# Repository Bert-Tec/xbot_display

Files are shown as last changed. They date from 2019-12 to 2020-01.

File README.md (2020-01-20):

# xbot_display
This repository is about a additional OLED Display for electric scooters using xbot components like ESA 5000 1919 1950 ....

You can use an Arduino Uno for testing. For productive you should use someting smaller like an Arduino pro-mini or ESP-01(s).

For use of ESP-01 please enable it in the xbot_display.ino file, because of custom I2C pins.

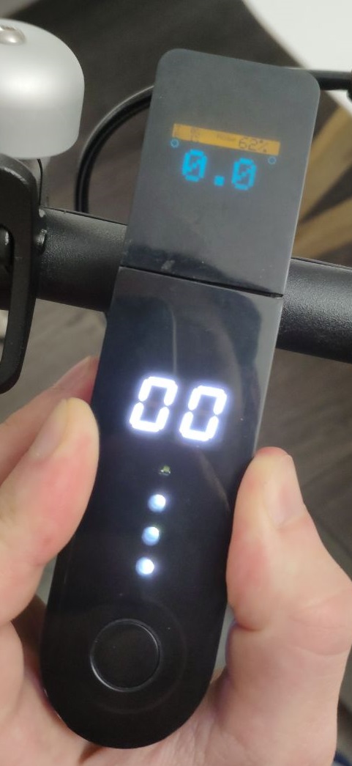
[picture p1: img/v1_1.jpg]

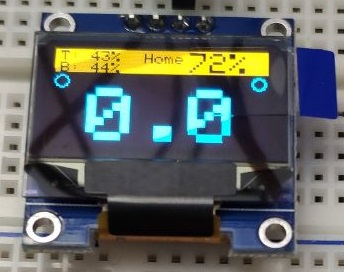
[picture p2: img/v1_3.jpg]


3D printed spacer which also puts the dashboard up, so that it looks good. And so you can secure the spacer with the screws of the dashboard(you'll need new M2x12 screws!):
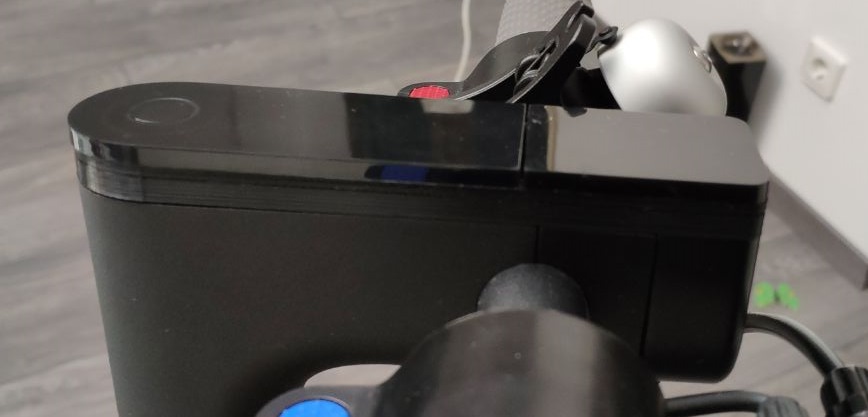
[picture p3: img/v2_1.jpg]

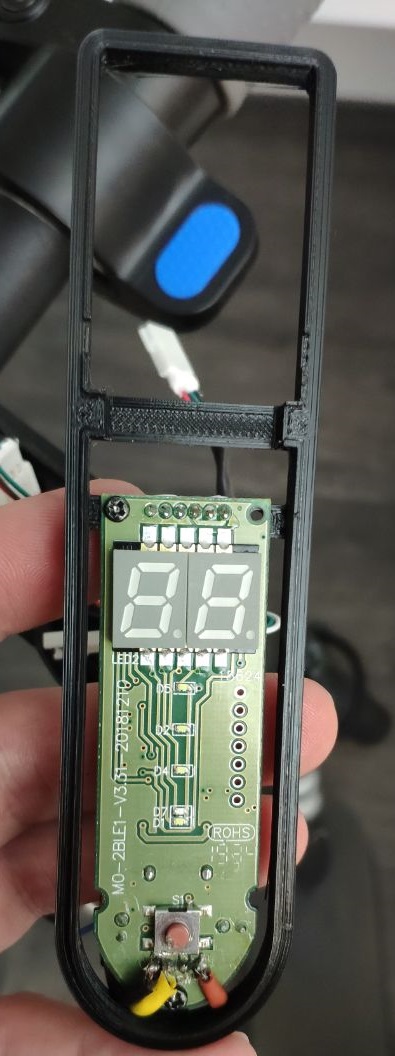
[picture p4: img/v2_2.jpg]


<h3>Dependencies (Arduino libraries):</h3>
<ul>
<li>Adafruit_GFX</li>
<li>Adafruit_SSD1306</li>
<li>Wire</li>
</ul>

<h3>Hardware needed:</h3>
<ul>
<li>1.3"(0.96"works also) OLED display (Yellow/Blue or White)</li>
<li>Arduino pro mini 5V OR ESP-01(s) AND 5V to 3.3V converter</li>
<li>Cables, isolation tape and a small resistor (like 220R)</li>
<li>3D printed spacer(see 3D folder, you'll need 3 new M2x12 screws to secure it well) or mod a housing on your own</li>
<li>optional some hot glue to hold stuff in place</li>
</ul>

<h3>How to connect:</h3>

You need to solder three wires to the dashboards lower pins. Power(5V) to the + pin, Ground to the - pin and the serial line to the tr pin. 
<br>
Then connect Arduino/ESP(you need a power converter from 5V to 3.3V for ESP) and Display to power and ground. 
<br>
Then connect serial line to RX pin of Arduino/ESP and using a resistor (for best work a diode) to TX.
<br>
Then connect I2C cables to OLED and I2C pins(SDA,SCL) of Arduino or to pin 0 and 2 of ESP.
<br>
Now turn on and test it.

<h3>How to Use:</h3>
The display and Arduino/ESP only gets power when the scooter is turned on.
<br>
You can switch to max. speed of 30 kmh by holding break and throttle for 7 seconds and at speed of 0. For reset hold break and throttle for 2 seconds and at speed of 0.
There are three different display mods at the moment. You can switch between them by pressing full throttle for 0.75 second at speed of 0:

<ul>
<li>Home (Displays throttle and break values in % on top left, Battery % in top right, speed in km/h in the center, left point is eco mode on/off right point is light on/off and the middle is 30km/h mode on/off)</li>
<li>Throttle overview (Here you can test and visualize throttle and break)</li>
<li>OFF (Displays blank screen)</li>
</ul>

<h3>Future Features:</h3>
<ul>
<li>Trip meter</li>
<li>unlock speed - done</li>
<li>view aditional informations</li>
</ul>

<h1>Disclaimer</h1>
Use on your own risk.
Not street legal in Germany!!!

<h3>Protocol informations:</h3>

Serial

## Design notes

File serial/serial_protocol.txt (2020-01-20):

General:
55 AA (Start of message) xx (length) xx (type) xx (command) xxxxxx xx (checksum2)  xx (checksum1)  
Length = command to end (without checksum)
xx = unknown
--------------------------------------------------------------------------------
Known stuff:

55 AA 07 25 60 xx xx throttle break xx xx ck2 ck1

55 AA 09 27 63 xx xx throttle break xx xx xx xx ck2 ck1

55 AA 0b 28 6d xx ECO batteryPoints light xx speed2 speed1 xx(?beep request) xx Battery% ck2 ck1

55 AA 04 22 01 xx maxWeehlspeed2 maxWeehlspeed1 ck2 ck1
55 AA 04 22 01 F2 F3 02 F1 FD --> 755 rpm = 30.60 kmh 
55 aa 04 22 01 F2 F8 01 ED FD --> 504 rpm = 20.43 kmh 

set eco mode on/off
                  01 = 0n 
55 AA 04 22 01 7C 01 00 5B FF
                  00 = 0ff 
55 AA 04 22 01 7C 00 00 5C FF

set lock mode on/off
                  01 = 0n 
55 AA 04 22 01 7D 01 00 5A FF
                  00 = 0ff 
55 AA 04 22 01 7D 00 00 5B FF

set light on/off
                  01 = 0n 
55 AA 04 22 01 F0 01 00 E7 FE
                  00 = 0ff 
55 AA 04 22 01 F0 00 00 E8 FE

two different messages, beginns with 55 AA 34 11 33 or 55 AA 34 11 33 28!!!
55 AA 34 11 33 00 93 6B 00 00 00 00 00 00 00 00 00 00 00 00 00 00 11 00 00 00 00 00 00 00 00 00 00 00 00 00 00 00 00 00 00 00 00 00 00 00 00 00 93 0E 18 00 00 00 00 00 BF FD
55 AA 34 11 33 t3 t2 t1 xx xx xx xx xx xx xx xx xx xx xx xx tx ty tz xx xx xx xx xx xx xx xx xx xx xx xx xx xx xx xx xx xx xx xx xx xx xx xx xx v2 v1 c2 c1 xx xx xx xx ck2 ck1
t1-3 = total time in s
tx-tz = actual time in s
v1-2 = /100 = voltage in V
c1-2 = /100 = current in A

55 AA 34 11 33 28 78 80 00 00 00 00 7D 02 03 00 00 00 00 00 00 00 3B 00 00 00 00 00 00 00 00 00 00 00 00 00 6F 41 00 00 00 00 00 00 00 00 00 00 00 00 00 00 00 00 D4 52 D4 FB 
55 AA 34 11 33 xx xx xx xx xx xx m4 m3 m2 m1 xx xx xx xx xx xx xx BB xx xx xx xx xx xx xx xx xx xx xx o4 o3 o2 o1 xx xx xx xx xx xx xx xx xx xx xx xx xx xx xx t3 t2 t1 ck2 ck1
m1-m4 = mainboard version
o1-o4 = odometer in meter
t1-3 = total time in s
BB = battery in %

-----------------------
Unknown stuf:

55 aa 07 25 64 1f 1c 03 28 28 00 e1 fe

55 aa 07 25 64 1f 1c 03 throttle break 00 e1 fe

55 AA 07 25 64 E9 10 03 28 28 00 23 FE 
55 AA 07 25 64 7E 12 03 28 28 00 8C FE 
55 AA 07 25 64 1F 1C 03 28 28 00 E1 FE 
55 AA 07 25 64 EA 0A 03 28 28 00 28 FE 

??? request 55 AA 34 11 33 messages
55 aa 03 23 00 31 18 90 ff
55 AA 03 23 00 31 18 90 FF

22 - set settings? 

set max rpm speed
55 AA 04 22 01 F2 DA 02 0A FE

eco mode on/off
                  01 = 0n 
55 AA 04 22 01 7C 01 00 5B FF
                  00 = 0ff 
55 AA 04 22 01 7C 00 00 5C FF

lock mode on/off
                  01 = 0n 
55 AA 04 22 01 7D 01 00 5A FF
                  00 = 0ff 
55 AA 04 22 01 7D 00 00 5B FF

light on/off
                  01 = 0n 
55 AA 04 22 01 F0 01 00 E7 FE
                  00 = 0ff 
55 AA 04 22 01 F0 00 00 E8 FE

-------------------------------------

21 - ?request data for info pages
55 AA 04 21 03 6A 80 04 E9 FE 
55 AA 04 21 03 EF 00 00 E8 FE --> allways 3x times with short distance

-------------------------------------

mostly at Start, maybe bluetooth connected/connect?
55 AA 06 F4 06 30 1C 81 18 B5 65 FD

-------------------------------------
mostly while check data in app 
55 AA 08 25 07 BD 6F 00 00 00 00 00 9F FE
55AA082507BD4D0000000000C1FE
55AA082507BD4E0000000000C0FE
55AA082507BD4F0000000000BFFE
55AA082507BD500000000000BEFE
55AA082507BD460000000000C8FE

-------------------------------------

55 AA 0A 2B 09 F8 F8 01 7A 01 00 00 20 4E E7 FC 
55 AA 0A 2B 09 F8 F3 02 7A 01 00 00 20 4E EB FC 

55 AA 0A 2B 09 F8 DA 02 7A 01 00 00 20 4E 04 FD 
55 AA 0A 2B 09 F8 F3 02 7A 01 00 00 20 4E EB FC 
55 AA 0A 2B 09 F8 FB 00 7A 01 00 00 20 4E E5 FC 
55 AA 0A 2B 09 F8 79 01 7A 01 00 00 20 4E 66 FD 
55 AA 0A 2B 09 F8 79 01 7A 01 00 00 20 4E 66 FD 
55 AA 0A 2B 09 F8 75 02 7A 01 00 00 20 4E 69 FD

-------------------------------------

55 AA 0C 29 0B 71 00 00 01 00 00 00 00 00 00 00 4D FF 
55 AA 0C 29 0B E5 00 00 F8 01 7A 01 00 00 20 4E F8 FC 
55 AA 0C 29 0B 71 00 00 01 00 00 00 00 00 00 00 4D FF 
55 AA 0C 29 0B E5 00 00 F8 01 7A 01 00 00 20 4E F8 FC 
55 AA 0C 29 0B E5 00 00 F8 01 7A 01 00 00 20 4E F8 FC 
55 AA 0C 29 0B 71 00 00 01 00 00 00 00 00 00 00 4D FF 
55 AA 0C 29 0B 71 00 00 01 00 00 00 01 00 00 00 4C FF 
55 AA 0C 29 0B 71 00 00 01 00 00 00 00 00 00 00 4D FF 
55 AA 0C 29 0B 71 00 00 01 00 00 00 00 00 00 00 4D FF 

-------------------------------------

                                          ????             20.000
55 AA 12 33 11 FC 00 00 00 00 E6 00 00 00 F8 01 7A 01 00 00 20 4E E5 FB 
55 AA 12 33 11 FC 00 00 00 00 E6 00 00 00 F8 01 7A 01 00 00 20 4E E5 FB 
55 AA 12 33 11 FC 00 00 00 00 E6 00 00 00 F8 01 7A 01 00 00 20 4E E5 FB 
55 AA 12 33 11 FC 00 00 00 00 E6 00 00 00 F8 01 7A 01 00 00 20 4E E5 FB 
55 AA 12 33 11 FC 00 00 00 00 E6 00 00 00 F8 01 7A 01 00 00 20 4E E5 FB 
55 AA 12 33 11 FC 00 00 00 00 E6 00 00 00 F3 02 7A 01 00 00 20 4E E9 FB 
55 AA 12 33 11 FC 00 00 00 00 E6 00 00 00 F3 02 7A 01 00 00 20 4E E9 FB 
55 AA 12 33 11 FC 00 00 00 00 E6 00 00 00 F8 01 7A 01 00 00 20 4E E5 FB 
55 AA 12 33 11 FC 00 00 00 00 E6 00 00 00 F3 02 7A 01 00 00 20 4E E9 FB 
55 AA 12 33 11 FC 00 00 00 00 E6 00 00 00 FB 00 7A 01 01 00 20 4E E2 FB
55 AA 12 33 11 FC 00 00 00 00 E6 00 00 00 FB 00 7A 01 00 00 20 4E E3 FB
55 AA 12 33 11 FC 00 00 00 00 E6 00 00 00 F3 02 7A 01 00 00 20 4E E9 FB

55 AA 12 33 11 FC 00 00 00 00 E6 00 00 00 F8 01 7A 01 00 00 20 4E E5 FB
55 AA 12 33 11 FC 00 00 00 00 E6 00 00 00 F3 02 7A 01 00 00 20 4E E9 FB 
55 AA 12 33 11 FC 00 00 00 00 E6 00 00 00 79 01 7A 01 00 00 20 4E 64 FC 
55 AA 12 33 11 FC 00 00 00 00 E6 00 00 00 75 02 7A 01 00 00 20 4E 67 FC
55 AA 12 33 11 FC 00 00 00 00 E6 00 00 00 F8 01 7A 01 00 00 68 42 A9 FB
55 AA 12 33 11 FC 00 00 00 00 E6 00 00 00 F8 01 7A 01 00 00 20 4E E5 FB

-------------------------------------

55 AA 14 31 13 69 00 00 01 00 00 00 00 00 00 00 00 00 78 80 00 00 00 00 45 FE 
55 AA 14 31 13 69 00 00 01 00 00 00 00 00 00 00 00 00 78 80 00 00 00 00 45 FE 
55 AA 14 31 13 69 00 00 01 00 00 00 00 00 00 00 00 00 78 80 00 00 00 00 45 FE 
55 AA 14 31 13 69 00 00 01 00 00 00 00 00 00 00 00 00 78 80 00 00 00 00 45 FE 
55 AA 14 31 13 69 00 00 01 00 00 00 00 00 00 00 00 00 78 80 00 00 00 00 45 FE 
55 AA 14 31 13 69 00 00 01 00 00 00 01 00 00 00 00 00 78 80 00 00 00 00 44 FE 

-------------------------------------
                                                                  akku?
55 AA 1E 3F 1D 06 78 80 00 00 00 00 7D 02 03 00 00 00 00 00 00 00 3B 00 00 00 00 00 00 00 00 00 00 00 CA FD 
55 AA 1E 3F 1D 06 78 80 00 00 00 00 7D 02 03 00 00 00 00 00 00 00 3B 00 00 00 00 00 00 00 00 00 00 00 CA FD 
55 AA 1E 3F 1D 06 78 80 00 00 00 00 7D 02 03 00 00 00 00 00 00 00 3C 00 00 00 00 00 00 00 00 00 00 00 C9 FD 

-------------------------------------

two different messages!!!

55 AA 34 11 33 t3 t2 t1 xx xx xx xx xx xx xx xx xx xx xx xx tx ty tz xx xx xx xx xx xx xx xx xx xx xx xx xx xx xx xx xx xx xx xx xx xx xx xx xx v2 v1 c2 c1 xx xx xx xx ck2 ck1
t1-3 = total time in s
tx-tz = actual time in s
v1-2 = /100 = voltage in V
c1-2 = /100 = current in A

55 AA 34 11 33 00 93 6B 00 00 00 00 00 00 00 00 00 00 00 00 00 00 11 00 00 00 00 00 00 00 00 00 00 00 00 00 00 00 00 00 00 00 00 00 00 00 00 00 93 0E 18 00 00 00 00 00 BF FD
55 AA 34 11 33 00 D3 52 00 00 00 00 00 00 00 00 00 00 00 00 00 00 1A 00 00 00 00 00 00 00 00 00 00 00 00 00 00 00 00 00 00 00 00 00 00 00 00 00 BA 0E 00 00 00 00 00 00 80 FD 
55 AA 34 11 33 00 D5 52 00 00 00 00 00 00 00 00 00 00 00 00 00 00 1C 00 00 00 00 00 00 00 00 00 00 00 00 00 00 00 00 00 00 00 00 00 00 00 00 00 BA 0E 01 00 00 00 00 00 7B FD 
55 AA 34 11 33 00 D4 52 00 00 00 00 00 00 00 00 00 00 00 00 00 00 1B 00 00 00 00 00 00 00 00 00 00 00 00 00 00 00 00 00 00 00 00 00 00 00 00 00 BA 0E 01 00 00 00 00 00 7D FD
55 AA 34 11 33 00 4F 6B 00 00 00 00 00 00 00 00 00 00 00 00 00 00 1B 00 00 00 00 00 00 00 00 00 00 00 00 00 00 00 00 00 00 00 00 00 00 00 00 00 93 0E 00 00 00 00 00 00 11 FE

55 AA 34 11 33 xx xx xx xx xx xx m4 m3 m2 m1 xx xx xx xx xx xx xx BB xx xx xx xx xx xx xx xx xx xx xx o4 o3 o2 o1 xx xx xx xx xx xx xx xx xx xx xx xx xx xx xx t3 t2 t1 ck2 ck1
m1-m4 = mainboard version
o1-o4 = odometer in meter
t1-3 = total time in s
BB = battery in %
                                    Mainboard                     akku                                    odometer
55 AA 34 11 33 28 78 80 00 00 00 00 7D 02 03 00 00 00 00 00 00 00 3B 00 00 00 00 00 00 00 00 00 00 00 00 00 6F 41 00 00 00 00 00 00 00 00 00 00 00 00 00 00 00 00 D4 52 D4 FB 
55 AA 34 11 33 28 78 80 00 00 00 00 7D 02 03 00 00 00 00 00 00 00 3B 00 00 00 00 00 00 00 00 00 00 00 00 00 6F 41 00 00 00 00 00 00 00 00 00 00 00 00 00 00 00 00 D3 52 D5 FB 
55 AA 34 11 33 28 78 80 00 00 00 00 7D 02 03 00 00 00 00 00 00 00 3B 00 00 00 00 00 00 00 00 00 00 00 00 00 6F 41 00 00 00 00 00 00 00 00 00 00 00 00 00 00 00 00 D5 52 D3 FB

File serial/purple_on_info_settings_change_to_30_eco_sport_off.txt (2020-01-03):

00003016	2020-01-03 18:38:55,7530478	+5,5502462	IRP_MJ_READ	UP	0x00000102	00 00 00 	...
00003018	2020-01-03 18:38:56,6466055	+0,8934269	IRP_MJ_READ	UP	0x00000102	ff 	.
00003020	2020-01-03 18:38:56,6666242	+0,0198825	IRP_MJ_READ	UP	0x00000102	55 aa 07 25 60 05 04 28 28 00 00 1a ff 	U..%`..((....
00003022	2020-01-03 18:38:56,6889862	+0,0222351	IRP_MJ_READ	UP	0x00000102	55 aa 07 25 60 05 04 28 f8 	U..%`..(.
00003024	2020-01-03 18:38:57,6042677	+0,9151669	IRP_MJ_READ	UP	0x00000102	55 aa 09 27 63 07 06 28 28 00 00 80 04 8b fe 	U..'c..((......
00003026	2020-01-03 18:38:57,6355090	+0,0311219	IRP_MJ_READ	UP	0x00000102	55 aa 07 25 60 05 04 28 28 00 00 1a ff 	U..%`..((....
00003028	2020-01-03 18:38:57,9248639	+0,2892538	IRP_MJ_READ	UP	0x00000102	94 09 00 1a ff 	.....
00003030	2020-01-03 18:38:57,9871611	+0,0621513	IRP_MJ_READ	UP	0x00000102	55 aa 09 27 63 07 06 28 28 00 00 80 04 8b fe 55 aa 07 25 60 …	U..'c..((......U..%`…
00003032	2020-01-03 18:38:58,0184054	+0,0311249	IRP_MJ_READ	UP	0x00000102	55 aa 07 25 60 05 04 28 28 00 00 1a ff 	U..%`..((....
00003034	2020-01-03 18:38:58,7481416	+0,7296258	IRP_MJ_READ	UP	0x00000102	f5 0b 28 6d 09 00 03 00 00 00 00 00 00 3b 18 ff 55 aa 07 25 …	..(m.........;..U..%…
00003036	2020-01-03 18:38:58,7734854	+0,0252202	IRP_MJ_READ	UP	0x00000102	55 aa 07 25 60 05 04 28 28 00 00 1a ff 	U..%`..((....
00003038	2020-01-03 18:38:58,7974907	+0,0239105	IRP_MJ_READ	UP	0x00000102	55 aa 07 25 60 05 04 28 28 00 00 1a ff 	U..%`..((....
00003040	2020-01-03 18:38:58,8421766	+0,0445723	IRP_MJ_READ	UP	0x00000102	55 aa 09 27 63 07 06 28 28 00 00 80 04 8b fe 55 aa 0b 28 6d …	U..'c..((......U..(m…
00003042	2020-01-03 18:38:58,8661759	+0,0239009	IRP_MJ_READ	UP	0x00000102	55 aa 07 25 60 05 04 28 28 00 00 1a ff 	U..%`..((....
00003044	2020-01-03 18:38:58,8901762	+0,0238960	IRP_MJ_READ	UP	0x00000102	55 aa 07 25 60 05 04 28 28 00 00 1a ff 	U..%`..((....
00003046	2020-01-03 18:38:59,8844301	+0,9941418	IRP_MJ_READ	UP	0x00000102	55 aa 07 25 60 ff 	U..%`.
00003048	2020-01-03 18:38:59,9758012	+0,0912508	IRP_MJ_READ	UP	0x00000102	94 09 00 1a ff 55 aa 0b 28 6d 09 00 03 00 00 00 00 00 00 3b …	.....U..(m.........;…
00003050	2020-01-03 18:39:00,0420099	+0,0660759	IRP_MJ_READ	UP	0x00000102	55 aa 07 25 60 05 04 28 28 00 00 1a ff 55 aa 09 27 63 07 06 …	U..%`..((....U..'c..…
00003052	2020-01-03 18:39:00,0751958	+0,0330779	IRP_MJ_READ	UP	0x00000102	55 aa 07 25 60 05 04 28 28 00 00 1a ff 	U..%`..((....
00003054	2020-01-03 18:39:01,2675521	+1,1922731	IRP_MJ_READ	UP	0x00000102	55 aa 0b 28 6d 09 00 03 00 00 00 00 00 00 3b 18 ff 55 aa 07 …	U..(m.........;..U..…
00003056	2020-01-03 18:39:01,4568222	+0,1891754	IRP_MJ_READ	UP	0x00000102	55 aa 07 25 60 05 04 28 28 00 00 1a ff 55 aa 07 25 60 05 04 …	U..%`..((....U..%`..…
00003058	2020-01-03 18:39:01,5718833	+0,1149814	IRP_MJ_READ	UP	0x00000102	55 aa 07 25 60 05 04 28 28 00 00 1a ff 55 aa 07 25 60 05 04 …	U..%`..((....U..%`..…
00003060	2020-01-03 18:39:01,6567012	+0,0847076	IRP_MJ_READ	UP	0x00000102	55 aa 07 25 60 05 04 28 28 00 00 1a ff 55 aa 07 25 60 05 04 …	U..%`..((....U..%`..…
00003062	2020-01-03 18:39:02,3616581	+0,7048353	IRP_MJ_READ	UP	0x00000102	55 aa 07 25 60 05 04 28 28 00 00 1a ff 55 aa 0b 28 6d 09 00 …	U..%`..((....U..(m..…
00003064	2020-01-03 18:39:02,4084642	+0,0466933	IRP_MJ_READ	UP	0x00000102	55 aa 07 25 60 05 04 28 28 00 00 1a ff 55 aa 09 27 63 07 06 …	U..%`..((....U..'c..…
00003066	2020-01-03 18:39:03,2716396	+0,8631149	IRP_MJ_READ	UP	0x00000102	55 aa 07 25 60 05 04 28 28 00 00 1a ff 	U..%`..((....
00003068	2020-01-03 18:39:03,3704131	+0,0986633	IRP_MJ_READ	UP	0x00000102	55 aa 07 25 60 05 04 28 28 00 00 1a ff 55 aa 0b 28 6d 09 00 …	U..%`..((....U..(m..…
00003070	2020-01-03 18:39:03,7474326	+0,3769105	IRP_MJ_READ	UP	0x00000102	55 aa 07 25 60 05 04 28 28 00 00 1a ff 	U..%`..((....
00003072	2020-01-03 18:39:03,8418210	+0,0942863	IRP_MJ_READ	UP	0x00000102	42 d2 1d 06 28 28 00 00 80 04 8b fe 	B...((......
00003074	2020-01-03 18:39:03,8658208	+0,0238807	IRP_MJ_READ	UP	0x00000102	55 fa 95 60 05 04 28 28 00 00 1a ff 	U..`..((....
00003076	2020-01-03 18:39:05,2085827	+1,3426681	IRP_MJ_READ	UP	0x00000102	55 aa 0b 28 6d 09 00 03 00 00 00 00 00 00 3b 18 ff 55 aa 07 …	U..(m.........;..U..…
00003078	2020-01-03 18:39:05,2610539	+0,0523561	IRP_MJ_READ	UP	0x00000102	55 aa 07 25 60 05 04 28 28 00 00 1a ff 55 b5 50 12 15 04 28 …	U..%`..((....U.P...(…
00003080	2020-01-03 18:39:05,2960023	+0,0347389	IRP_MJ_READ	UP	0x00000102	55 aa 09 27 63 07 06 28 28 00 00 80 04 8b fe 	U..'c..((......
00003082	2020-01-03 18:39:05,5417760	+0,2456743	IRP_MJ_READ	UP	0x00000102	11 28 28 00 00 1a ff 	.((....
00003084	2020-01-03 18:39:05,5684034	+0,0265095	IRP_MJ_READ	UP	0x00000102	55 aa 07 25 60 05 04 28 28 00 00 1a ff 	U..%`..((....
00003086	2020-01-03 18:39:05,6004034	+0,0319116	IRP_MJ_READ	UP	0x00000102	55 aa 07 25 60 05 04 28 28 00 00 1a ff 55 aa 0b 28 6d 09 00 …	U..%`..((....U..(m..…
00003088	2020-01-03 18:39:05,6217296	+0,0212152	IRP_MJ_READ	UP	0x00000102	55 aa 07 25 60 05 04 28 28 00 00 1a ff 	U..%`..((....
00003090	2020-01-03 18:39:05,7097330	+0,0879145	IRP_MJ_READ	UP	0x00000102	55 aa 07 25 60 05 04 28 28 00 00 1a ff 55 aa 0b 28 6d 09 00 …	U..%`..((....U..(m..…
00003092	2020-01-03 18:39:05,7337301	+0,0238884	IRP_MJ_READ	UP	0x00000102	55 aa 07 25 60 05 04 28 28 00 00 1a ff 	U..%`..((....
00003094	2020-01-03 18:39:05,7990815	+0,0652364	IRP_MJ_READ	UP	0x00000102	55 aa 07 25 60 05 04 28 28 00 00 1a ff 55 aa 0b 28 6d 09 00 …	U..%`..((....U..(m..…
00003096	2020-01-03 18:39:05,8310837	+0,0318768	IRP_MJ_READ	UP	0x00000102	55 aa 07 25 60 05 04 28 28 00 00 1a ff 	U..%`..((....
00003098	2020-01-03 18:39:05,8564621	+0,0252556	IRP_MJ_READ	UP	0x00000102	55 aa 07 25 60 fd 	U..%`.
00003100	2020-01-03 18:39:05,9044740	+0,0478971	IRP_MJ_READ	UP	0x00000102	55 aa 09 27 63 07 06 28 28 00 00 80 04 8b fe 55 aa 0b 28 6d …	U..'c..((......U..(m…
00003102	2020-01-03 18:39:05,9241376	+0,0195553	IRP_MJ_READ	UP	0x00000102	55 aa 07 25 60 05 04 28 28 00 00 1a ff 	U..%`..((....
00003104	2020-01-03 18:39:05,9494252	+0,0251825	IRP_MJ_READ	UP	0x00000102	55 aa 07 25 60 05 04 28 28 00 00 1a ff 	U..%`..((....
00003106	2020-01-03 18:39:05,9734376	+0,0238985	IRP_MJ_READ	UP	0x00000102	55 aa 07 25 60 05 04 28 28 00 00 1a ff 	U..%`..((....
00003108	2020-01-03 18:39:05,9974257	+0,0238807	IRP_MJ_READ	UP	0x00000102	55 aa 09 27 e3 	U..'.
00003110	2020-01-03 18:39:06,1661404	+0,1686121	IRP_MJ_READ	UP	0x00000102	55 aa 07 25 60 05 04 28 28 00 00 1a ff 	U..%`..((....
00003112	2020-01-03 18:39:06,1861357	+0,0198945	IRP_MJ_READ	UP	0x00000102	fd 	.
00003114	2020-01-03 18:39:06,2846020	+0,0983755	IRP_MJ_READ	UP	0x00000102	55 aa 07 25 60 05 04 28 28 00 00 1a ff 	U..%`..((....
00003116	2020-01-03 18:39:06,3086011	+0,0238742	IRP_MJ_READ	UP	0x00000102	55 aa 07 25 60 05 04 28 28 00 00 1a ff 	U..%`..((....
00003118	2020-01-03 18:39:06,3326012	+0,0238956	IRP_MJ_READ	UP	0x00000102	55 aa 07 25 60 05 04 28 28 00 00 1a ff 	U..%`..((....
00003120	2020-01-03 18:39:06,3566008	+0,0238997	IRP_MJ_READ	UP	0x00000102	55 aa 09 27 63 07 06 28 28 00 00 80 04 8b fe 	U..'c..((......
00003122	2020-01-03 18:39:06,7922088	+0,4355051	IRP_MJ_READ	UP	0x00000102	55 aa 07 25 60 05 04 28 28 00 00 1a ff 55 aa 0b 28 6d 09 00 …	U..%`..((....U..(m..…
00003124	2020-01-03 18:39:06,8122083	+0,0198766	IRP_MJ_READ	UP	0x00000102	55 aa 07 25 60 05 04 28 28 00 00 1a ff 	U..%`..((....
00003126	2020-01-03 18:39:06,9581673	+0,1458533	IRP_MJ_READ	UP	0x00000102	55 aa 09 27 63 07 06 28 28 00 00 80 04 8b fe 	U..'c..((......
00003128	2020-01-03 18:39:06,9999493	+0,0416488	IRP_MJ_READ	UP	0x00000102	55 ba 07 25 60 05 04 28 28 00 00 1a ff 00 03 00 00 00 00 00 …	U..%`..((...........…
00003130	2020-01-03 18:39:07,0239440	+0,0238848	IRP_MJ_READ	UP	0x00000102	55 aa 07 25 60 05 04 28 28 00 00 1a ff 	U..%`..((....
00003132	2020-01-03 18:39:07,0519083	+0,0278732	IRP_MJ_READ	UP	0x00000102	55 aa 07 25 60 05 04 28 28 00 00 1a ff 	U..%`..((....
00003134	2020-01-03 18:39:07,1460535	+0,0940569	IRP_MJ_READ	UP	0x00000102	55 aa 09 27 63 07 06 28 28 00 00 80 04 8b fe 55 aa 0b 28 6d …	U..'c..((......U..(m…
00003136	2020-01-03 18:39:07,1795096	+0,0333511	IRP_MJ_READ	UP	0x00000102	55 aa 07 25 60 05 04 28 28 00 00 1a ff 	U..%`..((....
00003138	2020-01-03 18:39:07,2656815	+0,0860802	IRP_MJ_READ	UP	0x00000102	55 aa 09 27 63 07 06 28 28 00 00 80 04 8b fe 55 aa 0b 28 6d …	U..'c..((......U..(m…
00003140	2020-01-03 18:39:07,3451350	+0,0793501	IRP_MJ_READ	UP	0x00000102	55 aa 07 25 60 05 04 28 28 00 00 1a ff 55 aa 0b 28 6d 09 00 …	U..%`..((....U..(m..…
00003142	2020-01-03 18:39:07,3763816	+0,0311152	IRP_MJ_READ	UP	0x00000102	55 aa 07 25 60 05 04 28 28 00 00 1a ff 	U..%`..((....
00003144	2020-01-03 18:39:07,4319363	+0,0554601	IRP_MJ_READ	UP	0x00000102	f5 	.
00003146	2020-01-03 18:39:07,4559314	+0,0238875	IRP_MJ_READ	UP	0x00000102	55 aa ff 	U..
00003148	2020-01-03 18:39:07,4800252	+0,0240060	IRP_MJ_READ	UP	0x00000102	60 05 04 28 28 00 00 1a ff 	`..((....
00003150	2020-01-03 18:39:07,5292428	+0,0491493	IRP_MJ_READ	UP	0x00000102	f5 07 25 60 05 04 28 28 00 00 1a ff 	..%`..((....
00003152	2020-01-03 18:39:07,5547197	+0,0253659	IRP_MJ_READ	UP	0x00000102	55 aa 09 27 63 07 06 28 28 00 00 80 04 8b fe 	U..'c..((......
00003154	2020-01-03 18:39:07,5737388	+0,0189219	IRP_MJ_READ	UP	0x00000102	55 aa 07 25 60 05 04 28 28 00 00 1a ff 	U..%`..((....
00003156	2020-01-03 18:39:07,6004782	+0,0266519	IRP_MJ_READ	UP	0x00000102	28 28 00 00 1a ff 	((....
00003158	2020-01-03 18:39:07,6257812	+0,0252180	IRP_MJ_READ	UP	0x00000102	55 aa 07 25 60 05 04 28 28 00 00 1a ff 	U..%`..((....
00003160	2020-01-03 18:39:07,6497807	+0,0238953	IRP_MJ_READ	UP	0x00000102	55 aa 07 25 60 05 04 28 28 00 00 1a ff 	U..%`..((....
00003162	2020-01-03 18:39:07,6977849	+0,0479048	IRP_MJ_READ	UP	0x00000102	55 aa 09 27 63 07 06 28 28 00 00 80 04 8b fe 55 aa 0b 28 6d …	U..'c..((......U..(m…
00003164	2020-01-03 18:39:07,7189718	+0,0210763	IRP_MJ_READ	UP	0x00000102	55 aa 07 25 60 05 04 28 28 00 00 1a ff 	U..%`..((....
00003166	2020-01-03 18:39:07,7429689	+0,0238918	IRP_MJ_READ	UP	0x00000102	55 aa 07 25 60 05 04 28 28 00 00 1a ff 	U..%`..((....
00003168	2020-01-03 18:39:07,7669684	+0,0238978	IRP_MJ_READ	UP	0x00000102	55 aa 07 25 60 05 04 28 28 00 00 1a ff 	U..%`..((....
00003170	2020-01-03 18:39:07,8163099	+0,0492481	IRP_MJ_READ	UP	0x00000102	55 aa 09 27 63 07 06 28 28 00 00 80 04 8b fe 55 aa 0b 28 6d …	U..'c..((......U..(m…
00003172	2020-01-03 18:39:07,8403095	+0,0238890	IRP_MJ_READ	UP	0x00000102	55 aa 07 25 60 05 04 28 28 00 00 1a ff 	U..%`..((....
00003174	2020-01-03 18:39:07,8603099	+0,0198974	IRP_MJ_READ	UP	0x00000102	22 28 28 00 00 1a ff 	"((....
00003176	2020-01-03 18:39:07,8963111	+0,0359042	IRP_MJ_READ	UP	0x00000102	55 aa 07 25 60 05 04 28 28 00 00 1a ff 55 aa 0b 28 6d 09 00 …	U..%`..((....U..(m..…
00003178	2020-01-03 18:39:07,9123100	+0,0158915	IRP_MJ_READ	UP	0x00000102	55 aa 09 27 63 07 06 28 28 00 00 80 04 8b fe 	U..'c..((......
00003180	2020-01-03 18:39:07,9363140	+0,0239031	IRP_MJ_READ	UP	0x00000102	55 aa 07 25 60 05 04 28 28 00 00 1a ff 	U..%`..((....
00003182	2020-01-03 18:39:07,9923107	+0,0559047	IRP_MJ_READ	UP	0x00000102	09 00 03 00 00 00 00 00 00 3b 18 ff 	.........;..
00003184	2020-01-03 18:39:08,0083007	+0,0158960	IRP_MJ_READ	UP	0x00000102	55 aa 07 25 60 05 04 28 28 00 00 1a ff 	U..%`..((....
00003186	2020-01-03 18:39:08,0305351	+0,0221663	IRP_MJ_READ	UP	0x00000102	55 aa 09 27 63 07 06 28 28 00 00 80 04 8b fe 	U..'c..((......
00003188	2020-01-03 18:39:08,0518322	+0,0211412	IRP_MJ_READ	UP	0x00000102	55 aa 07 25 60 05 04 28 28 00 00 1a ff 	U..%`..((....
00003190	2020-01-03 18:39:08,1041353	+0,0522055	IRP_MJ_READ	UP	0x00000102	55 aa 07 25 60 05 04 28 28 00 00 1a ff 55 aa 0b 28 6d 09 00 …	U..%`..((....U..(m..…
00003192	2020-01-03 18:39:08,1281412	+0,0239020	IRP_MJ_READ	UP	0x00000102	f5 50 12 15 04 28 28 00 00 1a ff 	.P...((....
00003194	2020-01-03 18:39:08,1467192	+0,0184898	IRP_MJ_READ	UP	0x00000102	55 aa 09 27 63 07 06 28 28 00 00 80 04 8b fe 	U..'c..((......
00003196	2020-01-03 18:39:08,1970160	+0,0501960	IRP_MJ_READ	UP	0x00000102	55 aa 07 25 60 05 04 28 28 00 00 1a ff fd ff 0b 28 6d 09 00 …	U..%`..((.......(m..…
00003198	2020-01-03 18:39:08,2210172	+0,0239056	IRP_MJ_READ	UP	0x00000102	55 aa 07 25 60 05 04 28 28 00 00 1a ff 	U..%`..((....
00003200	2020-01-03 18:39:08,2474148	+0,0263078	IRP_MJ_READ	UP	0x00000102	55 aa 07 25 60 05 04 28 28 00 00 1a ff 	U..%`..((....
00003202	2020-01-03 18:39:08,2727729	+0,0252514	IRP_MJ_READ	UP	0x00000102	55 aa 09 27 63 07 06 28 28 00 00 80 04 8b fe 	U..'c..((......
00003204	2020-01-03 18:39:08,3179761	+0,0451028	IRP_MJ_READ	UP	0x00000102	55 aa 07 25 60 05 04 28 28 00 00 1a ff 	U..%`..((....
00003206	2020-01-03 18:39:08,3419574	+0,0238783	IRP_MJ_READ	UP	0x00000102	55 aa 07 25 60 05 04 28 28 00 00 1a ff 	U..%`..((....
00003208	2020-01-03 18:39:08,3659595	+0,0239055	IRP_MJ_READ	UP	0x00000102	55 aa 07 25 60 05 04 28 28 00 00 1a ff 	U..%`..((....
00003210	2020-01-03 18:39:08,4163022	+0,0502428	IRP_MJ_READ	UP	0x00000102	55 aa 09 27 63 07 06 28 28 00 00 80 04 8b fe 55 aa 0b 28 6d …	U..'c..((......U..(m…
00003212	2020-01-03 18:39:08,7952695	+0,3788618	IRP_MJ_READ	UP	0x00000102	55 aa 07 25 60 05 04 28 28 00 00 1a ff 	U..%`..((....
00003214	2020-01-03 18:39:08,8192732	+0,0238914	IRP_MJ_READ	UP	0x00000102	55 aa 07 25 60 05 04 28 28 00 00 1a ff 	U..%`..((....
00003216	2020-01-03 18:39:08,8430030	+0,0236309	IRP_MJ_READ	UP	0x00000102	55 aa 07 25 e0 05 04 28 28 00 00 1a ff 	U..%...((....
00003218	2020-01-03 18:39:08,8671536	+0,0240717	IRP_MJ_READ	UP	0x00000102	55 aa 09 27 63 07 06 28 28 00 00 80 	U..'c..((...
00003220	2020-01-03 18:39:08,8894693	+0,0222062	IRP_MJ_READ	UP	0x00000102	10 09 09 00 1a ff 	......
00003222	2020-01-03 18:39:08,9134673	+0,0239003	IRP_MJ_READ	UP	0x00000102	55 aa 07 25 60 05 04 28 28 00 00 1a ff 	U..%`..((....
00003224	2020-01-03 18:39:08,9374676	+0,0239022	IRP_MJ_READ	UP	0x00000102	55 aa 07 25 60 05 04 28 28 00 00 1a ff 	U..%`..((....
00003226	2020-01-03 18:39:08,9647137	+0,0271540	IRP_MJ_READ	UP	0x00000102	55 aa 07 25 60 05 04 28 28 00 00 1a ff 	U..%`..((....
00003228	2020-01-03 18:39:09,0106131	+0,0458249	IRP_MJ_READ	UP	0x00000102	55 aa 09 27 63 07 06 28 28 00 00 80 04 8b fe 55 aa 0b 28 6d …	U..'c..((......U..(m…
00003230	2020-01-03 18:39:09,0321296	+0,0214135	IRP_MJ_READ	UP	0x00000102	b0 41 10 09 09 00 1a ff 	.A......
00003232	2020-01-03 18:39:09,0568022	+0,0245763	IRP_MJ_READ	UP	0x00000102	55 aa 07 25 60 05 04 28 28 00 00 1a ff 	U..%`..((....
00003234	2020-01-03 18:39:09,1163887	+0,0594780	IRP_MJ_READ	UP	0x00000102	55 aa 07 25 60 05 04 28 28 00 00 1a ff 55 aa 0b 28 6d 09 00 …	U..%`..((....U..(m..…
00003236	2020-01-03 18:39:09,1822177	+0,0657242	IRP_MJ_READ	UP	0x00000102	55 ea 60 05 04 28 28 00 00 1a ff 	U.`..((....
00003238	2020-01-03 18:39:09,2529186	+0,0705922	IRP_MJ_READ	UP	0x00000102	fd 55 aa 07 25 60 05 04 28 28 00 00 1a ff 	.U..%`..((....
00003240	2020-01-03 18:39:09,2858038	+0,0327810	IRP_MJ_READ	UP	0x00000102	55 aa 07 25 60 05 04 28 28 00 00 1a ff 	U..%`..((....
00003242	2020-01-03 18:39:09,3870897	+0,1011946	IRP_MJ_READ	UP	0x00000102	f0 00 00 00 00 00 00 3b 18 ff 	.......;..
00003244	2020-01-03 18:39:10,3075433	+0,9203648	IRP_MJ_READ	UP	0x00000102	55 aa 07 25 60 05 04 28 28 00 00 1a ff 55 aa 0b 28 6d 09 00 …	U..%`..((....U..(m..…
00003246	2020-01-03 18:39:10,4689253	+0,1612749	IRP_MJ_READ	UP	0x00000102	55 aa 07 25 60 05 04 28 28 00 00 1a ff 	U..%`..((....
00003248	2020-01-03 18:39:10,6158187	+0,1468215	IRP_MJ_READ	UP	0x00000102	55 aa 07 25 60 05 04 28 28 00 00 1a ff 	U..%`..((....
00003250	2020-01-03 18:39:10,6386940	+0,0227857	IRP_MJ_READ	UP	0x00000102	55 aa 07 25 60 05 04 28 28 00 00 1a ff 	U..%`..((....
00003252	2020-01-03 18:39:10,6844969	+0,0457367	IRP_MJ_READ	UP	0x00000102	55 aa 09 27 63 07 06 28 28 00 00 80 04 8b fe 55 aa 0b 28 6d …	U..'c..((......U..(m…
00003254	2020-01-03 18:39:10,8252825	+0,1406805	IRP_MJ_READ	UP	0x00000102	55 aa 07 25 60 05 04 28 28 00 00 1a ff 	U..%`..((....
00003256	2020-01-03 18:39:10,8506218	+0,0252239	IRP_MJ_READ	UP	0x00000102	55 aa 07 25 60 05 04 28 28 00 00 1a ff 	U..%`..((....
00003258	2020-01-03 18:39:10,8826129	+0,0318834	IRP_MJ_READ	UP	0x00000102	55 aa 07 25 60 05 04 28 28 00 00 1a ff 55 aa 0b 28 6d 09 00 …	U..%`..((....U..(m..…
00003260	2020-01-03 18:39:10,8999104	+0,0171961	IRP_MJ_READ	UP	0x00000102	55 aa 09 27 63 07 06 28 28 00 00 80 04 8b fe 	U..'c..((......
00003262	2020-01-03 18:39:10,9239111	+0,0239376	IRP_MJ_READ	UP	0x00000102	55 aa 07 25 60 05 04 28 28 00 00 1a ff 	U..%`..((....
00003264	2020-01-03 18:39:10,9479059	+0,0239085	IRP_MJ_READ	UP	0x00000102	55 aa 07 25 60 05 04 28 28 00 00 1a ff 	U..%`..((....
00003266	2020-01-03 18:39:10,9816897	+0,0336817	IRP_MJ_READ	UP	0x00000102	55 aa 07 25 60 05 04 28 28 00 00 1a ff 55 aa 0b 28 6d 09 00 …	U..%`..((....U..(m..…
00003268	2020-01-03 18:39:11,5968527	+0,6150718	IRP_MJ_READ	UP	0x00000102	55 aa 07 25 60 05 04 28 28 00 00 1a ff 	U..%`..((....
00003270	2020-01-03 18:39:11,6181428	+0,0211878	IRP_MJ_READ	UP	0x00000102	55 aa 09 27 63 07 06 28 28 00 00 80 04 8b fe 	U..'c..((......
00003272	2020-01-03 18:39:11,6421394	+0,0239087	IRP_MJ_READ	UP	0x00000102	55 aa 07 25 60 05 04 28 28 00 00 1a ff 	U..%`..((....
00003274	2020-01-03 18:39:11,6678748	+0,0256323	IRP_MJ_READ	UP	0x00000102	55 aa 07 25 60 05 04 28 28 00 00 1a ff 	U..%`..((....
00003276	2020-01-03 18:39:12,1960067	+0,5280175	IRP_MJ_READ	UP	0x00000102	55 aa 07 25 60 05 04 28 28 00 00 1a ff 	U..%`..((....
00003278	2020-01-03 18:39:12,2160088	+0,0198654	IRP_MJ_READ	UP	0x00000102	55 aa 09 27 63 07 06 28 28 00 00 80 04 8b fe 	U..'c..((......
00003280	2020-01-03 18:39:12,2383538	+0,0222495	IRP_MJ_READ	UP	0x00000102	55 aa 07 25 60 05 04 28 28 00 00 1a ff 	U..%`..((....
00003282	2020-01-03 18:39:12,2902759	+0,0518333	IRP_MJ_READ	UP	0x00000102	55 aa 07 25 60 05 04 28 28 00 00 1a ff 55 aa 0b 28 6d 09 00 …	U..%`..((....U..(m..…
00003284	2020-01-03 18:39:12,3142801	+0,0239054	IRP_MJ_READ	UP	0x00000102	55 aa 07 25 60 05 04 28 28 00 00 1a ff 	U..%`..((....
00003286	2020-01-03 18:39:12,3342775	+0,0199000	IRP_MJ_READ	UP	0x00000102	55 aa 09 27 63 07 06 28 28 00 00 80 04 	U..'c..((....
00003288	2020-01-03 18:39:12,8366601	+0,5022931	IRP_MJ_READ	UP	0x00000102	55 aa 07 25 60 05 04 28 28 00 00 1a ff 	U..%`..((....
00003290	2020-01-03 18:39:12,8862058	+0,0494313	IRP_MJ_READ	UP	0x00000102	55 aa 07 25 60 05 04 28 28 00 00 1a ff 55 aa 0b 28 6d 09 00 …	U..%`..((....U..(m..…
00003292	2020-01-03 18:39:12,9061699	+0,0197039	IRP_MJ_READ	UP	0x00000102	55 aa 07 25 60 05 04 28 28 00 00 1a ff 	U..%`..((....
00003294	2020-01-03 18:39:13,3165033	+0,4102365	IRP_MJ_READ	UP	0x00000102	55 aa 07 25 60 05 04 28 28 00 00 1a ff 	U..%`..((....
00003296	2020-01-03 18:39:13,3405026	+0,0238831	IRP_MJ_READ	UP	0x00000102	55 aa 07 25 60 05 04 28 28 00 00 1a ff 	U..%`..((....
00003298	2020-01-03 18:39:13,3765129	+0,0359141	IRP_MJ_READ	UP	0x00000102	55 aa 07 25 60 05 04 28 28 00 00 1a ff 55 aa 0b 28 6d 09 00 …	U..%`..((....U..(m..…
00003300	2020-01-03 18:39:13,3925984	+0,0159748	IRP_MJ_READ	UP	0x00000102	55 aa 07 25 60 05 04 28 28 00 00 1a ff 	U..%`..((....
00003302	2020-01-03 18:39:13,4128453	+0,0201494	IRP_MJ_READ	UP	0x00000102	55 aa 09 27 63 07 06 28 28 00 00 80 04 8b fe 	U..'c..((......
00003304	2020-01-03 18:39:13,4365021	+0,0235552	IRP_MJ_READ	UP	0x00000102	55 aa 07 25 60 05 04 28 28 00 00 1a ff 	U..%`..((....
00003306	2020-01-03 18:39:13,4865247	+0,0499192	IRP_MJ_READ	UP	0x00000102	55 aa 07 25 60 05 04 28 28 00 00 1a ff 55 aa 0b 28 6d 09 00 …	U..%`..((....U..(m..…
00003308	2020-01-03 18:39:13,5046862	+0,0180549	IRP_MJ_READ	UP	0x00000102	55 aa 07 25 60 05 04 28 28 00 00 1a ff 	U..%`..((....
00003310	2020-01-03 18:39:13,5286776	+0,0238862	IRP_MJ_READ	UP	0x00000102	55 aa 09 27 63 07 06 28 28 00 00 80 04 8b fe 	U..'c..((......
00003312	2020-01-03 18:39:13,7251873	+0,1964122	IRP_MJ_READ	UP	0x00000102	55 aa 07 25 60 05 04 28 28 00 00 1a ff 	U..%`..((....
00003314	2020-01-03 18:39:13,7730382	+0,0477499	IRP_MJ_READ	UP	0x00000102	55 aa 07 25 60 05 04 28 28 00 00 1a ff 55 aa 0b 28 6d 09 00 …	U..%`..((....U..(m..…
00003316	2020-01-03 18:39:13,7940995	+0,0210012	IRP_MJ_READ	UP	0x00000102	55 aa 07 25 60 05 04 28 28 00 00 1a ff 	U..%`..((....
00003318	2020-01-03 18:39:13,8180960	+0,0238860	IRP_MJ_READ	UP	0x00000102	55 aa 07 25 60 05 04 28 28 00 00 1a ff 	U..%`..((....
00003320	2020-01-03 18:39:13,8420951	+0,0238993	IRP_MJ_READ	UP	0x00000102	55 aa 07 25 60 05 04 28 28 00 00 1a ff 	U..%`..((....
00003322	2020-01-03 18:39:13,8660953	+0,0239050	IRP_MJ_READ	UP	0x00000102	55 aa 0b 28 6d 09 00 03 00 00 00 00 00 00 3b 18 ff 55 aa 07 …	U..(m.........;..U..…
00003324	2020-01-03 18:39:13,8900965	+0,0239081	IRP_MJ_READ	UP	0x00000102	55 aa 09 27 63 07 06 28 28 00 00 80 04 8b fe 	U..'c..((......
00003326	2020-01-03 18:39:13,9140958	+0,0238854	IRP_MJ_READ	UP	0x00000102	55 aa 07 25 60 05 04 28 28 00 00 1a ff 	U..%`..((....
00003328	2020-01-03 18:39:13,9340944	+0,0199024	IRP_MJ_READ	UP	0x00000102	55 aa 07 25 60 05 04 28 28 00 00 1a ff 	U..%`..((....
00003330	2020-01-03 18:39:13,9740950	+0,0398980	IRP_MJ_READ	UP	0x00000102	55 aa 07 25 60 05 04 28 28 00 00 1a ff 55 aa 0b 28 6d 09 00 …	U..%`..((....U..(m..…
00003332	2020-01-03 18:39:13,9901050	+0,0159080	IRP_MJ_READ	UP	0x00000102	55 aa 07 25 60 05 04 28 28 00 00 1a ff 	U..%`..((....
00003334	2020-01-03 18:39:14,0100972	+0,0198862	IRP_MJ_READ	UP	0x00000102	55 aa 09 27 63 07 06 28 28 00 00 80 04 8b fe 	U..'c..((......
00003336	2020-01-03 18:39:14,0340950	+0,0239010	IRP_MJ_READ	UP	0x00000102	55 aa 07 25 60 05 04 28 28 00 00 1a ff 	U..%`..((....
00003338	2020-01-03 18:39:14,0765772	+0,0423952	IRP_MJ_READ	UP	0x00000102	55 aa 07 25 60 05 04 28 28 00 00 1a ff 	U..%`..((....
00003340	2020-01-03 18:39:14,5331349	+0,4564516	IRP_MJ_READ	UP	0x00000102	55 aa 07 25 60 05 04 28 28 00 00 1a ff 	U..%`..((....
00003342	2020-01-03 18:39:14,5651301	+0,0318734	IRP_MJ_READ	UP	0x00000102	55 aa 07 25 60 05 04 28 28 fc 28 6d 09 00 03 00 00 	U..%`..((.(m.....
00003344	2020-01-03 18:39:14,6344989	+0,0692827	IRP_MJ_READ	UP	0x00000102	25 00 1a ff 	%...
00003346	2020-01-03 18:39:14,6761385	+0,0415297	IRP_MJ_READ	UP	0x00000102	55 aa 07 25 60 05 04 28 28 00 00 1a ff 55 aa 0b 28 6d 09 00 …	U..%`..((....U..(m..…
00003348	2020-01-03 18:39:14,7045951	+0,0283693	IRP_MJ_READ	UP	0x00000102	55 aa 07 25 60 05 04 28 28 00 00 1a ff 	U..%`..((....
00003350	2020-01-03 18:39:14,7269908	+0,0223250	IRP_MJ_READ	UP	0x00000102	55 aa 09 27 63 07 06 28 28 00 00 80 04 8b fe 	U..'c..((......
00003352	2020-01-03 18:39:14,7789265	+0,0518331	IRP_MJ_READ	UP	0x00000102	55 aa 07 25 60 05 04 28 28 00 00 1a ff 55 aa 0b 28 6d 09 00 …	U..%`..((....U..(m..…
00003354	2020-01-03 18:39:14,7989172	+0,0198903	IRP_MJ_READ	UP	0x00000102	55 aa 07 25 60 05 04 28 28 00 00 1a ff 	U..%`..((....
00003356	2020-01-03 18:39:14,8189165	+0,0199167	IRP_MJ_READ	UP	0x00000102	55 aa 07 25 60 05 04 28 28 00 00 1a ff 	U..%`..((....
00003358	2020-01-03 18:39:14,8709170	+0,0519004	IRP_MJ_READ	UP	0x00000102	55 aa 09 27 63 07 06 28 28 00 00 80 04 8b fe 55 aa 0b 28 6d …	U..'c..((......U..(m…
00003360	2020-01-03 18:39:14,8949296	+0,0239143	IRP_MJ_READ	UP	0x00000102	55 aa 07 25 60 05 04 28 28 00 00 1a ff 	U..%`..((....
00003362	2020-01-03 18:39:14,9189178	+0,0238953	IRP_MJ_READ	UP	0x00000102	55 aa 07 25 60 05 04 28 28 00 00 1a ff 	U..%`..((....
00003364	2020-01-03 18:39:14,9629174	+0,0439080	IRP_MJ_READ	UP	0x00000102	55 aa 07 25 60 05 04 28 28 00 00 1a ff 55 aa 0b 28 6d 09 00 …	U..%`..((....U..(m..…
00003366	2020-01-03 18:39:14,9869157	+0,0238936	IRP_MJ_READ	UP	0x00000102	55 aa 07 25 60 05 04 28 28 00 00 1a ff 	U..%`..((....
00003368	2020-01-03 18:39:15,0149183	+0,0278949	IRP_MJ_READ	UP	0x00000102	55 aa 07 25 60 05 04 28 28 00 00 1a ff 	U..%`..((....
00003370	2020-01-03 18:39:15,0641949	+0,0491832	IRP_MJ_READ	UP	0x00000102	55 aa 07 25 60 05 04 28 28 00 00 1a ff 55 aa 0b 28 6d 09 00 …	U..%`..((....U..(m..…
00003372	2020-01-03 18:39:15,4952520	+0,4309518	IRP_MJ_READ	UP	0x00000102	55 aa 07 25 60 05 04 28 28 00 00 1a ff 	U..%`..((....
00003374	2020-01-03 18:39:15,7691827	+0,2738132	IRP_MJ_READ	UP	0x00000102	d5 	.
00003376	2020-01-03 18:39:15,8379017	+0,0685562	IRP_MJ_READ	UP	0x00000102	55 aa 09 27 63 07 06 28 28 00 00 80 04 8b fe 55 aa 07 25 60 …	U..'c..((......U..%`…
00003378	2020-01-03 18:39:16,0467469	+0,2087195	IRP_MJ_READ	UP	0x00000102	55 aa 07 25 60 05 04 28 28 00 00 1a ff 55 aa 09 27 ac 90 10 …	U..%`..((....U..'...…
00003380	2020-01-03 18:39:16,3889142	+0,3420413	IRP_MJ_READ	UP	0x00000102	55 aa 07 25 60 05 04 28 28 00 00 1a ff 84 42 02 00 1a ff 55 …	U..%`..((.....B....U…
00003382	2020-01-03 18:39:16,7112056	+0,3221868	IRP_MJ_READ	UP	0x00000102	25 	%
00003384	2020-01-03 18:39:17,0006387	+0,2893225	IRP_MJ_READ	UP	0x00000102	55 aa 09 27 63 07 06 28 28 00 00 80 04 8b fe 	U..'c..((......
00003386	2020-01-03 18:39:17,0275373	+0,0267813	IRP_MJ_READ	UP	0x00000102	55 aa 07 25 60 05 04 28 28 00 00 1a ff 	U..%`..((....
00003388	2020-01-03 18:39:17,0475346	+0,0198990	IRP_MJ_READ	UP	0x00000102	55 aa 07 25 60 05 04 28 28 00 00 1a ff 	U..%`..((....
00003390	2020-01-03 18:39:17,1234695	+0,0758414	IRP_MJ_READ	UP	0x00000102	8d 1d 06 28 28 00 00 80 04 8b fe 	...((......
00003392	2020-01-03 18:39:17,1703355	+0,0467571	IRP_MJ_READ	UP	0x00000102	55 b5 50 12 15 04 28 28 00 00 1a ff 55 aa 0b 28 6d 09 00 03 …	U.P...((....U..(m...…
00003394	2020-01-03 18:39:17,1905721	+0,0201342	IRP_MJ_READ	UP	0x00000102	55 aa 07 25 60 05 04 28 28 00 00 1a ff 	U..%`..((....
00003396	2020-01-03 18:39:17,2182023	+0,0274819	IRP_MJ_READ	UP	0x00000102	55 aa 07 25 60 05 04 28 28 00 00 1a ff 	U..%`..((....
00003398	2020-01-03 18:39:17,2661922	+0,0478910	IRP_MJ_READ	UP	0x00000102	55 aa 09 27 63 07 06 28 28 00 00 80 04 8b fe 55 aa 0b 28 6d …	U..'c..((......U..(m…
00003400	2020-01-03 18:39:17,5048177	+0,2385207	IRP_MJ_READ	UP	0x00000102	55 aa 07 25 60 05 04 28 28 00 00 1a ff 	U..%`..((....
00003402	2020-01-03 18:39:18,4263081	+0,9213860	IRP_MJ_READ	UP	0x00000102	55 aa 09 27 63 07 06 28 28 00 00 80 04 8b fe 	U..'c..((......
00003404	2020-01-03 18:39:18,5522462	+0,1258318	IRP_MJ_READ	UP	0x00000102	55 aa 07 25 64 1f 1c 03 28 28 00 e1 fe 55 aa 0b 28 6d 09 00 …	U..%d...((...U..(m..…
00003406	2020-01-03 18:39:18,6899554	+0,1376069	IRP_MJ_READ	UP	0x00000102	55 aa 07 25 60 05 04 28 28 00 00 1a ff 55 aa 07 25 60 05 04 …	U..%`..((....U..%`..…
00003408	2020-01-03 18:39:18,7836511	+0,0935928	IRP_MJ_READ	UP	0x00000102	55 aa 09 27 63 07 06 28 28 00 00 80 04 8b fe 55 aa 07 25 60 …	U..'c..((......U..%`…
00003410	2020-01-03 18:39:18,9404832	+0,1567242	IRP_MJ_READ	UP	0x00000102	55 aa 07 25 60 05 04 28 28 00 00 1a ff 55 aa 07 25 60 05 04 …	U..%`..((....U..%`..…
00003412	2020-01-03 18:39:18,9873453	+0,0467632	IRP_MJ_READ	UP	0x00000102	55 aa 07 25 60 05 04 28 4a 00 1a ff 	U..%`..(J...
00003414	2020-01-03 18:39:19,0967059	+0,1092669	IRP_MJ_READ	UP	0x00000102	55 aa 07 25 60 05 04 28 28 00 00 1a ff 	U..%`..((....
00003416	2020-01-03 18:39:19,1926401	+0,0958286	IRP_MJ_READ	UP	0x00000102	55 aa 07 25 60 05 04 28 28 00 00 1a ff 55 aa 07 25 60 05 04 …	U..%`..((....U..%`..…
00003418	2020-01-03 18:39:19,2635279	+0,0707758	IRP_MJ_READ	UP	0x00000102	55 aa 07 25 60 05 04 28 28 00 00 1a ff 55 aa 07 25 60 05 04 …	U..%`..((....U..%`..…
00003420	2020-01-03 18:39:19,4035247	+0,1398868	IRP_MJ_READ	UP	0x00000102	55 aa 09 27 63 07 06 28 28 00 00 80 04 8b fe 55 aa 07 25 64 …	U..'c..((......U..%d…
00003422	2020-01-03 18:39:19,4534535	+0,0498262	IRP_MJ_READ	UP	0x00000102	55 aa 07 25 60 05 04 28 28 00 00 1a ff 55 aa 0b 28 6d 09 00 …	U..%`..((....U..(m..…
00003424	2020-01-03 18:39:19,5014293	+0,0478566	IRP_MJ_READ	UP	0x00000102	55 aa 07 25 60 05 04 28 28 00 00 1a ff 55 aa 07 25 60 05 04 …	U..%`..((....U..%`..…
00003426	2020-01-03 18:39:19,6755650	+0,1739986	IRP_MJ_READ	UP	0x00000102	55 aa 07 25 64 1f 1c 03 28 28 00 e1 fe 55 aa 1e 3f 1d 06 78 …	U..%d...((...U..?..x…
00003428	2020-01-03 18:39:19,8162069	+0,1405204	IRP_MJ_READ	UP	0x00000102	55 aa 07 25 60 05 04 28 28 00 00 1a ff 55 aa 07 25 60 05 04 …	U..%`..((....U..%`..…
00003430	2020-01-03 18:39:19,8857440	+0,0694509	IRP_MJ_READ	UP	0x00000102	55 aa 07 25 64 1f 1c 03 28 28 00 e1 fe 55 aa 0b 28 6d 09 00 …	U..%d...((...U..(m..…
00003432	2020-01-03 18:39:19,9597063	+0,0738609	IRP_MJ_READ	UP	0x00000102	55 aa 07 25 60 05 04 28 28 00 00 1a ff 55 aa 07 25 64 7e 12 …	U..%`..((....U..%d~.…
00003434	2020-01-03 18:39:20,0065670	+0,0467581	IRP_MJ_READ	UP	0x00000102	55 aa 07 25 60 05 04 28 28 00 00 1a ff 55 aa 07 25 60 05 04 …	U..%`..((....U..%`..…
00003436	2020-01-03 18:39:20,1020897	+0,0954188	IRP_MJ_READ	UP	0x00000102	55 aa 07 25 64 1f 1c 03 28 28 00 e1 fe 55 aa 1e 3f 1d 06 78 …	U..%d...((...U..?..x…
00003438	2020-01-03 18:39:20,2938633	+0,1916690	IRP_MJ_READ	UP	0x00000102	55 aa 07 25 60 05 04 28 28 00 00 1a ff 55 aa 0b 28 6d 09 00 …	U..%`..((....U..(m..…
00003440	2020-01-03 18:39:20,3446291	+0,0506762	IRP_MJ_READ	UP	0x00000102	55 aa 09 27 63 07 06 28 28 00 00 80 04 8b fe 55 aa 0b 28 6d …	U..'c..((......U..(m…
00003442	2020-01-03 18:39:20,4082326	+0,0634962	IRP_MJ_READ	UP	0x00000102	55 aa 07 25 60 05 04 28 28 00 00 1a ff 55 aa 07 25 64 1f 1c …	U..%`..((....U..%d..…
00003444	2020-01-03 18:39:20,4562334	+0,0478925	IRP_MJ_READ	UP	0x00000102	55 aa 07 25 60 05 04 28 28 00 00 1a ff 55 aa 0b 28 6d 09 00 …	U..%`..((....U..(m..…
00003446	2020-01-03 18:39:20,4802298	+0,0239047	IRP_MJ_READ	UP	0x00000102	55 aa 07 25 60 05 04 28 28 00 00 1a ff 	U..%`..((....
00003448	2020-01-03 18:39:20,5802337	+0,0999190	IRP_MJ_READ	UP	0x00000102	55 aa 07 25 64 7e 12 03 28 28 00 8c fe 55 aa 14 31 13 69 00 …	U..%d~..((...U..1.i.…
00003450	2020-01-03 18:39:20,6002337	+0,0199133	IRP_MJ_READ	UP	0x00000102	55 aa 07 25 60 05 04 28 28 00 00 1a ff 	U..%`..((....
00003452	2020-01-03 18:39:20,6493514	+0,0490219	IRP_MJ_READ	UP	0x00000102	55 aa 09 27 63 07 06 28 28 00 00 80 04 8b fe 55 aa 0b 28 6d …	U..'c..((......U..(m…
00003454	2020-01-03 18:39:20,6733546	+0,0239025	IRP_MJ_READ	UP	0x00000102	55 aa 07 25 60 05 04 28 28 00 00 1a ff 	U..%`..((....
00003456	2020-01-03 18:39:20,7453478	+0,0718905	IRP_MJ_READ	UP	0x00000102	55 aa 07 25 64 e9 10 03 28 28 00 23 fe 55 aa 12 33 11 fc 00 …	U..%d...((.#.U..3...…
00003458	2020-01-03 18:39:20,7693518	+0,0238943	IRP_MJ_READ	UP	0x00000102	55 aa 09 27 63 07 06 28 28 00 00 80 04 8b fe 	U..'c..((......
00003460	2020-01-03 18:39:20,7933632	+0,0238969	IRP_MJ_READ	UP	0x00000102	55 aa 07 25 60 05 04 28 28 00 00 1a ff 	U..%`..((....
00003462	2020-01-03 18:39:20,8425059	+0,0490433	IRP_MJ_READ	UP	0x00000102	55 aa 07 25 60 05 04 28 28 00 00 1a ff 55 aa 0b 28 6d 09 00 …	U..%`..((....U..(m..…
00003464	2020-01-03 18:39:20,8665013	+0,0238996	IRP_MJ_READ	UP	0x00000102	55 aa 07 25 60 05 04 28 28 00 00 1a ff 	U..%`..((....
00003466	2020-01-03 18:39:20,8865061	+0,0199026	IRP_MJ_READ	UP	0x00000102	55 aa 09 27 63 07 06 28 28 00 00 80 04 8b fe 	U..'c..((......
00003468	2020-01-03 18:39:20,9447313	+0,0581274	IRP_MJ_READ	UP	0x00000102	55 aa 07 25 64 1f 1c 03 28 28 00 e1 fe 55 aa 1e 3f 1d 06 78 …	U..%d...((...U..?..x…
00003470	2020-01-03 18:39:20,9617955	+0,0169765	IRP_MJ_READ	UP	0x00000102	55 aa 07 25 60 05 04 28 28 00 00 1a ff 	U..%`..((....
00003472	2020-01-03 18:39:20,9857983	+0,0239110	IRP_MJ_READ	UP	0x00000102	55 aa 07 25 60 05 04 28 28 00 00 1a ff 	U..%`..((....
00003474	2020-01-03 18:39:21,0097954	+0,0239082	IRP_MJ_READ	UP	0x00000102	55 aa 07 25 60 05 04 28 28 00 00 1a ff 	U..%`..((....
00003476	2020-01-03 18:39:21,0803950	+0,0705145	IRP_MJ_READ	UP	0x00000102	55 aa 09 27 63 07 06 28 28 00 00 80 04 8b fe 55 aa 0b 28 6d …	U..'c..((......U..(m…
00003478	2020-01-03 18:39:21,1050517	+0,0245623	IRP_MJ_READ	UP	0x00000102	55 aa 07 25 60 05 04 28 28 00 00 1a ff 	U..%`..((....
00003480	2020-01-03 18:39:21,1350645	+0,0299113	IRP_MJ_READ	UP	0x00000102	55 aa 07 25 60 05 04 28 28 00 00 1a ff 55 aa 0b 28 6d 09 00 …	U..%`..((....U..(m..…
00003482	2020-01-03 18:39:21,1535671	+0,0184170	IRP_MJ_READ	UP	0x00000102	55 aa 07 25 64 1f 1c 03 28 28 00 e1 fe 	U..%d...((...
00003484	2020-01-03 18:39:21,6084546	+0,4547866	IRP_MJ_READ	UP	0x00000102	55 aa 07 25 64 7e 12 03 28 28 00 8c fe 	U..%d~..((...
00003486	2020-01-03 18:39:21,7007095	+0,0921383	IRP_MJ_READ	UP	0x00000102	55 aa 07 25 64 1f 1c 03 28 28 00 e1 fe 55 aa 1e 3f 1d 06 78 …	U..%d...((...U..?..x…
00003488	2020-01-03 18:39:21,7527076	+0,0519060	IRP_MJ_READ	UP	0x00000102	55 aa 07 25 60 05 04 28 28 00 00 1a ff 55 aa 0b 28 6d 09 00 …	U..%`..((....U..(m..…
00003490	2020-01-03 18:39:21,7820491	+0,0292415	IRP_MJ_READ	UP	0x00000102	55 aa 09 27 63 07 06 28 28 00 00 80 04 8b fe 	U..'c..((......
00003492	2020-01-03 18:39:21,8020507	+0,0199038	IRP_MJ_READ	UP	0x00000102	55 aa 07 25 60 05 04 28 28 00 00 1a ff 	U..%`..((....
00003494	2020-01-03 18:39:21,8500457	+0,0479021	IRP_MJ_READ	UP	0x00000102	55 aa 07 25 64 e9 10 03 28 28 00 23 fe 55 aa 0b 28 6d 09 00 …	U..%d...((.#.U..(m..…
00003496	2020-01-03 18:39:21,8700447	+0,0199009	IRP_MJ_READ	UP	0x00000102	55 aa 07 25 60 05 04 28 28 00 00 1a ff 	U..%`..((....
00003498	2020-01-03 18:39:21,8940447	+0,0238999	IRP_MJ_READ	UP	0x00000102	55 aa 07 25 60 05 04 28 28 00 00 1a ff 	U..%`..((....
00003500	2020-01-03 18:39:21,9300449	+0,0359051	IRP_MJ_READ	UP	0x00000102	55 aa 09 27 63 07 06 28 28 00 00 80 04 8b fe 55 aa 0b 28 6d …	U..'c..((......U..(m…
00003502	2020-01-03 18:39:21,9460567	+0,0159187	IRP_MJ_READ	UP	0x00000102	55 aa 07 25 60 05 04 28 28 00 00 1a ff 	U..%`..((....
00003504	2020-01-03 18:39:21,9712472	+0,0250809	IRP_MJ_READ	UP	0x00000102	55 aa 07 25 60 05 04 28 28 00 00 1a ff 	U..%`..((....
00003506	2020-01-03 18:39:22,0242386	+0,0528944	IRP_MJ_READ	UP	0x00000102	55 aa 07 25 64 1f 1c 03 28 28 00 e1 fe 55 aa 1e 3f 1d 06 78 …	U..%d...((...U..?..x…
00003508	2020-01-03 18:39:22,0402468	+0,0158969	IRP_MJ_READ	UP	0x00000102	55 aa 07 25 60 05 04 28 28 00 00 1a ff 	U..%`..((....
00003510	2020-01-03 18:39:22,0642371	+0,0238810	IRP_MJ_READ	UP	0x00000102	55 aa 09 27 63 07 06 28 28 00 00 80 04 8b fe 	U..'c..((......
00003512	2020-01-03 18:39:22,1394063	+0,0750670	IRP_MJ_READ	UP	0x00000102	55 aa 07 25 64 7e 12 03 28 28 00 8c fe 55 aa 14 31 13 69 00 …	U..%d~..((...U..1.i.…
00003514	2020-01-03 18:39:22,1593957	+0,0198784	IRP_MJ_READ	UP	0x00000102	55 aa 07 25 60 05 04 28 28 00 00 1a ff 	U..%`..((....
00003516	2020-01-03 18:39:22,2316056	+0,0721162	IRP_MJ_READ	UP	0x00000102	55 aa 07 25 64 1f 1c 03 28 28 00 e1 fe 55 aa 1e 3f 1d 06 78 …	U..%d...((...U..?..x…
00003518	2020-01-03 18:39:22,2556043	+0,0238877	IRP_MJ_READ	UP	0x00000102	55 aa 07 25 60 05 04 28 28 00 00 1a ff 	U..%`..((....
00003520	2020-01-03 18:39:22,2774961	+0,0217890	IRP_MJ_READ	UP	0x00000102	55 aa 07 25 60 05 04 28 28 00 00 1a ff 	U..%`..((....
00003522	2020-01-03 18:39:22,3551095	+0,0775138	IRP_MJ_READ	UP	0x00000102	55 aa 07 25 60 05 04 28 28 00 00 1a ff 55 aa 0b 28 6d 09 00 …	U..%`..((....U..(m..…
00003524	2020-01-03 18:39:22,3791090	+0,0238976	IRP_MJ_READ	UP	0x00000102	55 aa 09 27 63 07 06 28 28 00 00 80 04 8b fe 	U..'c..((......
00003526	2020-01-03 18:39:22,3991081	+0,0199044	IRP_MJ_READ	UP	0x00000102	55 aa 07 25 60 05 04 28 28 00 00 1a ff 	U..%`..((....
00003528	2020-01-03 18:39:22,4471262	+0,0479396	IRP_MJ_READ	UP	0x00000102	55 aa 07 25 60 05 04 28 28 00 00 1a ff 55 aa 0b 28 6d 09 00 …	U..%`..((....U..(m..…
00003530	2020-01-03 18:39:22,4735261	+0,0262996	IRP_MJ_READ	UP	0x00000102	55 aa 07 25 60 05 04 28 28 00 00 1a ff 	U..%`..((....
00003532	2020-01-03 18:39:22,4960370	+0,0224402	IRP_MJ_READ	UP	0x00000102	55 aa 09 27 63 07 06 28 28 00 00 80 04 8b fe 	U..'c..((......
00003534	2020-01-03 18:39:22,5280347	+0,0318961	IRP_MJ_READ	UP	0x00000102	55 aa 07 25 60 05 04 28 28 00 00 1a ff 55 aa 0b 28 6d 09 00 …	U..%`..((....U..(m..…
00003536	2020-01-03 18:39:22,5680346	+0,0399024	IRP_MJ_READ	UP	0x00000102	55 aa 07 25 64 1f 1c 03 28 28 00 e1 fe 55 aa 1e 3f 1d 06 78 …	U..%d...((...U..?..x…
00003538	2020-01-03 18:39:22,5944288	+0,0262883	IRP_MJ_READ	UP	0x00000102	55 aa 07 25 60 05 04 28 28 00 00 1a ff 	U..%`..((....
00003540	2020-01-03 18:39:22,6437578	+0,0492121	IRP_MJ_READ	UP	0x00000102	55 aa 07 25 60 05 04 28 28 00 00 1a ff 55 aa 0b 28 6d 09 00 …	U..%`..((....U..(m..…
00003542	2020-01-03 18:39:22,6637582	+0,0199071	IRP_MJ_READ	UP	0x00000102	55 aa 07 25 60 05 04 28 28 00 00 1a ff 	U..%`..((....
00003544	2020-01-03 18:39:22,6859465	+0,0221013	IRP_MJ_READ	UP	0x00000102	55 aa 07 25 60 05 04 28 28 00 00 1a ff 	U..%`..((....
00003546	2020-01-03 18:39:22,7344931	+0,0484553	IRP_MJ_READ	UP	0x00000102	55 aa 07 25 60 05 04 28 28 00 00 1a ff 55 aa 0b 28 6d 09 00 …	U..%`..((....U..(m..…
00003548	2020-01-03 18:39:22,7584909	+0,0238963	IRP_MJ_READ	UP	0x00000102	55 aa 09 27 63 07 06 28 28 00 00 80 04 8b fe 	U..'c..((......
00003550	2020-01-03 18:39:22,7838206	+0,0252191	IRP_MJ_READ	UP	0x00000102	55 aa 07 25 60 05 04 28 28 00 00 1a ff 	U..%`..((....
00003552	2020-01-03 18:39:22,8478256	+0,0639206	IRP_MJ_READ	UP	0x00000102	55 aa 07 25 64 1f 32 03 28 28 00 cb fe 55 aa 34 11 33 28 78 …	U..%d.2.((...U.4.3(x…
00003554	2020-01-03 18:39:22,8678211	+0,0199009	IRP_MJ_READ	UP	0x00000102	55 aa 07 25 60 05 04 28 28 00 00 1a ff 	U..%`..((....
00003556	2020-01-03 18:39:22,8918204	+0,0239135	IRP_MJ_READ	UP	0x00000102	55 aa 07 25 60 05 04 28 28 00 00 1a ff 	U..%`..((....
00003558	2020-01-03 18:39:22,9238215	+0,0319165	IRP_MJ_READ	UP	0x00000102	55 aa 09 27 63 07 06 28 28 00 00 80 04 8b fe 55 aa 0b 28 6d …	U..'c..((......U..(m…
00003560	2020-01-03 18:39:22,9438204	+0,0199044	IRP_MJ_READ	UP	0x00000102	55 aa 07 25 64 6d 02 03 28 28 00 ad fe 55 aa 04 21 03 6a 80 …	U..%dm..((...U..!.j.…
00003562	2020-01-03 18:39:22,9638206	+0,0199189	IRP_MJ_READ	UP	0x00000102	55 aa 07 25 60 05 04 28 28 00 00 1a ff 	U..%`..((....
00003564	2020-01-03 18:39:22,9918246	+0,0279269	IRP_MJ_READ	UP	0x00000102	55 aa 07 25 60 05 04 28 28 00 00 1a ff 	U..%`..((....
00003566	2020-01-03 18:39:23,0371971	+0,0452638	IRP_MJ_READ	UP	0x00000102	55 aa 07 25 60 05 04 28 28 00 00 1a ff 55 aa 0b 28 6d 09 00 …	U..%`..((....U..(m..…
00003568	2020-01-03 18:39:23,0572007	+0,0199046	IRP_MJ_READ	UP	0x00000102	55 aa 09 27 63 07 06 28 28 00 00 80 04 8b fe 	U..'c..((......
00003570	2020-01-03 18:39:23,1315754	+0,0742668	IRP_MJ_READ	UP	0x00000102	55 aa 07 25 64 37 32 03 28 28 00 b3 fe 55 aa 34 11 33 00 d3 …	U..%d72.((...U.4.3..…
00003572	2020-01-03 18:39:23,1515717	+0,0198872	IRP_MJ_READ	UP	0x00000102	55 aa 07 25 60 05 04 28 28 00 00 1a ff 	U..%`..((....
00003574	2020-01-03 18:39:23,1768111	+0,0251405	IRP_MJ_READ	UP	0x00000102	55 aa 07 25 60 05 04 28 28 00 00 1a ff 	U..%`..((....
00003576	2020-01-03 18:39:23,2275160	+0,0505874	IRP_MJ_READ	UP	0x00000102	55 aa 09 27 63 07 06 28 28 00 00 80 04 8b fe 55 aa 0b 28 6d …	U..'c..((......U..(m…
00003578	2020-01-03 18:39:23,2515140	+0,0238920	IRP_MJ_READ	UP	0x00000102	55 aa 07 25 60 05 04 28 28 00 00 1a ff 	U..%`..((....
00003580	2020-01-03 18:39:23,2752509	+0,0236344	IRP_MJ_READ	UP	0x00000102	55 aa 07 25 60 05 04 28 28 00 00 1a ff 	U..%`..((....
00003582	2020-01-03 18:39:23,3432527	+0,0679136	IRP_MJ_READ	UP	0x00000102	55 aa 07 25 64 be 06 03 28 28 00 58 fe 55 aa 08 25 07 bd 6f …	U..%d...((.X.U..%..o…
00003584	2020-01-03 18:39:23,3712567	+0,0279002	IRP_MJ_READ	UP	0x00000102	55 aa 09 27 63 07 06 28 28 00 00 80 04 8b fe 	U..'c..((......
00003586	2020-01-03 18:39:23,3952427	+0,0238827	IRP_MJ_READ	UP	0x00000102	55 aa 07 25 60 05 04 28 28 00 00 1a ff 	U..%`..((....
00003588	2020-01-03 18:39:23,4432416	+0,0479160	IRP_MJ_READ	UP	0x00000102	55 aa 07 25 60 05 04 28 28 00 00 1a ff 55 aa 0b 28 6d 09 00 …	U..%`..((....U..(m..…
00003590	2020-01-03 18:39:23,4632398	+0,0198748	IRP_MJ_READ	UP	0x00000102	55 aa 07 25 60 05 04 28 28 00 00 1a ff 	U..%`..((....
00003592	2020-01-03 18:39:23,4872546	+0,0239256	IRP_MJ_READ	UP	0x00000102	55 aa 09 27 63 07 06 28 28 00 00 80 04 8b fe 	U..'c..((......
00003594	2020-01-03 18:39:23,5193796	+0,0320000	IRP_MJ_READ	UP	0x00000102	55 aa 07 25 60 05 04 28 28 00 00 1a ff 55 aa 0b 28 6d 09 00 …	U..%`..((....U..(m..…
00003596	2020-01-03 18:39:23,5393830	+0,0199024	IRP_MJ_READ	UP	0x00000102	55 aa 07 25 60 05 04 28 28 00 00 1a ff 	U..%`..((....
00003598	2020-01-03 18:39:23,5633984	+0,0239519	IRP_MJ_READ	UP	0x00000102	55 aa 07 25 60 05 04 28 28 00 00 1a ff 	U..%`..((....
00003600	2020-01-03 18:39:23,6332729	+0,0698093	IRP_MJ_READ	UP	0x00000102	55 aa 07 25 64 1f 32 03 28 28 00 cb fe 55 aa 34 11 33 28 78 …	U..%d.2.((...U.4.3(x…
00003602	2020-01-03 18:39:23,6532794	+0,0199353	IRP_MJ_READ	UP	0x00000102	55 aa 09 27 63 07 06 28 28 00 00 80 04 8b fe 	U..'c..((......
00003604	2020-01-03 18:39:23,6778618	+0,0245233	IRP_MJ_READ	UP	0x00000102	55 aa 07 25 60 05 04 28 28 00 00 1a ff 	U..%`..((....
00003606	2020-01-03 18:39:23,7210828	+0,0431680	IRP_MJ_READ	UP	0x00000102	55 aa 07 25 60 05 04 28 28 00 00 1a ff 55 aa 0b 28 6d 09 00 …	U..%`..((....U..(m..…
00003608	2020-01-03 18:39:23,7535954	+0,0324704	IRP_MJ_READ	UP	0x00000102	55 aa 07 25 64 6d 02 03 28 28 00 ad fe 55 aa 04 21 03 6a 80 …	U..%dm..((...U..!.j.…
00003610	2020-01-03 18:39:23,7696365	+0,0159821	IRP_MJ_READ	UP	0x00000102	55 aa 07 25 60 05 04 28 28 00 00 1a ff 	U..%`..((....
00003612	2020-01-03 18:39:23,7950897	+0,0253966	IRP_MJ_READ	UP	0x00000102	55 aa 09 27 63 07 06 28 28 00 00 80 04 8b fe 	U..'c..((......
00003614	2020-01-03 18:39:23,8269824	+0,0318490	IRP_MJ_READ	UP	0x00000102	55 aa 07 25 60 05 04 28 28 00 00 1a ff 55 aa 0b 28 6d 09 00 …	U..%`..((....U..(m..…
00003616	2020-01-03 18:39:23,8910654	+0,0640408	IRP_MJ_READ	UP	0x00000102	55 aa 07 25 64 37 32 03 28 28 00 b3 fe 55 aa 34 11 33 00 d4 …	U..%d72.((...U.4.3..…
00003618	2020-01-03 18:39:23,9392100	+0,0480803	IRP_MJ_READ	UP	0x00000102	55 aa 07 25 60 05 04 28 28 00 00 1a ff 55 aa 0b 28 6d 09 00 …	U..%`..((....U..(m..…
00003620	2020-01-03 18:39:23,9632089	+0,0239461	IRP_MJ_READ	UP	0x00000102	55 aa 07 25 60 05 04 28 28 00 00 1a ff 	U..%`..((....
00003622	2020-01-03 18:39:23,9872151	+0,0239505	IRP_MJ_READ	UP	0x00000102	55 aa 07 25 60 05 04 28 28 00 00 1a ff 	U..%`..((....
00003624	2020-01-03 18:39:24,0365802	+0,0493095	IRP_MJ_READ	UP	0x00000102	55 aa 07 25 60 05 04 28 28 00 00 1a ff 55 aa 0b 28 6d 09 00 …	U..%`..((....U..(m..…
00003626	2020-01-03 18:39:24,0610773	+0,0244283	IRP_MJ_READ	UP	0x00000102	55 aa 07 25 60 05 04 28 28 00 00 1a ff 	U..%`..((....
00003628	2020-01-03 18:39:24,0826635	+0,0215041	IRP_MJ_READ	UP	0x00000102	55 aa 09 27 63 07 06 28 28 00 00 80 04 8b fe 	U..'c..((......
00003630	2020-01-03 18:39:24,1330526	+0,0503043	IRP_MJ_READ	UP	0x00000102	55 aa 07 25 64 be 06 03 28 28 00 58 fe 55 aa 08 25 f0 00 00 …	U..%d...((.X.U..%...…
00003632	2020-01-03 18:39:24,1570620	+0,0239441	IRP_MJ_READ	UP	0x00000102	55 aa 07 25 60 05 04 28 28 00 00 1a ff 	U..%`..((....
00003634	2020-01-03 18:39:24,1845243	+0,0274151	IRP_MJ_READ	UP	0x00000102	55 aa 07 25 60 05 04 28 28 00 00 1a ff 	U..%`..((....
00003636	2020-01-03 18:39:24,2315216	+0,0468951	IRP_MJ_READ	UP	0x00000102	55 aa 07 25 60 05 04 28 28 00 00 1a ff 55 aa 0b 28 6d 09 00 …	U..%`..((....U..(m..…
00003638	2020-01-03 18:39:24,2484136	+0,0168198	IRP_MJ_READ	UP	0x00000102	55 aa 07 25 60 05 04 28 28 00 00 1a ff 	U..%`..((....
00003640	2020-01-03 18:39:24,2749248	+0,0264010	IRP_MJ_READ	UP	0x00000102	55 aa 07 25 60 05 04 28 28 00 00 1a ff 	U..%`..((....
00003642	2020-01-03 18:39:24,3241511	+0,0491683	IRP_MJ_READ	UP	0x00000102	55 aa 07 25 60 05 04 28 28 00 00 1a ff 55 aa 0b 28 6d 09 00 …	U..%`..((....U..(m..…
00003644	2020-01-03 18:39:24,3494428	+0,0251986	IRP_MJ_READ	UP	0x00000102	55 aa 09 27 63 07 06 28 28 00 00 80 04 8b fe 	U..'c..((......
00003646	2020-01-03 18:39:24,3734439	+0,0239425	IRP_MJ_READ	UP	0x00000102	55 aa 07 25 60 05 04 28 28 00 00 1a ff 	U..%`..((....
00003648	2020-01-03 18:39:24,4374436	+0,0639442	IRP_MJ_READ	UP	0x00000102	55 aa 07 25 64 1f 32 03 28 28 00 cb fe 55 aa 34 11 33 28 78 …	U..%d.2.((...U.4.3(x…
00003650	2020-01-03 18:39:24,4534502	+0,0159458	IRP_MJ_READ	UP	0x00000102	55 aa 07 25 60 05 04 28 28 00 00 1a ff 	U..%`..((....
00003652	2020-01-03 18:39:24,4814366	+0,0279421	IRP_MJ_READ	UP	0x00000102	55 aa 07 25 60 05 04 28 28 00 00 1a ff 	U..%`..((....
00003654	2020-01-03 18:39:24,5334370	+0,0519577	IRP_MJ_READ	UP	0x00000102	55 aa 09 27 63 07 06 28 28 00 00 80 04 8b fe 55 aa 0b 28 6d …	U..'c..((......U..(m…
00003656	2020-01-03 18:39:24,5534417	+0,0199468	IRP_MJ_READ	UP	0x00000102	55 aa 07 25 60 05 04 28 28 00 00 1a ff 	U..%`..((....
00003658	2020-01-03 18:39:24,5734428	+0,0199453	IRP_MJ_READ	UP	0x00000102	55 aa 07 25 60 05 04 28 28 00 00 1a ff 	U..%`..((....
00003660	2020-01-03 18:39:24,6246275	+0,0510961	IRP_MJ_READ	UP	0x00000102	55 aa 07 25 60 05 04 28 28 00 00 1a ff 55 aa 0b 28 6d 09 00 …	U..%`..((....U..(m..…
00003662	2020-01-03 18:39:24,7166324	+0,0919464	IRP_MJ_READ	UP	0x00000102	55 aa 07 25 64 37 32 03 28 28 00 b3 fe 55 aa 34 11 33 00 d5 …	U..%d72.((...U.4.3..…
00003664	2020-01-03 18:39:24,7510946	+0,0343655	IRP_MJ_READ	UP	0x00000102	55 aa 07 25 60 05 04 28 28 00 00 1a ff 	U..%`..((....
00003666	2020-01-03 18:39:24,8003986	+0,0492472	IRP_MJ_READ	UP	0x00000102	55 aa 07 25 60 05 04 28 28 00 00 1a ff 55 aa 03 23 00 31 18 …	U..%`..((....U..#.1.…
00003668	2020-01-03 18:39:24,8897916	+0,0893021	IRP_MJ_READ	UP	0x00000102	55 aa 09 27 63 07 06 28 28 00 00 80 04 8b fe 55 aa 0b 28 6d …	U..'c..((......U..(m…
00003670	2020-01-03 18:39:25,0316669	+0,1418108	IRP_MJ_READ	UP	0x00000102	55 aa 07 25 60 05 04 28 28 00 00 1a ff 55 aa 0b 28 6d 09 00 …	U..%`..((....U..(m..…
00003672	2020-01-03 18:39:25,0629169	+0,0311385	IRP_MJ_READ	UP	0x00000102	55 aa 07 25 60 05 04 28 28 00 00 1a ff 	U..%`..((....
00003674	2020-01-03 18:39:25,1305282	+0,0675541	IRP_MJ_READ	UP	0x00000102	55 aa 09 27 63 07 06 28 28 00 00 80 04 8b fe 55 aa 07 25 60 …	U..'c..((......U..%`…
00003676	2020-01-03 18:39:25,2536504	+0,1228576	IRP_MJ_READ	UP	0x00000102	55 aa 07 25 60 05 04 28 28 00 00 1a ff 55 aa 07 25 60 05 04 …	U..%`..((....U..%`..…
00003678	2020-01-03 18:39:25,3704605	+0,1167434	IRP_MJ_READ	UP	0x00000102	55 aa 07 25 60 05 04 28 28 00 00 1a ff 55 aa 07 25 60 05 04 …	U..%`..((....U..%`..…
00003680	2020-01-03 18:39:25,3888857	+0,0183497	IRP_MJ_READ	UP	0x00000102	55 aa 07 25 60 05 04 28 28 00 00 1a ff 	U..%`..((....
00003682	2020-01-03 18:39:25,4168779	+0,0279343	IRP_MJ_READ	UP	0x00000102	55 aa 0b 28 6d 09 00 03 00 00 00 00 00 00 3b 18 ff 55 aa 07 …	U..(m.........;..U..…
00003684	2020-01-03 18:39:25,4368804	+0,0199584	IRP_MJ_READ	UP	0x00000102	55 aa 07 25 60 05 04 28 28 00 00 1a ff 	U..%`..((....
00003686	2020-01-03 18:39:25,4608836	+0,0239626	IRP_MJ_READ	UP	0x00000102	55 aa 07 25 60 05 04 28 28 00 00 1a ff 	U..%`..((....
00003688	2020-01-03 18:39:25,4888957	+0,0279588	IRP_MJ_READ	UP	0x00000102	55 aa 09 27 63 07 06 28 28 00 00 80 04 8b fe 	U..'c..((......
00003690	2020-01-03 18:39:25,5168770	+0,0278939	IRP_MJ_READ	UP	0x00000102	55 aa 07 25 64 37 32 03 28 28 00 b3 fe 00 ba 0e 00 00 00 00 …	U..%d72.((..........…
00003692	2020-01-03 18:39:25,5328845	+0,0159661	IRP_MJ_READ	UP	0x00000102	55 aa 07 25 60 05 04 28 28 00 00 1a ff 	U..%`..((....
00003694	2020-01-03 18:39:25,5569522	+0,0240289	IRP_MJ_READ	UP	0x00000102	55 aa 07 25 60 05 04 28 28 00 00 1a ff 	U..%`..((....
00003696	2020-01-03 18:39:25,5808782	+0,0238301	IRP_MJ_READ	UP	0x00000102	55 aa 07 25 60 05 04 28 28 00 00 1a ff 	U..%`..((....
00003698	2020-01-03 18:39:25,6128803	+0,0319439	IRP_MJ_READ	UP	0x00000102	55 aa 03 23 00 31 18 90 ff 55 aa 0b 28 6d 09 00 03 00 00 00 …	U..#.1...U..(m......…
00003700	2020-01-03 18:39:25,6302742	+0,0173492	IRP_MJ_READ	UP	0x00000102	55 aa 07 25 60 05 04 28 28 00 00 1a ff 	U..%`..((....
00003702	2020-01-03 18:39:25,6542792	+0,0239642	IRP_MJ_READ	UP	0x00000102	55 aa 09 27 63 07 06 28 28 00 00 80 04 8b fe 	U..'c..((......
00003704	2020-01-03 18:39:25,6742802	+0,0199617	IRP_MJ_READ	UP	0x00000102	55 aa 07 25 60 05 04 28 28 00 00 1a ff 	U..%`..((....
00003706	2020-01-03 18:39:25,7258222	+0,0514645	IRP_MJ_READ	UP	0x00000102	55 aa 07 25 64 be 06 03 28 28 00 58 fe 55 aa 08 25 07 bd 6f …	U..%d...((.X.U..%..o…
00003708	2020-01-03 18:39:25,8528571	+0,1269756	IRP_MJ_READ	UP	0x00000102	55 aa 07 25 60 05 04 28 28 00 00 1a ff 55 aa 07 25 60 05 04 …	U..%`..((....U..%`..…
00003710	2020-01-03 18:39:26,0441576	+0,1912360	IRP_MJ_READ	UP	0x00000102	55 aa 07 25 60 05 04 28 28 00 00 1a ff 55 aa 07 25 60 05 04 …	U..%`..((....U..%`..…
00003712	2020-01-03 18:39:26,1370877	+0,0928774	IRP_MJ_READ	UP	0x00000102	55 aa 09 27 63 07 06 28 28 00 00 80 04 8b fe 55 aa 07 25 64 …	U..'c..((......U..%d…
00003714	2020-01-03 18:39:26,2820771	+0,1449054	IRP_MJ_READ	UP	0x00000102	55 aa 07 25 60 05 04 28 28 00 00 1a ff 55 aa 07 25 60 05 04 …	U..%`..((....U..%`..…
00003716	2020-01-03 18:39:26,3308879	+0,0486895	IRP_MJ_READ	UP	0x00000102	55 aa 07 25 60 05 04 28 28 00 00 1a ff 55 aa 0b 28 6d 09 00 …	U..%`..((....U..(m..…
00003718	2020-01-03 18:39:26,4459848	+0,1149956	IRP_MJ_READ	UP	0x00000102	55 aa 09 27 63 07 06 28 28 00 00 80 04 8b fe 55 aa 07 25 60 …	U..'c..((......U..%`…
00003720	2020-01-03 18:39:26,4699877	+0,0239517	IRP_MJ_READ	UP	0x00000102	55 aa 07 25 60 05 04 28 28 00 00 1a ff 	U..%`..((....
00003722	2020-01-03 18:39:26,5179839	+0,0479096	IRP_MJ_READ	UP	0x00000102	55 aa 09 27 63 07 06 28 28 00 00 80 04 8b fe 55 aa 0b 28 6d …	U..'c..((......U..(m…
00003724	2020-01-03 18:39:26,5636251	+0,0455941	IRP_MJ_READ	UP	0x00000102	55 aa 07 25 64 7e 12 03 28 28 00 8c fe 55 aa 14 31 13 69 00 …	U..%d~..((...U..1.i.…
00003726	2020-01-03 18:39:26,6224792	+0,0588031	IRP_MJ_READ	UP	0x00000102	55 aa 07 25 60 05 04 28 28 00 00 1a ff 55 aa 0b 28 6d 09 00 …	U..%`..((....U..(m..…
00003728	2020-01-03 18:39:26,6383937	+0,0158268	IRP_MJ_READ	UP	0x00000102	55 aa 09 27 63 07 06 28 28 00 00 80 04 8b fe 	U..'c..((......
00003730	2020-01-03 18:39:26,6624062	+0,0239565	IRP_MJ_READ	UP	0x00000102	55 aa 07 25 60 05 04 28 28 00 00 1a ff 	U..%`..((....
00003732	2020-01-03 18:39:26,7169710	+0,0545155	IRP_MJ_READ	UP	0x00000102	e5 fd 55 aa 0b 28 6d 09 00 03 00 00 00 00 00 00 3b 18 ff 55 …	..U..(m.........;..U…
00003734	2020-01-03 18:39:26,7604239	+0,0434020	IRP_MJ_READ	UP	0x00000102	55 aa 07 25 60 05 04 28 28 00 00 1a ff 55 aa 07 25 60 05 04 …	U..%`..((....U..%`..…
00003736	2020-01-03 18:39:26,8590357	+0,0985548	IRP_MJ_READ	UP	0x00000102	55 aa 07 25 64 e9 10 03 28 28 00 23 fe 55 aa 12 33 11 fc 00 …	U..%d...((.#.U..3...…
00003738	2020-01-03 18:39:26,9527706	+0,0936314	IRP_MJ_READ	UP	0x00000102	55 aa 07 25 60 05 04 28 28 00 00 1a ff 55 aa 07 25 60 05 04 …	U..%`..((....U..%`..…
00003740	2020-01-03 18:39:27,0464961	+0,0936343	IRP_MJ_READ	UP	0x00000102	55 aa 07 25 60 05 04 28 28 00 00 1a ff 55 aa 07 25 64 1f 1c …	U..%`..((....U..%d..…
00003742	2020-01-03 18:39:27,0777361	+0,0311254	IRP_MJ_READ	UP	0x00000102	55 aa 09 27 63 07 06 28 28 00 00 80 04 8b fe 	U..'c..((......
00003744	2020-01-03 18:39:27,2671902	+0,1893887	IRP_MJ_READ	UP	0x00000102	55 aa 07 25 60 05 04 28 28 00 00 1a ff 55 aa 0b 28 6d 09 00 …	U..%`..((....U..(m..…
00003746	2020-01-03 18:39:27,3621810	+0,0948778	IRP_MJ_READ	UP	0x00000102	55 aa 07 25 60 05 04 28 28 00 00 1a ff 55 aa 0b 28 6d 09 00 …	U..%`..((....U..(m..…
00003748	2020-01-03 18:39:27,4094828	+0,0471388	IRP_MJ_READ	UP	0x00000102	55 aa 09 27 63 07 06 28 28 00 00 80 04 8b fe 55 aa 0b 28 6d …	U..'c..((......U..(m…
00003750	2020-01-03 18:39:27,4310275	+0,0214773	IRP_MJ_READ	UP	0x00000102	55 aa 07 25 60 05 04 28 28 00 00 1a ff 	U..%`..((....
00003752	2020-01-03 18:39:27,4550344	+0,0239486	IRP_MJ_READ	UP	0x00000102	55 aa 07 25 60 05 04 28 28 00 00 1a ff 	U..%`..((....
00003754	2020-01-03 18:39:27,4790290	+0,0238935	IRP_MJ_READ	UP	0x00000102	55 aa 07 25 60 05 04 28 28 00 00 1a ff 	U..%`..((....
00003756	2020-01-03 18:39:27,5470270	+0,0679179	IRP_MJ_READ	UP	0x00000102	55 aa 09 27 63 07 06 28 28 00 00 80 04 8b fe 55 aa 0b 28 6d …	U..'c..((......U..(m…
00003758	2020-01-03 18:39:27,5710280	+0,0239515	IRP_MJ_READ	UP	0x00000102	55 aa 07 25 60 05 04 28 28 00 00 1a ff 	U..%`..((....
00003760	2020-01-03 18:39:27,6230413	+0,0519735	IRP_MJ_READ	UP	0x00000102	55 aa 07 25 60 05 04 28 28 00 00 1a ff 55 aa 0b 28 6d 09 00 …	U..%`..((....U..(m..…
00003762	2020-01-03 18:39:27,6446627	+0,0215074	IRP_MJ_READ	UP	0x00000102	55 aa 09 27 63 07 06 28 28 00 00 80 04 8b fe 	U..'c..((......
00003764	2020-01-03 18:39:27,7166651	+0,0719641	IRP_MJ_READ	UP	0x00000102	55 aa 07 25 64 7e 0a 03 28 28 00 94 fe 55 aa 0c 29 0b 71 00 …	U..%d~..((...U..).q.…
00003766	2020-01-03 18:39:27,7406677	+0,0239567	IRP_MJ_READ	UP	0x00000102	55 aa 07 25 60 05 04 28 28 00 00 1a ff 	U..%`..((....
00003768	2020-01-03 18:39:27,7646653	+0,0239057	IRP_MJ_READ	UP	0x00000102	55 aa 07 25 60 05 04 28 28 00 00 1a ff 	U..%`..((....
00003770	2020-01-03 18:39:27,8022235	+0,0375157	IRP_MJ_READ	UP	0x00000102	55 aa 09 27 63 07 06 28 28 00 00 80 04 8b fe 55 aa 0b 28 6d …	U..'c..((......U..(m…
00003772	2020-01-03 18:39:27,8394397	+0,0371356	IRP_MJ_READ	UP	0x00000102	55 aa 07 25 64 ea 0a 03 28 28 00 28 fe 55 aa 0c 29 0b e5 00 …	U..%d...((.(.U..)...…
00003774	2020-01-03 18:39:27,9074489	+0,0679504	IRP_MJ_READ	UP	0x00000102	55 aa 07 25 64 7e 0a 03 28 28 00 94 fe 55 aa 0c 29 0b 71 00 …	U..%d~..((...U..).q.…
00003776	2020-01-03 18:39:27,9560424	+0,0485375	IRP_MJ_READ	UP	0x00000102	55 aa 07 25 64 ea 0a 03 28 28 00 28 fe 55 aa 0c 29 0b e5 00 …	U..%d...((.(.U..)...…
00003778	2020-01-03 18:39:28,0080370	+0,0518945	IRP_MJ_READ	UP	0x00000102	55 aa 09 27 63 07 06 28 28 00 00 80 04 8b fe 55 aa 0b 28 6d …	U..'c..((......U..(m…
00003780	2020-01-03 18:39:28,0352582	+0,0271616	IRP_MJ_READ	UP	0x00000102	55 aa 07 25 60 05 04 28 28 00 00 1a ff 	U..%`..((....
00003782	2020-01-03 18:39:28,0512224	+0,0158607	IRP_MJ_READ	UP	0x00000102	55 aa 07 25 60 05 04 28 28 00 00 1a ff 	U..%`..((....
00003784	2020-01-03 18:39:28,1281856	+0,0768955	IRP_MJ_READ	UP	0x00000102	55 aa 07 25 64 7e 0a 03 28 28 00 94 fe 55 aa 0c 29 0b 71 00 …	U..%d~..((...U..).q.…
00003786	2020-01-03 18:39:28,1492699	+0,0210208	IRP_MJ_READ	UP	0x00000102	55 aa 07 25 60 05 04 28 28 00 00 1a ff 	U..%`..((....
00003788	2020-01-03 18:39:28,2251083	+0,0757802	IRP_MJ_READ	UP	0x00000102	55 aa 07 25 64 ea 0a 03 28 28 00 28 fe 55 aa 0c 29 0b e5 00 …	U..%d...((.(.U..)...…
00003790	2020-01-03 18:39:28,2446983	+0,0195288	IRP_MJ_READ	UP	0x00000102	55 aa 07 25 60 05 04 28 28 00 00 1a ff 	U..%`..((....
00003792	2020-01-03 18:39:28,2686975	+0,0239135	IRP_MJ_READ	UP	0x00000102	55 aa 09 27 63 07 06 28 28 00 00 80 04 8b fe 	U..'c..((......
00003794	2020-01-03 18:39:28,3020540	+0,0332696	IRP_MJ_READ	UP	0x00000102	55 aa 07 25 60 05 04 28 28 00 00 1a ff 55 aa 0b 28 6d 09 00 …	U..%`..((....U..(m..…
00003796	2020-01-03 18:39:28,3180480	+0,0159005	IRP_MJ_READ	UP	0x00000102	55 aa 07 25 60 05 04 28 28 00 00 1a ff 	U..%`..((....
00003798	2020-01-03 18:39:28,3420555	+0,0239680	IRP_MJ_READ	UP	0x00000102	55 aa 07 25 60 05 04 28 28 00 00 1a ff 	U..%`..((....
00003800	2020-01-03 18:39:28,3680019	+0,0258913	IRP_MJ_READ	UP	0x00000102	55 aa 07 25 60 05 04 28 28 00 00 1a ff 	U..%`..((....
00003802	2020-01-03 18:39:28,3999976	+0,0319211	IRP_MJ_READ	UP	0x00000102	55 aa 09 27 63 07 06 28 28 00 00 80 04 8b fe 55 aa 0b 28 6d …	U..'c..((......U..(m…
00003804	2020-01-03 18:39:28,4159902	+0,0158976	IRP_MJ_READ	UP	0x00000102	55 aa 07 25 60 05 04 28 28 00 00 1a ff 	U..%`..((....
00003806	2020-01-03 18:39:28,4374936	+0,0214466	IRP_MJ_READ	UP	0x00000102	55 aa 07 25 60 05 04 28 28 00 00 1a ff 	U..%`..((....
00003808	2020-01-03 18:39:28,4630843	+0,0255287	IRP_MJ_READ	UP	0x00000102	55 aa 07 25 60 05 04 28 28 00 00 1a ff 	U..%`..((....
00003810	2020-01-03 18:39:28,5110916	+0,0479628	IRP_MJ_READ	UP	0x00000102	55 aa 07 25 60 05 04 28 28 00 00 1a ff 55 aa 0b 28 6d 09 00 …	U..%`..((....U..(m..…
00003812	2020-01-03 18:39:28,5350854	+0,0239048	IRP_MJ_READ	UP	0x00000102	55 aa 07 25 60 05 04 28 28 00 00 1a ff 	U..%`..((....
00003814	2020-01-03 18:39:28,5550866	+0,0199422	IRP_MJ_READ	UP	0x00000102	55 aa 07 25 60 05 04 28 28 00 00 1a ff 	U..%`..((....
00003816	2020-01-03 18:39:28,6030945	+0,0479645	IRP_MJ_READ	UP	0x00000102	55 aa 07 25 60 05 04 28 28 00 00 1a ff 55 aa 0b 28 6d 09 00 …	U..%`..((....U..(m..…
00003818	2020-01-03 18:39:28,6327195	+0,0295262	IRP_MJ_READ	UP	0x00000102	55 aa 09 27 63 07 06 28 28 00 00 80 04 8b fe 	U..'c..((......
00003820	2020-01-03 18:39:28,6621072	+0,0293307	IRP_MJ_READ	UP	0x00000102	55 aa 07 25 64 f5 08 03 28 28 00 1f fe 55 aa 0a 2b 09 f8 f8 …	U..%d...((...U..+...…
00003822	2020-01-03 18:39:28,7021078	+0,0398971	IRP_MJ_READ	UP	0x00000102	55 aa 07 25 60 05 04 28 28 00 00 1a ff 55 aa 0b 28 6d 09 00 …	U..%`..((....U..(m..…
00003824	2020-01-03 18:39:28,7221120	+0,0199116	IRP_MJ_READ	UP	0x00000102	55 aa 07 25 60 05 04 28 28 00 00 1a ff 	U..%`..((....
00003826	2020-01-03 18:39:28,7461093	+0,0239124	IRP_MJ_READ	UP	0x00000102	55 aa 07 25 60 05 04 28 28 00 00 1a ff 	U..%`..((....
00003828	2020-01-03 18:39:28,7754225	+0,0292228	IRP_MJ_READ	UP	0x00000102	55 aa 09 27 63 07 06 28 28 00 00 80 04 8b fe 	U..'c..((......
00003830	2020-01-03 18:39:28,8034226	+0,0279107	IRP_MJ_READ	UP	0x00000102	55 aa 07 25 60 05 04 28 28 00 00 1a ff 55 aa 0b 28 6d 09 00 …	U..%`..((....U..(m..…
00003832	2020-01-03 18:39:28,8234258	+0,0198919	IRP_MJ_READ	UP	0x00000102	55 aa 07 25 60 05 04 28 28 00 00 1a ff 	U..%`..((....
00003834	2020-01-03 18:39:28,8489644	+0,0254424	IRP_MJ_READ	UP	0x00000102	55 aa 07 25 60 05 04 28 28 00 00 1a ff 	U..%`..((....
00003836	2020-01-03 18:39:28,8649649	+0,0159016	IRP_MJ_READ	UP	0x00000102	55 aa 07 25 60 05 04 28 28 00 00 1a ff 	U..%`..((....
00003838	2020-01-03 18:39:28,9155314	+0,0504711	IRP_MJ_READ	UP	0x00000102	55 aa 09 27 63 07 06 28 28 00 00 80 04 8b fe 55 aa 0b 28 6d …	U..'c..((......U..(m…
00003840	2020-01-03 18:39:28,9395281	+0,0239001	IRP_MJ_READ	UP	0x00000102	55 aa 07 25 60 05 04 28 28 00 00 1a ff 	U..%`..((....
00003842	2020-01-03 18:39:28,9635303	+0,0239068	IRP_MJ_READ	UP	0x00000102	55 aa 07 25 60 05 04 28 28 00 00 1a ff 	U..%`..((....
00003844	2020-01-03 18:39:28,9995291	+0,0359226	IRP_MJ_READ	UP	0x00000102	55 aa 07 25 60 05 04 28 28 00 00 1a ff 55 aa 0b 28 6d 09 00 …	U..%`..((....U..(m..…
00003846	2020-01-03 18:39:29,0195264	+0,0199054	IRP_MJ_READ	UP	0x00000102	55 aa 09 27 63 07 06 28 28 00 00 80 04 8b fe 	U..'c..((......
00003848	2020-01-03 18:39:29,0355437	+0,0159372	IRP_MJ_READ	UP	0x00000102	55 aa 07 25 60 05 04 28 28 00 00 1a ff 	U..%`..((....
00003850	2020-01-03 18:39:29,0601050	+0,0244543	IRP_MJ_READ	UP	0x00000102	55 aa 04 22 01 f2 f3 02 f1 fd 	U.."......
00003852	2020-01-03 18:39:29,1104522	+0,0502410	IRP_MJ_READ	UP	0x00000102	55 aa 07 25 60 05 04 28 28 00 00 1a ff 55 aa 0b 28 6d 09 00 …	U..%`..((....U..(m..…
00003854	2020-01-03 18:39:29,1333728	+0,0228140	IRP_MJ_READ	UP	0x00000102	55 aa 07 25 60 05 04 28 28 00 00 1a ff 	U..%`..((....
00003856	2020-01-03 18:39:29,1592044	+0,0257383	IRP_MJ_READ	UP	0x00000102	55 aa 09 27 63 07 06 28 28 00 00 80 04 8b fe 	U..'c..((......
00003858	2020-01-03 18:39:29,2034120	+0,0440903	IRP_MJ_READ	UP	0x00000102	55 aa 07 25 60 05 04 28 28 00 00 1a ff 55 aa 0b 28 6d 09 00 …	U..%`..((....U..(m..…
00003860	2020-01-03 18:39:29,2281921	+0,0246506	IRP_MJ_READ	UP	0x00000102	55 aa 07 25 60 05 04 28 28 00 00 1a ff 	U..%`..((....
00003862	2020-01-03 18:39:29,2522071	+0,0238796	IRP_MJ_READ	UP	0x00000102	55 aa 07 25 60 05 04 28 28 00 00 1a ff 	U..%`..((....
00003864	2020-01-03 18:39:29,3061574	+0,0536922	IRP_MJ_READ	UP	0x00000102	55 aa 09 27 63 07 06 28 28 00 00 80 04 8b fe 55 aa 0b 28 6d …	U..'c..((......U..(m…
00003866	2020-01-03 18:39:29,3273022	+0,0210205	IRP_MJ_READ	UP	0x00000102	55 aa 07 25 60 05 04 28 28 00 00 1a ff 	U..%`..((....
00003868	2020-01-03 18:39:29,3483085	+0,0209139	IRP_MJ_READ	UP	0x00000102	55 aa 07 25 60 05 04 28 28 00 00 1a ff 	U..%`..((....
00003870	2020-01-03 18:39:29,4488732	+0,1004313	IRP_MJ_READ	UP	0x00000102	55 aa 07 25 60 05 04 28 28 00 00 1a ff 55 aa 09 27 63 07 06 …	U..%`..((....U..'c..…
00003872	2020-01-03 18:39:29,5456807	+0,0966880	IRP_MJ_READ	UP	0x00000102	55 aa 07 25 60 05 04 28 28 00 00 1a ff 55 aa 07 25 60 05 04 …	U..%`..((....U..%`..…
00003874	2020-01-03 18:39:29,6434953	+0,0976992	IRP_MJ_READ	UP	0x00000102	55 aa 07 25 60 05 04 28 28 00 00 1a ff 55 aa 07 25 60 05 04 …	U..%`..((....U..%`..…
00003876	2020-01-03 18:39:29,7059694	+0,0623666	IRP_MJ_READ	UP	0x00000102	55 aa 07 25 64 7e 0a 03 28 28 00 94 fe 55 aa 0c 29 0b 71 00 …	U..%d~..((...U..).q.…
00003878	2020-01-03 18:39:29,7383315	+0,0322265	IRP_MJ_READ	UP	0x00000102	55 aa 07 25 60 05 04 28 28 00 00 1a ff 	U..%`..((....
00003880	2020-01-03 18:39:29,8056972	+0,0672147	IRP_MJ_READ	UP	0x00000102	55 aa 07 25 60 05 04 28 28 00 00 1a ff 55 aa 09 27 63 07 06 …	U..%`..((....U..'c..…
00003882	2020-01-03 18:39:29,8526645	+0,0468376	IRP_MJ_READ	UP	0x00000102	55 aa 07 25 60 05 04 28 28 00 00 1a ff 55 aa 07 25 60 05 04 …	U..%`..((....U..%`..…
00003884	2020-01-03 18:39:30,0274243	+0,1746622	IRP_MJ_READ	UP	0x00000102	55 aa 07 25 60 05 04 28 28 00 00 1a ff 55 aa 0b 28 6d 09 00 …	U..%`..((....U..(m..…
00003886	2020-01-03 18:39:30,0743569	+0,0468256	IRP_MJ_READ	UP	0x00000102	55 aa 07 25 60 05 04 28 28 00 00 1a ff 55 aa 07 25 60 05 04 …	U..%`..((....U..%`..…
00003888	2020-01-03 18:39:30,1715439	+0,0970461	IRP_MJ_READ	UP	0x00000102	55 aa 07 25 60 05 04 28 28 00 00 1a ff 55 aa 0b 28 6d 09 00 …	U..%`..((....U..(m..…
00003890	2020-01-03 18:39:30,2383983	+0,0667033	IRP_MJ_READ	UP	0x00000102	55 aa 07 25 60 05 04 28 28 00 00 1a ff 55 aa 0b 28 6d 09 00 …	U..%`..((....U..(m..…
00003892	2020-01-03 18:39:30,3642603	+0,1257918	IRP_MJ_READ	UP	0x00000102	55 aa 09 27 63 07 06 28 28 00 00 80 04 8b fe 55 aa 07 25 60 …	U..'c..((......U..%`…
00003894	2020-01-03 18:39:30,4041352	+0,0397860	IRP_MJ_READ	UP	0x00000102	55 aa 07 25 60 05 04 28 28 00 00 1a ff 55 aa 0b 28 6d 09 00 …	U..%`..((....U..(m..…
00003896	2020-01-03 18:39:30,4282230	+0,0239881	IRP_MJ_READ	UP	0x00000102	55 aa 07 25 60 05 04 28 28 00 00 1a ff 	U..%`..((....
00003898	2020-01-03 18:39:30,4522121	+0,0239221	IRP_MJ_READ	UP	0x00000102	55 aa 07 25 60 05 04 28 28 00 00 1a ff 	U..%`..((....
00003900	2020-01-03 18:39:30,5217660	+0,0694739	IRP_MJ_READ	UP	0x00000102	55 aa 07 25 60 05 04 28 28 00 00 1a ff 55 aa 0b 28 6d 09 00 …	U..%`..((....U..(m..…
00003902	2020-01-03 18:39:30,5977730	+0,0759074	IRP_MJ_READ	UP	0x00000102	55 aa 07 25 64 e9 10 03 28 28 00 23 fe 55 aa 12 33 11 fc 00 …	U..%d...((.#.U..3...…
00003904	2020-01-03 18:39:30,6217660	+0,0238943	IRP_MJ_READ	UP	0x00000102	55 aa 07 25 60 05 04 28 28 00 00 1a ff 	U..%`..((....
00003906	2020-01-03 18:39:30,6429787	+0,0211144	IRP_MJ_READ	UP	0x00000102	55 aa 07 25 60 05 04 28 28 00 00 1a ff 	U..%`..((....
00003908	2020-01-03 18:39:30,6641340	+0,0210403	IRP_MJ_READ	UP	0x00000102	55 aa 07 25 60 05 04 28 28 00 00 1a ff 	U..%`..((....
00003910	2020-01-03 18:39:30,7161365	+0,0518674	IRP_MJ_READ	UP	0x00000102	55 aa 09 27 63 07 06 28 28 00 00 80 04 8b fe 55 aa 0b 28 6d …	U..'c..((......U..(m…
00003912	2020-01-03 18:39:30,7401565	+0,0239234	IRP_MJ_READ	UP	0x00000102	30 f4 	0.
00003914	2020-01-03 18:39:30,7668931	+0,0266330	IRP_MJ_READ	UP	0x00000102	55 aa 07 25 60 05 04 28 28 00 00 1a ff 	U..%`..((....
00003916	2020-01-03 18:39:30,8176801	+0,0507363	IRP_MJ_READ	UP	0x00000102	55 aa 07 25 64 1f 1c 03 28 28 00 e1 fe 55 aa 0b 28 6d 09 00 …	U..%d...((...U..(m..…
00003918	2020-01-03 18:39:30,8336986	+0,0159215	IRP_MJ_READ	UP	0x00000102	55 aa 09 27 63 07 06 28 28 00 00 80 04 8b fe 	U..'c..((......
00003920	2020-01-03 18:39:30,9056822	+0,0718621	IRP_MJ_READ	UP	0x00000102	55 aa 07 25 64 7e 12 03 28 28 00 8c fe 55 aa 14 31 13 69 00 …	U..%d~..((...U..1.i.…
00003922	2020-01-03 18:39:30,9336815	+0,0278666	IRP_MJ_READ	UP	0x00000102	55 aa 07 25 60 05 04 28 28 00 00 1a ff 	U..%`..((....
00003924	2020-01-03 18:39:30,9536907	+0,0198754	IRP_MJ_READ	UP	0x00000102	55 aa 07 25 60 05 04 28 28 00 00 1a ff 	U..%`..((....
00003926	2020-01-03 18:39:31,0256736	+0,0718733	IRP_MJ_READ	UP	0x00000102	55 aa 09 27 63 07 06 28 28 00 00 80 04 8b fe 55 aa 0b 28 6d …	U..'c..((......U..(m…
00003928	2020-01-03 18:39:31,0496991	+0,0238930	IRP_MJ_READ	UP	0x00000102	55 aa 07 25 60 05 04 28 28 00 00 1a ff 	U..%`..((....
00003930	2020-01-03 18:39:31,1193680	+0,0695528	IRP_MJ_READ	UP	0x00000102	55 aa 07 25 60 05 04 28 28 00 00 1a ff 55 aa 0b 28 6d 09 00 …	U..%`..((....U..(m..…
00003932	2020-01-03 18:39:31,1451619	+0,0257345	IRP_MJ_READ	UP	0x00000102	55 aa 09 27 63 07 06 28 28 00 00 80 04 8b fe 	U..'c..((......
00003934	2020-01-03 18:39:31,1948869	+0,0496270	IRP_MJ_READ	UP	0x00000102	55 aa 07 25 60 05 04 28 28 00 00 1a ff 55 aa 0b 28 6d 09 00 …	U..%`..((....U..(m..…
00003936	2020-01-03 18:39:31,2204814	+0,0254551	IRP_MJ_READ	UP	0x00000102	55 aa 07 25 60 05 04 28 28 00 00 1a ff 	U..%`..((....
00003938	2020-01-03 18:39:31,2445206	+0,0239401	IRP_MJ_READ	UP	0x00000102	55 aa 07 25 60 05 04 28 28 00 00 1a ff 	U..%`..((....
00003940	2020-01-03 18:39:31,2646944	+0,0201132	IRP_MJ_READ	UP	0x00000102	55 aa 09 27 63 07 06 28 28 00 00 80 04 8b fe 	U..'c..((......
00003942	2020-01-03 18:39:31,2905707	+0,0257847	IRP_MJ_READ	UP	0x00000102	55 aa 0b 28 6d 09 00 03 00 00 00 00 00 00 3b 18 ff 55 aa 07 …	U..(m.........;..U..…
00003944	2020-01-03 18:39:31,3386212	+0,0479828	IRP_MJ_READ	UP	0x00000102	55 aa 07 25 64 1f 1c 03 28 28 00 e1 fe 55 aa 1e 3f 1d 06 78 …	U..%d...((...U..?..x…
00003946	2020-01-03 18:39:31,3626012	+0,0238581	IRP_MJ_READ	UP	0x00000102	55 aa 07 25 60 05 04 28 28 00 00 1a ff 	U..%`..((....
00003948	2020-01-03 18:39:31,3945935	+0,0318826	IRP_MJ_READ	UP	0x00000102	55 aa 07 25 60 05 04 28 28 00 00 1a ff 55 aa 0b 28 6d 09 00 …	U..%`..((....U..(m..…
00003950	2020-01-03 18:39:31,4306096	+0,0359181	IRP_MJ_READ	UP	0x00000102	55 aa 07 25 64 7e 12 03 28 28 00 8c fe 55 aa 14 31 13 69 00 …	U..%d~..((...U..1.i.…
00003952	2020-01-03 18:39:31,4546220	+0,0239018	IRP_MJ_READ	UP	0x00000102	55 aa 07 25 60 05 04 28 28 00 00 1a ff 	U..%`..((....
00003954	2020-01-03 18:39:31,5045078	+0,0497706	IRP_MJ_READ	UP	0x00000102	55 aa 07 25 60 05 04 28 28 00 00 1a ff 55 aa 0b 28 6d 09 00 …	U..%`..((....U..(m..…
00003956	2020-01-03 18:39:31,5285140	+0,0238444	IRP_MJ_READ	UP	0x00000102	55 aa 07 25 60 05 04 28 28 00 00 1a ff 	U..%`..((....
00003958	2020-01-03 18:39:31,6005219	+0,0718965	IRP_MJ_READ	UP	0x00000102	55 aa 07 25 64 1f 1c 03 28 28 00 e1 fe 55 aa 1e 3f 1d 06 78 …	U..%d...((...U..?..x…
00003960	2020-01-03 18:39:31,6463842	+0,0457527	IRP_MJ_READ	UP	0x00000102	55 aa 07 25 64 e9 10 03 28 28 00 23 fe 55 aa 12 33 11 fc 00 …	U..%d...((.#.U..3...…
00003962	2020-01-03 18:39:31,6983967	+0,0519434	IRP_MJ_READ	UP	0x00000102	55 aa 07 25 60 05 04 28 28 00 00 1a ff 55 aa 0b 28 6d 09 00 …	U..%`..((....U..(m..…
00003964	2020-01-03 18:39:31,7222919	+0,0237313	IRP_MJ_READ	UP	0x00000102	55 aa 09 27 63 07 06 28 28 00 00 80 04 8b fe 	U..'c..((......
00003966	2020-01-03 18:39:31,7463818	+0,0239361	IRP_MJ_READ	UP	0x00000102	55 aa 07 25 60 05 04 28 28 00 00 1a ff 	U..%`..((....
00003968	2020-01-03 18:39:31,7933680	+0,0468362	IRP_MJ_READ	UP	0x00000102	55 aa 07 25 60 05 04 28 28 00 00 1a ff 55 aa 0b 28 6d 09 00 …	U..%`..((....U..(m..…
00003970	2020-01-03 18:39:31,8134058	+0,0199801	IRP_MJ_READ	UP	0x00000102	55 aa 07 25 60 05 04 28 28 00 00 1a ff 	U..%`..((....
00003972	2020-01-03 18:39:31,8421695	+0,0286885	IRP_MJ_READ	UP	0x00000102	55 aa 09 27 63 07 06 28 28 00 00 80 04 8b fe 	U..'c..((......
00003974	2020-01-03 18:39:31,8632054	+0,0209737	IRP_MJ_READ	UP	0x00000102	55 aa 04 22 01 7c 01 00 5b ff 	U..".|..[.
00003976	2020-01-03 18:39:31,9208271	+0,0575489	IRP_MJ_READ	UP	0x00000102	55 aa 0b 28 6d 09 02 03 00 00 00 00 00 00 3b 16 ff 55 aa 07 …	U..(m.........;..U..…
00003978	2020-01-03 18:39:31,9373143	+0,0163752	IRP_MJ_READ	UP	0x00000102	55 aa 07 25 60 05 04 28 28 00 00 1a ff 	U..%`..((....
00003980	2020-01-03 18:39:31,9586998	+0,0213170	IRP_MJ_READ	UP	0x00000102	55 aa 07 25 60 05 04 28 28 00 00 1a ff 	U..%`..((....
00003982	2020-01-03 18:39:32,0134817	+0,0547321	IRP_MJ_READ	UP	0x00000102	55 aa 0b 28 6d 09 02 03 00 00 00 00 00 00 3b 16 ff 55 aa 07 …	U..(m.........;..U..…
00003984	2020-01-03 18:39:32,0583323	+0,0447751	IRP_MJ_READ	UP	0x00000102	55 aa 07 25 64 1f 1c 03 28 28 00 e1 fe 55 aa 1e 3f 1d 06 78 …	U..%d...((...U..?..x…
00003986	2020-01-03 18:39:32,1081490	+0,0497311	IRP_MJ_READ	UP	0x00000102	55 aa 09 27 63 07 06 28 28 00 00 80 04 8b fe 55 aa 0b 28 6d …	U..'c..((......U..(m…
00003988	2020-01-03 18:39:32,1259387	+0,0175245	IRP_MJ_READ	UP	0x00000102	55 aa 07 25 60 05 04 28 28 00 00 1a ff 	U..%`..((....
00003990	2020-01-03 18:39:32,1527900	+0,0267779	IRP_MJ_READ	UP	0x00000102	55 aa 07 25 60 05 04 28 28 00 00 1a ff 	U..%`..((....
00003992	2020-01-03 18:39:32,2072334	+0,0543941	IRP_MJ_READ	UP	0x00000102	55 aa 07 25 64 e9 10 03 28 28 00 23 fe 55 aa 0b 28 6d 09 02 …	U..%d...((.#.U..(m..…
00003994	2020-01-03 18:39:32,2248800	+0,0175545	IRP_MJ_READ	UP	0x00000102	55 aa 09 27 63 07 06 28 28 00 00 80 04 8b fe 	U..'c..((......
00003996	2020-01-03 18:39:32,2507329	+0,0255210	IRP_MJ_READ	UP	0x00000102	55 aa 07 25 60 05 04 28 28 00 00 1a ff 	U..%`..((....
00003998	2020-01-03 18:39:32,3005531	+0,0497091	IRP_MJ_READ	UP	0x00000102	55 aa 07 25 60 05 04 28 28 00 00 1a ff 55 aa 0b 28 6d 09 02 …	U..%`..((....U..(m..…
00004000	2020-01-03 18:39:32,3205470	+0,0198842	IRP_MJ_READ	UP	0x00000102	55 aa 07 25 60 05 04 28 28 00 00 1a ff 	U..%`..((....
00004002	2020-01-03 18:39:32,3944592	+0,0738007	IRP_MJ_READ	UP	0x00000102	55 aa 07 25 64 1f 1c 03 28 28 00 e1 fe 55 aa 1e 3f 1d 06 78 …	U..%d...((...U..?..x…
00004004	2020-01-03 18:39:32,4184594	+0,0238857	IRP_MJ_READ	UP	0x00000102	55 aa 07 25 60 05 04 28 28 00 00 1a ff 	U..%`..((....
00004006	2020-01-03 18:39:32,4424571	+0,0238872	IRP_MJ_READ	UP	0x00000102	55 aa 07 25 60 05 04 28 28 00 00 1a ff 	U..%`..((....
00004008	2020-01-03 18:39:32,5144501	+0,0718814	IRP_MJ_READ	UP	0x00000102	55 aa 07 25 60 05 04 28 28 00 00 1a ff 55 aa 0b 28 6d 09 02 …	U..%`..((....U..(m..…
00004010	2020-01-03 18:39:32,5384538	+0,0238933	IRP_MJ_READ	UP	0x00000102	55 aa 07 25 60 05 04 28 28 00 00 1a ff 	U..%`..((....
00004012	2020-01-03 18:39:32,5889857	+0,0504218	IRP_MJ_READ	UP	0x00000102	55 aa 07 25 60 05 04 28 28 00 00 1a ff 55 aa 0b 28 6d 09 02 …	U..%`..((....U..(m..…
00004014	2020-01-03 18:39:32,6548892	+0,0657921	IRP_MJ_READ	UP	0x00000102	55 aa 07 25 64 1f 1c 03 28 28 00 e1 fe 55 aa 1e 3f 1d 06 78 …	U..%d...((...U..?..x…
00004016	2020-01-03 18:39:32,6869338	+0,0319348	IRP_MJ_READ	UP	0x00000102	55 aa 0b 28 6d 09 02 03 00 00 00 00 00 00 3b 16 ff 55 aa 07 …	U..(m.........;..U..…
00004018	2020-01-03 18:39:32,8040185	+0,1169718	IRP_MJ_READ	UP	0x00000102	00 00 00 00 00 55 aa 09 27 63 07 06 28 28 00 00 80 04 8b fe 	.....U..'c..((......
00004020	2020-01-03 18:39:32,8237673	+0,0196390	IRP_MJ_READ	UP	0x00000102	55 aa 07 25 60 05 04 28 28 00 00 1a ff 	U..%`..((....
00004022	2020-01-03 18:39:32,8480098	+0,0241006	IRP_MJ_READ	UP	0x00000102	55 aa 07 25 60 05 04 28 28 00 00 1a ff 	U..%`..((....
00004024	2020-01-03 18:39:32,8943956	+0,0462766	IRP_MJ_READ	UP	0x00000102	55 aa 07 25 60 05 04 28 28 00 00 1a ff 55 aa 0b 28 6d 09 02 …	U..%`..((....U..(m..…
00004026	2020-01-03 18:39:32,9225674	+0,0281322	IRP_MJ_READ	UP	0x00000102	55 aa 09 27 63 07 06 28 28 00 00 80 04 8b fe 	U..'c..((......
00004028	2020-01-03 18:39:32,9921778	+0,0695439	IRP_MJ_READ	UP	0x00000102	55 aa 07 25 64 1f 1c 03 28 28 00 e1 fe 55 aa 1e 3f 1d 06 78 …	U..%d...((...U..?..x…
00004030	2020-01-03 18:39:33,0402266	+0,0479363	IRP_MJ_READ	UP	0x00000102	55 aa 07 25 64 7e 12 03 28 28 00 8c fe 55 aa 14 31 13 69 00 …	U..%d~..((...U..1.i.…
00004032	2020-01-03 18:39:33,0900781	+0,0497354	IRP_MJ_READ	UP	0x00000102	55 aa 07 25 60 05 04 28 28 00 00 1a ff 55 aa 0b 28 6d 09 02 …	U..%`..((....U..(m..…
00004034	2020-01-03 18:39:33,1140785	+0,0238885	IRP_MJ_READ	UP	0x00000102	55 aa 07 25 60 05 04 28 28 00 00 1a ff 	U..%`..((....
00004036	2020-01-03 18:39:33,1380729	+0,0238842	IRP_MJ_READ	UP	0x00000102	55 aa 07 25 60 05 04 28 28 00 00 1a ff 	U..%`..((....
00004038	2020-01-03 18:39:33,1914612	+0,0532741	IRP_MJ_READ	UP	0x00000102	55 aa 07 25 64 1f 1c 03 28 28 00 e1 fe 55 aa 1e 3f 1d 06 78 …	U..%d...((...U..?..x…
00004040	2020-01-03 18:39:33,2137752	+0,0222475	IRP_MJ_READ	UP	0x00000102	55 aa 07 25 60 05 04 28 28 00 00 1a ff 	U..%`..((....
00004042	2020-01-03 18:39:33,2347011	+0,0208303	IRP_MJ_READ	UP	0x00000102	55 aa 09 27 63 07 06 28 28 00 00 80 04 8b fe 	U..'c..((......
00004044	2020-01-03 18:39:33,2624940	+0,0277352	IRP_MJ_READ	UP	0x00000102	55 aa 07 25 60 05 04 28 28 00 00 1a ff 	U..%`..((....
00004046	2020-01-03 18:39:33,3120392	+0,0494492	IRP_MJ_READ	UP	0x00000102	55 aa 07 25 64 e9 10 03 28 28 00 23 fe 55 aa 12 33 11 fc 00 …	U..%d...((.#.U..3...…
00004048	2020-01-03 18:39:33,3520796	+0,0399255	IRP_MJ_READ	UP	0x00000102	55 aa 07 25 60 05 04 28 28 00 00 1a ff 	U..%`..((....
00004050	2020-01-03 18:39:33,3985590	+0,0463675	IRP_MJ_READ	UP	0x00000102	55 aa 09 27 63 07 06 28 28 00 00 80 04 8b fe 55 aa 0b 28 6d …	U..'c..((......U..(m…
00004052	2020-01-03 18:39:33,4261654	+0,0275118	IRP_MJ_READ	UP	0x00000102	55 aa 04 22 01 7c 00 00 5c ff 	U..".|..\.
00004054	2020-01-03 18:39:33,4501665	+0,0238488	IRP_MJ_READ	UP	0x00000102	55 aa 07 25 60 05 04 28 28 00 00 1a ff 	U..%`..((....
00004056	2020-01-03 18:39:33,5051608	+0,0548844	IRP_MJ_READ	UP	0x00000102	55 aa 07 25 64 1f 1c 03 28 28 00 e1 fe 55 aa 0b 28 6d 09 00 …	U..%d...((...U..(m..…
00004058	2020-01-03 18:39:33,5449217	+0,0396035	IRP_MJ_READ	UP	0x00000102	55 aa 07 25 64 7e 0a 03 28 28 00 94 fe 55 aa 0c 29 0b 71 00 …	U..%d~..((...U..).q.…
00004060	2020-01-03 18:39:33,5788600	+0,0337625	IRP_MJ_READ	UP	0x00000102	55 aa 09 27 63 07 06 28 28 00 00 80 04 8b fe 55 aa 0b 28 6d …	U..'c..((......U..(m…
00004062	2020-01-03 18:39:33,5948590	+0,0158884	IRP_MJ_READ	UP	0x00000102	55 aa 07 25 60 05 04 28 28 00 00 1a ff 	U..%`..((....
00004064	2020-01-03 18:39:33,6447031	+0,0497343	IRP_MJ_READ	UP	0x00000102	55 aa 07 25 64 7e 12 03 28 28 00 8c fe 55 aa 14 31 13 69 00 …	U..%d~..((...U..1.i.…
00004066	2020-01-03 18:39:33,6853585	+0,0405397	IRP_MJ_READ	UP	0x00000102	55 aa 07 25 60 05 04 28 28 00 00 1a ff 55 aa 0b 28 6d 09 00 …	U..%`..((....U..(m..…
00004068	2020-01-03 18:39:33,7138017	+0,0283733	IRP_MJ_READ	UP	0x00000102	55 aa 09 27 63 07 06 28 28 00 00 80 04 8b fe 	U..'c..((......
00004070	2020-01-03 18:39:33,8141567	+0,1001484	IRP_MJ_READ	UP	0x00000102	55 aa 07 25 64 1f 1c 03 28 28 00 e1 fe 55 aa 1e 3f 1d 06 78 …	U..%d...((...U..?..x…
00004072	2020-01-03 18:39:33,8341563	+0,0198348	IRP_MJ_READ	UP	0x00000102	55 aa 07 25 60 05 04 28 28 00 00 1a ff 	U..%`..((....
00004074	2020-01-03 18:39:33,8821568	+0,0478864	IRP_MJ_READ	UP	0x00000102	55 aa 07 25 60 05 04 28 28 00 00 1a ff 55 aa 0b 28 6d 09 00 …	U..%`..((....U..(m..…
00004076	2020-01-03 18:39:33,9061582	+0,0238341	IRP_MJ_READ	UP	0x00000102	55 aa 07 25 60 05 04 28 28 00 00 1a ff 	U..%`..((....
00004078	2020-01-03 18:39:33,9301417	+0,0238253	IRP_MJ_READ	UP	0x00000102	55 aa 07 25 60 05 04 28 28 00 00 1a ff 	U..%`..((....
00004080	2020-01-03 18:39:33,9781476	+0,0478956	IRP_MJ_READ	UP	0x00000102	55 aa 07 25 60 05 04 28 28 00 00 1a ff 55 aa 0b 28 6d 09 00 …	U..%`..((....U..(m..…
00004082	2020-01-03 18:39:34,0021509	+0,0238432	IRP_MJ_READ	UP	0x00000102	55 aa 09 27 63 07 06 28 28 00 00 80 04 8b fe 	U..'c..((......
00004084	2020-01-03 18:39:34,0501456	+0,0478847	IRP_MJ_READ	UP	0x00000102	55 aa 07 25 64 1f 1c 03 28 28 00 e1 fe 55 aa 1e 3f 1d 06 78 …	U..%d...((...U..?..x…
00004086	2020-01-03 18:39:34,1221502	+0,0718928	IRP_MJ_READ	UP	0x00000102	55 aa 07 25 60 05 04 28 28 00 00 1a ff 55 aa 0b 28 6d 09 00 …	U..%`..((....U..(m..…
00004088	2020-01-03 18:39:34,1459457	+0,0236779	IRP_MJ_READ	UP	0x00000102	55 aa 07 25 60 05 04 28 28 00 00 1a ff 	U..%`..((....
00004090	2020-01-03 18:39:34,1953061	+0,0491390	IRP_MJ_READ	UP	0x00000102	55 aa 09 27 63 07 06 28 28 00 00 80 04 8b fe 55 aa 0b 28 6d …	U..'c..((......U..(m…
00004092	2020-01-03 18:39:34,2148385	+0,0194330	IRP_MJ_READ	UP	0x00000102	55 aa 07 25 60 05 04 28 28 00 00 1a ff 	U..%`..((....
00004094	2020-01-03 18:39:34,2909629	+0,0759772	IRP_MJ_READ	UP	0x00000102	55 aa 07 25 64 1f 1c 03 28 28 00 e1 fe 55 aa 1e 3f 1d 06 78 …	U..%d...((...U..?..x…
00004096	2020-01-03 18:39:34,3149644	+0,0238866	IRP_MJ_READ	UP	0x00000102	55 aa 09 27 63 07 06 28 28 00 00 80 04 8b fe 	U..'c..((......
00004098	2020-01-03 18:39:34,3829469	+0,0678273	IRP_MJ_READ	UP	0x00000102	55 aa 07 25 64 e9 10 03 28 28 00 23 fe 55 aa 12 33 11 fc 00 …	U..%d...((.#.U..3...…
00004100	2020-01-03 18:39:34,4149496	+0,0318907	IRP_MJ_READ	UP	0x00000102	55 aa 07 25 60 05 04 28 28 00 00 1a ff 	U..%`..((....
00004102	2020-01-03 18:39:34,4334680	+0,0183658	IRP_MJ_READ	UP	0x00000102	55 aa 07 25 60 05 04 28 28 00 00 1a ff 	U..%`..((....
00004104	2020-01-03 18:39:34,4814570	+0,0478790	IRP_MJ_READ	UP	0x00000102	55 aa 09 27 63 07 06 28 28 00 00 80 04 8b fe 55 aa 0b 28 6d …	U..'c..((......U..(m…
00004106	2020-01-03 18:39:34,5094611	+0,0278923	IRP_MJ_READ	UP	0x00000102	55 aa 07 25 60 05 04 28 28 00 00 1a ff 	U..%`..((....
00004108	2020-01-03 18:39:34,5294696	+0,0198995	IRP_MJ_READ	UP	0x00000102	55 aa 07 25 60 05 04 28 28 00 00 1a ff 	U..%`..((....
00004110	2020-01-03 18:39:34,5843933	+0,0548141	IRP_MJ_READ	UP	0x00000102	55 aa 07 25 64 1f 1c 03 28 28 00 e1 fe 55 aa 1e 3f 1d 06 78 …	U..%d...((...U..?..x…
00004112	2020-01-03 18:39:34,6004233	+0,0159174	IRP_MJ_READ	UP	0x00000102	55 aa 09 27 63 07 06 28 28 00 00 80 04 8b fe 	U..'c..((......
00004114	2020-01-03 18:39:34,6284205	+0,0278394	IRP_MJ_READ	UP	0x00000102	55 aa 07 25 60 05 04 28 28 00 00 1a ff 	U..%`..((....
00004116	2020-01-03 18:39:34,6743170	+0,0457312	IRP_MJ_READ	UP	0x00000102	55 aa 07 25 60 05 04 28 28 00 00 1a ff 55 aa 0b 28 6d 09 00 …	U..%`..((....U..(m..…
00004118	2020-01-03 18:39:34,7223197	+0,0478894	IRP_MJ_READ	UP	0x00000102	55 aa 07 25 64 7e 12 03 28 28 00 8c fe 55 aa 14 31 13 69 00 …	U..%d~..((...U..1.i.…
00004120	2020-01-03 18:39:34,7476191	+0,0251896	IRP_MJ_READ	UP	0x00000102	55 aa 09 27 63 07 06 28 28 00 00 80 04 8b fe 	U..'c..((......
00004122	2020-01-03 18:39:34,8438697	+0,0961337	IRP_MJ_READ	UP	0x00000102	55 aa 07 25 60 05 04 28 28 00 00 1a ff 55 aa 0b 28 6d 09 00 …	U..%`..((....U..(m..…
00004124	2020-01-03 18:39:34,8937772	+0,0497401	IRP_MJ_READ	UP	0x00000102	55 aa 07 25 64 e9 10 03 28 28 00 23 fe 55 aa 0b 28 6d 09 00 …	U..%d...((.#.U..(m..…
00004126	2020-01-03 18:39:34,9405747	+0,0466340	IRP_MJ_READ	UP	0x00000102	55 aa 09 27 63 07 06 28 28 00 00 80 04 8b fe 55 aa 07 25 60 …	U..'c..((......U..%`…
00004128	2020-01-03 18:39:35,2770368	+0,3363038	IRP_MJ_READ	UP	0x00000102	55 aa 07 25 64 7e 12 03 28 28 00 8c fe 55 aa 14 31 13 69 00 …	U..%d~..((...U..1.i.…
00004130	2020-01-03 18:39:35,3753782	+0,0981710	IRP_MJ_READ	UP	0x00000102	55 aa 07 25 60 05 04 28 28 00 00 1a ff 55 aa 07 25 64 1f 1c …	U..%`..((....U..%d..…
00004132	2020-01-03 18:39:35,3956785	+0,0201841	IRP_MJ_READ	UP	0x00000102	55 aa 07 25 60 05 04 28 28 00 00 1a ff 	U..%`..((....
00004134	2020-01-03 18:39:35,4156213	+0,0198277	IRP_MJ_READ	UP	0x00000102	55 aa 07 25 60 05 04 28 28 00 00 1a ff 	U..%`..((....
00004136	2020-01-03 18:39:35,4436196	+0,0278297	IRP_MJ_READ	UP	0x00000102	55 aa 07 25 60 05 04 28 28 00 00 1a ff 	U..%`..((....
00004138	2020-01-03 18:39:35,4916197	+0,0478872	IRP_MJ_READ	UP	0x00000102	55 aa 07 25 64 e9 10 03 28 28 00 23 fe 55 aa 0b 28 6d 09 00 …	U..%d...((.#.U..(m..…
00004140	2020-01-03 18:39:35,5116396	+0,0199100	IRP_MJ_READ	UP	0x00000102	55 aa 07 25 60 05 04 28 28 00 00 1a ff 	U..%`..((....
00004142	2020-01-03 18:39:35,5356257	+0,0238504	IRP_MJ_READ	UP	0x00000102	55 aa 07 25 60 05 04 28 28 00 00 1a ff 	U..%`..((....
00004144	2020-01-03 18:39:35,5836254	+0,0478712	IRP_MJ_READ	UP	0x00000102	55 aa 07 25 60 05 04 28 28 00 00 1a ff 55 aa 0b 28 6d 09 00 …	U..%`..((....U..(m..…
00004146	2020-01-03 18:39:35,6158468	+0,0320468	IRP_MJ_READ	UP	0x00000102	55 aa 09 27 63 07 06 28 28 00 00 80 04 8b fe 	U..'c..((......
00004148	2020-01-03 18:39:35,6372722	+0,0213130	IRP_MJ_READ	UP	0x00000102	55 aa 07 25 60 05 04 28 28 00 00 1a ff 	U..%`..((....
00004150	2020-01-03 18:39:35,7022600	+0,0648758	IRP_MJ_READ	UP	0x00000102	55 aa 07 25 60 05 04 28 28 00 00 1a ff 55 aa 0b 28 6d 09 00 …	U..%`..((....U..(m..…
00004152	2020-01-03 18:39:35,7302533	+0,0278828	IRP_MJ_READ	UP	0x00000102	55 aa 07 25 60 05 04 28 28 00 00 1a ff 	U..%`..((....
00004154	2020-01-03 18:39:35,8038289	+0,0734648	IRP_MJ_READ	UP	0x00000102	fe 69 00 00 01 00 00 00 00 00 00 00 00 00 78 80 00 00 00 00 …	.i............x.....…
00004156	2020-01-03 18:39:35,8278306	+0,0238899	IRP_MJ_READ	UP	0x00000102	55 aa 07 25 60 05 04 28 28 00 00 1a ff 	U..%`..((....
00004158	2020-01-03 18:39:35,8718557	+0,0439135	IRP_MJ_READ	UP	0x00000102	55 aa 07 25 60 05 04 28 28 00 00 1a ff 55 aa 0b 28 6d 09 00 …	U..%`..((....U..(m..…
00004160	2020-01-03 18:39:35,9196418	+0,0476772	IRP_MJ_READ	UP	0x00000102	55 aa 07 25 64 1f 1c 03 28 28 00 e1 fe 55 aa 1e 3f 1d 06 78 …	U..%d...((...U..?..x…
00004162	2020-01-03 18:39:35,9718342	+0,0520849	IRP_MJ_READ	UP	0x00000102	55 aa 07 25 60 05 04 28 28 00 00 1a ff 55 aa 0b 28 6d 09 00 …	U..%`..((....U..(m..…
00004164	2020-01-03 18:39:35,9958344	+0,0238791	IRP_MJ_READ	UP	0x00000102	55 aa 07 25 60 05 04 28 28 00 00 1a ff 	U..%`..((....
00004166	2020-01-03 18:39:36,0158323	+0,0198813	IRP_MJ_READ	UP	0x00000102	55 aa 07 25 60 05 04 28 28 00 00 1a ff 	U..%`..((....
00004168	2020-01-03 18:39:36,0398409	+0,0238934	IRP_MJ_READ	UP	0x00000102	55 aa 09 27 63 07 06 28 28 00 00 80 04 8b fe 	U..'c..((......
00004170	2020-01-03 18:39:36,0878350	+0,0478271	IRP_MJ_READ	UP	0x00000102	55 aa 07 25 60 05 04 28 28 00 00 1a ff 55 aa 0b 28 6d 09 00 …	U..%`..((....U..(m..…
00004172	2020-01-03 18:39:36,1168822	+0,0289190	IRP_MJ_READ	UP	0x00000102	55 aa 07 25 60 05 04 28 28 00 00 1a ff 	U..%`..((....
00004174	2020-01-03 18:39:36,1353605	+0,0183035	IRP_MJ_READ	UP	0x00000102	55 aa 07 25 60 05 04 28 28 00 00 1a ff 	U..%`..((....
00004176	2020-01-03 18:39:36,1622537	+0,0268561	IRP_MJ_READ	UP	0x00000102	55 aa 09 27 63 07 06 28 28 00 00 80 04 8b fe 	U..'c..((......
00004178	2020-01-03 18:39:36,2102197	+0,0478916	IRP_MJ_READ	UP	0x00000102	55 aa 07 25 60 05 04 28 28 00 00 1a ff 	U..%`..((....
00004180	2020-01-03 18:39:36,2340692	+0,0236721	IRP_MJ_READ	UP	0x00000102	55 aa 07 25 60 05 04 28 28 00 00 1a ff 	U..%`..((....
00004182	2020-01-03 18:39:36,2838728	+0,0496865	IRP_MJ_READ	UP	0x00000102	55 aa 07 25 60 05 04 28 28 00 00 1a ff 55 aa 0b 28 6d 09 00 …	U..%`..((....U..(m..…
00004184	2020-01-03 18:39:36,3078728	+0,0238842	IRP_MJ_READ	UP	0x00000102	55 aa 07 25 60 05 04 28 28 00 00 1a ff 	U..%`..((....
00004186	2020-01-03 18:39:36,3278872	+0,0198975	IRP_MJ_READ	UP	0x00000102	55 aa 07 25 60 05 04 28 28 00 00 1a ff 	U..%`..((....
00004188	2020-01-03 18:39:36,3638897	+0,0358677	IRP_MJ_READ	UP	0x00000102	55 aa 07 25 60 05 04 28 28 00 00 1a ff 55 aa 0b 28 6d 09 00 …	U..%`..((....U..(m..…
00004190	2020-01-03 18:39:36,4505570	+0,0864838	IRP_MJ_READ	UP	0x00000102	55 aa 07 25 60 05 04 28 28 00 00 1a ff 	U..%`..((....
00004192	2020-01-03 18:39:36,6172303	+0,1665588	IRP_MJ_READ	UP	0x00000102	55 aa 07 25 60 05 04 28 28 00 00 1a ff 	U..%`..((....
00004194	2020-01-03 18:39:36,6431721	+0,0258121	IRP_MJ_READ	UP	0x00000102	55 aa 09 27 63 07 06 28 28 00 00 80 04 8b fe 	U..'c..((......
00004196	2020-01-03 18:39:36,6871549	+0,0438021	IRP_MJ_READ	UP	0x00000102	55 aa 07 25 60 05 04 28 28 00 00 1a ff 55 aa 0b 28 6d 09 00 …	U..%`..((....U..(m..…
00004198	2020-01-03 18:39:36,7111701	+0,0239034	IRP_MJ_READ	UP	0x00000102	55 aa 07 25 60 05 04 28 28 00 00 1a ff 	U..%`..((....
00004200	2020-01-03 18:39:36,7351615	+0,0238633	IRP_MJ_READ	UP	0x00000102	55 aa 07 25 60 05 04 28 28 00 00 1a ff 	U..%`..((....
00004202	2020-01-03 18:39:36,7881027	+0,0528092	IRP_MJ_READ	UP	0x00000102	55 aa 09 27 63 07 06 28 28 00 00 80 04 8b fe 55 aa 0b 28 6d …	U..'c..((......U..(m…
00004204	2020-01-03 18:39:36,8123896	+0,0241935	IRP_MJ_READ	UP	0x00000102	55 aa 07 25 60 05 04 28 28 00 00 1a ff 	U..%`..((....
00004206	2020-01-03 18:39:36,8298681	+0,0174156	IRP_MJ_READ	UP	0x00000102	55 aa 07 25 60 05 04 28 28 00 00 1a ff 	U..%`..((....
00004208	2020-01-03 18:39:36,8779464	+0,0480136	IRP_MJ_READ	UP	0x00000102	55 aa 07 25 60 05 04 28 28 00 00 1a ff 55 aa 0b 28 6d 09 00 …	U..%`..((....U..(m..…
00004210	2020-01-03 18:39:36,9058217	+0,0277584	IRP_MJ_READ	UP	0x00000102	55 aa 07 25 60 05 04 28 28 00 00 1a ff 	U..%`..((....
00004212	2020-01-03 18:39:36,9300241	+0,0240882	IRP_MJ_READ	UP	0x00000102	55 aa 07 25 60 05 04 28 28 00 00 1a ff 	U..%`..((....
00004214	2020-01-03 18:39:36,9780453	+0,0479104	IRP_MJ_READ	UP	0x00000102	55 aa 07 25 60 05 04 28 28 00 00 1a ff 55 aa 0b 28 6d 09 00 …	U..%`..((....U..(m..…
00004216	2020-01-03 18:39:36,9980367	+0,0198621	IRP_MJ_READ	UP	0x00000102	55 aa 09 27 63 07 06 28 28 00 00 80 04 8b fe 	U..'c..((......
00004218	2020-01-03 18:39:37,0220296	+0,0238354	IRP_MJ_READ	UP	0x00000102	55 aa 07 25 60 05 04 28 28 00 00 1a ff 	U..%`..((....
00004220	2020-01-03 18:39:37,0740283	+0,0518896	IRP_MJ_READ	UP	0x00000102	55 aa 07 25 60 05 04 28 28 00 00 1a ff 55 aa 0b 28 6d 09 00 …	U..%`..((....U..(m..…
00004222	2020-01-03 18:39:37,0980481	+0,0239081	IRP_MJ_READ	UP	0x00000102	55 aa 07 25 60 05 04 28 28 00 00 1a ff 	U..%`..((....
00004224	2020-01-03 18:39:37,1220223	+0,0237973	IRP_MJ_READ	UP	0x00000102	55 aa 09 27 63 07 06 28 28 00 00 80 04 8b fe 	U..'c..((......
00004226	2020-01-03 18:39:37,1671469	+0,0450129	IRP_MJ_READ	UP	0x00000102	55 aa 07 25 60 05 04 28 28 00 00 1a ff 55 aa 0b 28 6d 09 00 …	U..%`..((....U..(m..…
00004228	2020-01-03 18:39:37,1896520	+0,0224416	IRP_MJ_READ	UP	0x00000102	55 aa 07 25 60 05 04 28 28 00 00 1a ff 	U..%`..((....
00004230	2020-01-03 18:39:37,2179254	+0,0282049	IRP_MJ_READ	UP	0x00000102	55 aa 07 25 60 05 04 28 28 00 00 1a ff 	U..%`..((....
00004232	2020-01-03 18:39:37,2378970	+0,0198418	IRP_MJ_READ	UP	0x00000102	55 aa 09 27 63 07 06 28 28 00 00 80 04 8b fe 	U..'c..((......
00004234	2020-01-03 18:39:37,2675824	+0,0295739	IRP_MJ_READ	UP	0x00000102	55 aa 0b 28 6d 09 00 03 00 00 00 00 00 00 3b 18 ff 55 aa 07 …	U..(m.........;..U..…
00004236	2020-01-03 18:39:37,2875620	+0,0198256	IRP_MJ_READ	UP	0x00000102	55 aa 07 25 60 05 04 28 28 00 00 1a ff 	U..%`..((....
00004238	2020-01-03 18:39:37,3117200	+0,0240468	IRP_MJ_READ	UP	0x00000102	55 aa 07 25 60 05 04 28 28 00 00 1a ff 	U..%`..((....
00004240	2020-01-03 18:39:37,3357523	+0,0239034	IRP_MJ_READ	UP	0x00000102	55 aa 07 25 60 05 04 28 28 00 00 1a ff 	U..%`..((....
00004242	2020-01-03 18:39:37,3827153	+0,0468244	IRP_MJ_READ	UP	0x00000102	55 aa 09 27 63 07 06 28 28 00 00 80 04 8b fe 55 aa 0b 28 6d …	U..'c..((......U..(m…
00004244	2020-01-03 18:39:37,5027443	+0,1199175	IRP_MJ_READ	UP	0x00000102	55 aa 07 25 60 05 04 28 28 00 00 1a ff 	U..%`..((....
00004246	2020-01-03 18:39:37,5267526	+0,0238777	IRP_MJ_READ	UP	0x00000102	55 aa 07 25 60 05 04 28 28 00 00 1a ff 	U..%`..((....
00004248	2020-01-03 18:39:37,5587478	+0,0318661	IRP_MJ_READ	UP	0x00000102	55 aa 07 25 60 05 04 28 28 00 00 1a ff 55 aa 0b 28 6d 09 00 …	U..%`..((....U..(m..…
00004250	2020-01-03 18:39:37,5747536	+0,0158755	IRP_MJ_READ	UP	0x00000102	55 aa 07 25 60 05 04 28 28 00 00 1a ff 	U..%`..((....
00004252	2020-01-03 18:39:37,5987529	+0,0238705	IRP_MJ_READ	UP	0x00000102	55 aa 09 27 63 07 06 28 28 00 00 80 04 8b fe 	U..'c..((......
00004254	2020-01-03 18:39:37,6679906	+0,0690600	IRP_MJ_READ	UP	0x00000102	55 aa 07 25 60 05 04 28 28 00 00 1a ff 7f aa 0b 28 6d 09 00 …	U..%`..((......(m..…
00004256	2020-01-03 18:39:37,6972596	+0,0292337	IRP_MJ_READ	UP	0x00000102	55 aa 07 25 60 05 04 28 28 00 00 1a ff 	U..%`..((....
00004258	2020-01-03 18:39:37,7176125	+0,0200471	IRP_MJ_READ	UP	0x00000102	55 aa 09 27 63 07 06 28 28 00 00 80 04 8b fe 	U..'c..((......
00004260	2020-01-03 18:39:37,7696170	+0,0518953	IRP_MJ_READ	UP	0x00000102	55 aa 07 25 60 05 04 28 28 00 00 1a ff 55 aa 0b 28 6d 09 00 …	U..%`..((....U..(m..…
00004262	2020-01-03 18:39:37,7917738	+0,0220406	IRP_MJ_READ	UP	0x00000102	55 aa 07 25 60 05 04 28 28 00 00 1a ff 	U..%`..((....
00004264	2020-01-03 18:39:37,8117573	+0,0198206	IRP_MJ_READ	UP	0x00000102	55 aa 07 25 60 05 04 28 28 00 00 1a ff 	U..%`..((....
00004266	2020-01-03 18:39:37,8637808	+0,0519122	IRP_MJ_READ	UP	0x00000102	55 aa 09 27 63 07 06 28 28 00 00 80 04 8b fe 55 aa 0b 28 6d …	U..'c..((......U..(m…
00004268	2020-01-03 18:39:37,8877526	+0,0237973	IRP_MJ_READ	UP	0x00000102	55 aa 07 25 60 05 04 28 28 00 00 1a ff 	U..%`..((....
00004270	2020-01-03 18:39:37,9117786	+0,0238969	IRP_MJ_READ	UP	0x00000102	55 aa 07 25 60 05 04 28 28 00 00 1a ff 	U..%`..((....
00004272	2020-01-03 18:39:37,9369357	+0,0250244	IRP_MJ_READ	UP	0x00000102	55 aa 07 25 60 05 04 28 28 00 00 1a ff 	U..%`..((....
00004274	2020-01-03 18:39:37,9809390	+0,0438744	IRP_MJ_READ	UP	0x00000102	55 aa 09 27 63 07 06 28 28 00 00 80 04 8b fe 55 aa 0b 28 6d …	U..'c..((......U..(m…
00004276	2020-01-03 18:39:38,0089386	+0,0278736	IRP_MJ_READ	UP	0x00000102	55 aa 07 25 60 05 04 28 28 00 00 1a ff 	U..%`..((....
00004278	2020-01-03 18:39:38,0289370	+0,0198689	IRP_MJ_READ	UP	0x00000102	55 aa 07 25 60 05 04 28 28 00 00 1a ff 	U..%`..((....
00004280	2020-01-03 18:39:38,0649384	+0,0358384	IRP_MJ_READ	UP	0x00000102	55 aa 07 25 60 05 04 28 28 00 00 1a ff 55 aa 0b 28 6d 09 00 …	U..%`..((....U..(m..…
00004282	2020-01-03 18:39:38,0809268	+0,0158582	IRP_MJ_READ	UP	0x00000102	55 aa 09 27 63 07 06 28 28 00 00 80 04 8b fe 	U..'c..((......
00004284	2020-01-03 18:39:38,1049227	+0,0238689	IRP_MJ_READ	UP	0x00000102	55 aa 07 25 60 05 04 28 28 00 00 1a ff 	U..%`..((....
00004286	2020-01-03 18:39:38,1289271	+0,0238547	IRP_MJ_READ	UP	0x00000102	55 aa 07 25 60 05 04 28 28 00 00 1a ff 	U..%`..((....
00004288	2020-01-03 18:39:38,1728962	+0,0438590	IRP_MJ_READ	UP	0x00000102	55 aa 07 25 60 05 04 28 28 00 00 1a ff 55 aa 0b 28 6d 09 00 …	U..%`..((....U..(m..…
00004290	2020-01-03 18:39:38,1966587	+0,0236521	IRP_MJ_READ	UP	0x00000102	55 aa 09 27 63 07 06 28 28 00 00 80 04 8b fe 	U..'c..((......
00004292	2020-01-03 18:39:38,2237516	+0,0270055	IRP_MJ_READ	UP	0x00000102	55 aa 07 25 60 05 04 28 28 00 00 1a ff 	U..%`..((....
00004294	2020-01-03 18:39:38,2737275	+0,0498792	IRP_MJ_READ	UP	0x00000102	55 aa 07 25 60 05 04 28 28 00 00 1a ff 55 aa 0b 28 6d 09 00 …	U..%`..((....U..(m..…
00004296	2020-01-03 18:39:38,2976756	+0,0238395	IRP_MJ_READ	UP	0x00000102	55 aa 07 25 60 05 04 28 28 00 00 1a ff 	U..%`..((....
00004298	2020-01-03 18:39:38,3177316	+0,0199268	IRP_MJ_READ	UP	0x00000102	55 aa 09 27 63 07 06 28 28 00 00 80 04 8b fe 	U..'c..((......
00004300	2020-01-03 18:39:38,3657384	+0,0478784	IRP_MJ_READ	UP	0x00000102	55 aa 07 25 60 05 04 28 28 00 00 1a ff 55 aa 0b 28 6d 09 00 …	U..%`..((....U..(m..…
00004302	2020-01-03 18:39:38,4875633	+0,1216941	IRP_MJ_READ	UP	0x00000102	55 aa 07 25 60 05 04 28 28 00 00 1a ff 55 aa 07 25 60 05 04 …	U..%`..((....U..%`..…
00004304	2020-01-03 18:39:38,5188660	+0,0311922	IRP_MJ_READ	UP	0x00000102	55 aa 07 25 60 05 04 28 28 00 00 1a ff 	U..%`..((....
00004306	2020-01-03 18:39:38,5657262	+0,0467087	IRP_MJ_READ	UP	0x00000102	55 aa 07 25 60 05 04 28 28 00 00 1a ff 55 aa 0b 28 6d 09 00 …	U..%`..((....U..(m..…
00004308	2020-01-03 18:39:38,7301829	+0,1642993	IRP_MJ_READ	UP	0x00000102	55 aa 07 25 60 05 04 28 28 00 00 1a ff 55 aa 07 25 60 05 04 …	U..%`..((....U..%`..…
00004310	2020-01-03 18:39:38,7803180	+0,0500115	IRP_MJ_READ	UP	0x00000102	55 aa 07 25 60 05 04 28 28 00 00 1a ff 55 aa 0b 28 6d 09 00 …	U..%`..((....U..(m..…
00004312	2020-01-03 18:39:38,8292039	+0,0487341	IRP_MJ_READ	UP	0x00000102	55 aa 09 27 63 07 06 28 28 00 00 80 04 8b fe 55 aa 07 25 60 …	U..'c..((......U..%`…
00004314	2020-01-03 18:39:38,8781415	+0,0488055	IRP_MJ_READ	UP	0x00000102	55 aa 07 25 60 05 04 28 28 00 00 1a ff 55 aa 0b 28 6d 09 00 …	U..%`..((....U..(m..…
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

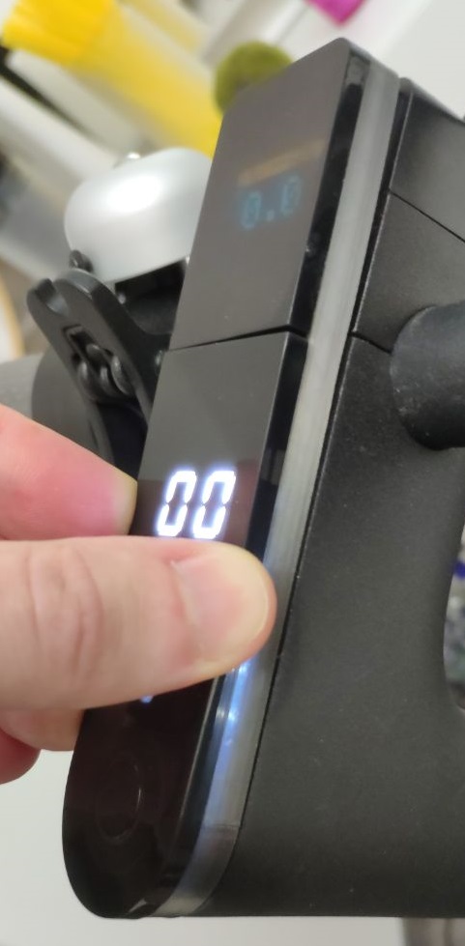
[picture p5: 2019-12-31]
img/v1_2.jpg

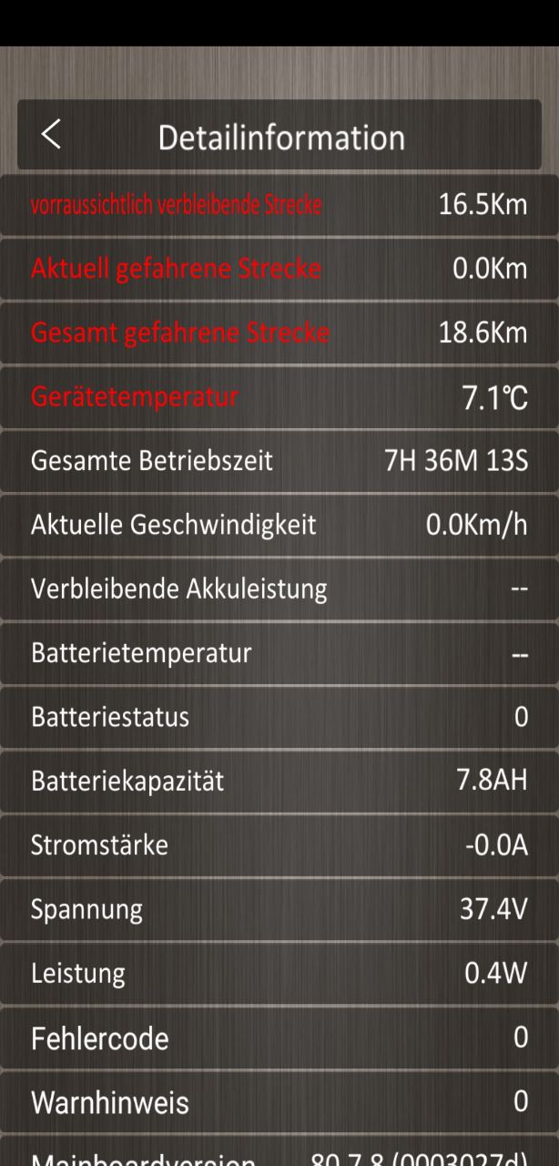
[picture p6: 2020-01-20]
serial/02_1_before.jpg

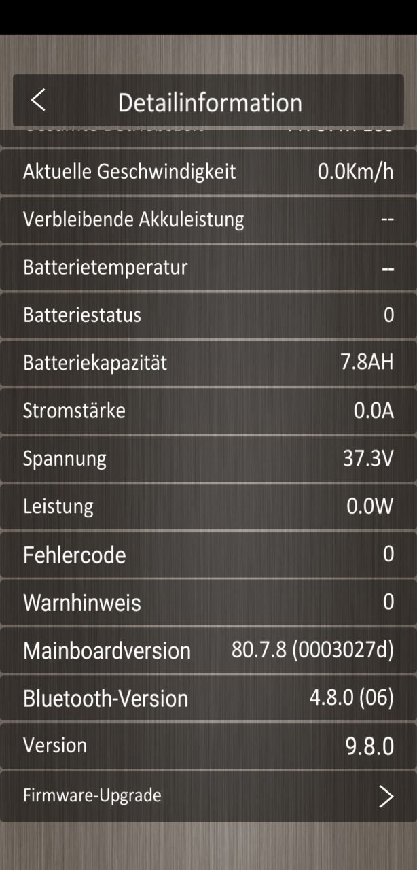
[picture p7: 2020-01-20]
serial/02_4_after.jpg

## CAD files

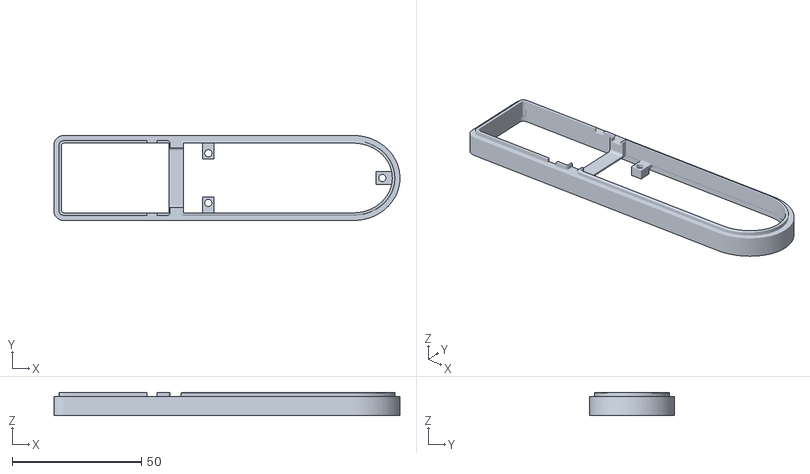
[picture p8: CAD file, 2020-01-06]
3D/spacer_with_dashbord_mount.stl
134.1 x 33.0 x 9.00

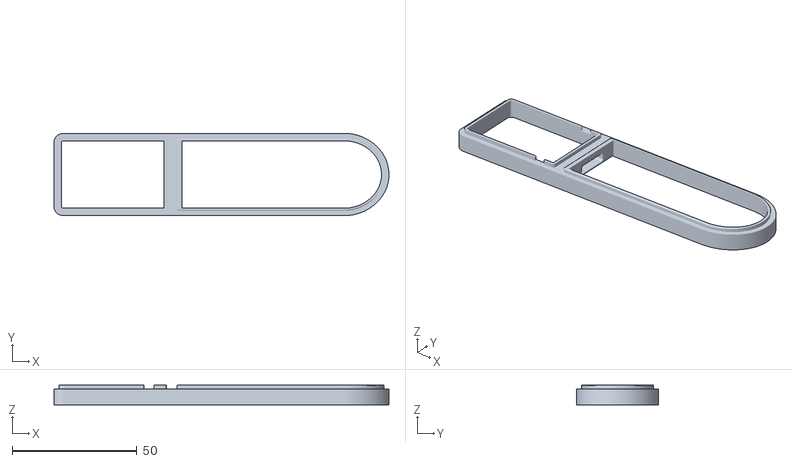
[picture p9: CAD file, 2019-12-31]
3D/v1_not_best_fit.stl
134.1 x 33.0 x 8.00

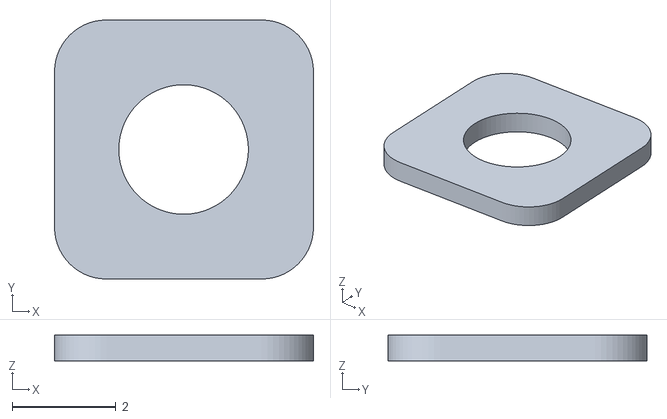
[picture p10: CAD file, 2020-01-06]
3D/0_5mmScrewSpacer.stl
5.00 x 5.00 x 0.5

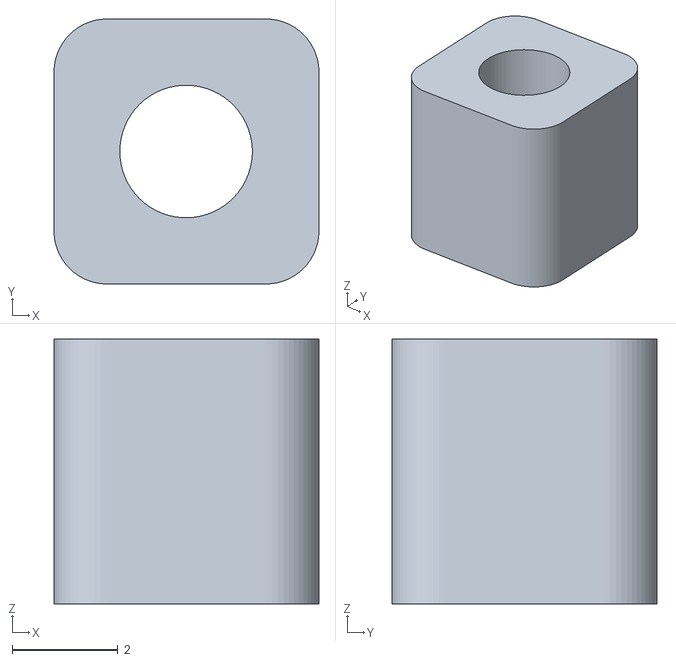
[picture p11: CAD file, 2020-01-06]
3D/5mmScrewSpacer.stl
5.00 x 5.00 x 5.00

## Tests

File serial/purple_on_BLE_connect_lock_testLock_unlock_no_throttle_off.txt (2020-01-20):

FF
55AA07256005042829000019FF
55AA07256005042829000019FF
55AA07256005042829000019FF
55AA07256005042829000019FF
55AA09276307062829000080048AFE
55AA07256005042829000019FF
55AA07256005042829000019FF
55AA07256005042829000019FF
55AA07256005042829000019FF
55AA09276307062829000080048AFE
55AA07256005042829000019FF
55AA07256005042829000019FF
55AA07256005042829000019FF
55AA07256005042829000019FF
55AA09276307062829000080048AFE
55AA07256005042829000019FF
55AA07256005042829000019FF
55AA07256005042829000019FF
55AA07256005042829000019FF
55AA09276307062829000080048AFE
55AA07256005042829000019FF
55AA07256005042829000019FF
55AA07256005042829000019FF
55AA07256005042829000019FF
55AA09276307062829000080048AFE
55AA07256005042829000019FF
55AA07256005042829000019FF
55AA07256005042829000019FF
55AA07256005042829000019FF
55AA09276307062829000080048AFE
55AA07256005042829000019FF
55AA07256005042829000019FF
55AA07256005042829000019FF
55AA07256005042829000019FF
55AA09276307062829000080048AFE
55AA07256005042829000019FF
55AA07256005042829000019FF
55AA07256005042829000019FF
55AA07256005042829000019FF
55AA09276307062829000080048AFE
55AA07256005042829000019FF
55AA07256005042829000019FF
55AA07256005042829000019FF
55AA07256005042829000019FF
55AA09276307062829000080048AFE
55AA07256005042829000019FF
55AA07256005042829000019FF
55AA07256005042829000019FF
55AA07256005042829000019FF
55AA09276307062829000080048AFE
55AA07256005042829000019FF
55AA07256005042829000019FF
55AA07256005042829000019FF
55AA07256005042829000019FF
55AA09276307062829000080048AFE
55AA07256005042829000019FF
55AA07256005042829000019FF
55AA07256005042829000019FF
55AA0B286D090003000000000000371CFF
55AA06F406301C8118B565FD
55AA07256005042829000019FF
55AA09276307062829000080048AFE
55AA07256005042829000019FF
55AA0B286D090003000000000000371CFF
55AA07256005042829000019FF
55AA07256005042829000019FF
55AA07256005042829000019FF
55AA09276307062829000080048AFE
55AA0B286D090003000000000000371CFF
55AA07256005042829000019FF
55AA07256005042829000019FF
55AA07256005042829000019FF
55AA07256005042829000019FF
55AA0B286D090003000000000000371CFF
55AA09276307062829000080048AFE
55AA07256005042829000019FF
55AA07256005042829000019FF
55AA07256005042829000019FF
55AA0B286D090003000000000000371CFF
55AA07256005042829000019FF
55AA09276307062829000080048AFE
55AA07256005042829000019FF
55AA07256005042829000019FF
55AA0B286D090003000000000000371CFF
55AA07256005042829000019FF
55AA07256005042829000019FF
55AA09276307062829000080048AFE
55AA07256005042829000019FF
55AA0B286D090003000000000000371CFF
55AA07256005042829000019FF
55AA07256005042829000019FF
55AA07256005042829000019FF
55AA09276307062829000080048AFE
55AA07256005042829000019FF
55AA0B286D090003000000000000371CFF
55AA07256005042829000019FF
55AA07256005042829000019FF
55AA07256005042829000019FF
55AA09276307062829000080048AFE
55AA0B286D090003000000000000371CFF
55AA07256005042829000019FF
55AA07256005042829000019FF
55AA07256005042829000019FF
55AA07256005042829000019FF
55AA0B286D090003000000000000371CFF
55AA09276307062829000080048AFE
55AA07256005042829000019FF
55AA07256005042829000019FF
55AA07256005042829000019FF
55AA0B286D090003000000000000371CFF
55AA07256005042829000019FF
55AA09276307062829000080048AFE
55AA07256005042829000019FF
55AA07256005042829000019FF
55AA0B286D090003000000000000371CFF
55AA07256005042829000019FF
55AA07256005042829000019FF
55AA09276307062829000080048AFE
55AA07256005042829000019FF
55AA0B286D090003000000000000371CFF
55AA07256005042829000019FF
55AA07256005042829000019FF
55AA07256005042829000019FF
55AA09276307062829000080048AFE
55AA0B286D090003000000000000371CFF
55AA07256005042829000019FF
55AA07256005042829000019FF
55AA07256005042829000019FF
55AA07256005042829000019FF
55AA09276307062829000080048AFE
55AA0B286D090003000000000000371CFF
55AA07256005042829000019FF
55AA07256005042829000019FF
55AA07256005042829000019FF
55AA07256005042829000019FF
55AA0B286D090003000000000000371CFF
55AA09276307062829000080048AFE
55AA07256005042829000019FF
55AA07256005042829000019FF
55AA07256005042829000019FF
55AA0B286D090003000000000000371CFF
55AA07256005042829000019FF
55AA09276307062829000080048AFE
55AA07256005042829000019FF
55AA07256005042829000019FF
55AA0B286D090003000000000000371CFF
55AA07256005042829000019FF
55AA07256005042829000019FF
55AA09276307062829000080048AFE
55AA07256005042829000019FF
55AA0B286D090003000000000000371CFF
55AA07256005042829000019FF
55AA07256005042829000019FF
55AA07256005042829000019FF
55AA09276307062829000080048AFE
55AA0B286D090003000000000000371CFF
55AA07256005042829000019FF
55AA07256005042829000019FF
55AA07256005042829000019FF
55AA07256005042829000019FF
55AA0B286D090003000000000000371CFF
55AA09276307062829000080048AFE
55AA07256005042829000019FF
55AA07256005042829000019FF
55AA07256005042829000019FF
55AA07256005042829000019FF
55AA0B286D090003000000000000371CFF
55AA09276307062829000080048AFE
55AA07256005042829000019FF
55AA07256005042829000019FF
55AA07256005042829000019FF
55AA0B286D090003000000000000371CFF
55AA07256005042829000019FF
55AA09276307062829000080048AFE
55AA07256005042829000019FF
55AA07256005042829000019FF
55AA0B286D090003000000000000371CFF
55AA07256005042829000019FF
55AA07256005042829000019FF
55AA09276307062829000080048AFE
55AA07256005042829000019FF
55AA0B286D090003000000000000371CFF
55AA07256005042829000019FF
55AA07256005042829000019FF
55AA07256005042829000019FF
55AA09276307062829000080048AFE
55AA0B286D090003000000000000371CFF
55AA07256005042829000019FF
55AA07256005042829000019FF
55AA07256005042829000019FF
55AA07256005042829000019FF
55AA0B286D090003000000000000371CFF
55AA09276307062829000080048AFE
55AA07256005042829000019FF
55AA07256005042829000019FF
55AA07256005042829000019FF
55AA0B286D090003000000000000371CFF
55AA07256005042829000019FF
55AA09276307062829000080048AFE
55AA07256005042829000019FF
55AA07256005042829000019FF
55AA07256005042829000019FF
55AA0B286D090003000000000000371CFF
55AA07256005042829000019FF
55AA09276307062829000080048AFE
55AA07256005042829000019FF
55AA07256005042829000019FF
55AA0B286D090003000000000000371CFF
55AA07256005042829000019FF
55AA07256005042829000019FF
55AA09276307062829000080048AFE
55AA07256005042829000019FF
55AA0B286D090003000000000000371CFF
55AA07256005042829000019FF
55AA07256005042829000019FF
55AA07256005042829000019FF
55AA09276307062829000080048AFE
55AA0B286D090003000000000000371CFF
55AA07256005042829000019FF
55AA07256005042829000019FF
55AA07256005042829000019FF
55AA07256005042829000019FF
55AA0B286D090003000000000000371CFF
55AA09276307062829000080048AFE
55AA07256005042829000019FF
55AA07256005042829000019FF
55AA07256005042829000019FF
55AA0B286D090003000000000000371CFF
55AA07256005042829000019FF
55AA09276307062829000080048AFE
55AA07256005042829000019FF
55AA07256005042829000019FF
55AA0B286D090003000000000000371CFF
55AA07256005042829000019FF
55AA07256005042829000019FF
55AA09276307062829000080048AFE
55AA07256005042829000019FF
55AA07256005042829000019FF
55AA0B286D090003000000000000371CFF
55AA07256005042829000019FF
55AA07256005042829000019FF
55AA09276307062829000080048AFE
55AA07256005042829000019FF
55AA0B286D090003000000000000371CFF
55AA07256005042829000019FF
55AA07256005042829000019FF
55AA07256005042829000019FF
55AA09276307062829000080048AFE
55AA0B286D090003000000000000371CFF
55AA07256005042829000019FF
55AA07256005042829000019FF
55AA07256005042829000019FF
55AA07256005042829000019FF
55AA0B286D090003000000000000371CFF
55AA09276307062829000080048AFE
55AA07256005042829000019FF
55AA07256005042829000019FF
55AA07256005042829000019FF
55AA0B286D090003000000000000371CFF
55AA07256005042829000019FF
55AA09276307062829000080048AFE
55AA07256005042829000019FF
55AA07256005042829000019FF
55AA0B286D090003000000000000371CFF
55AA07256005042829000019FF
55AA07256005042829000019FF
55AA09276307062829000080048AFE
55AA07256005042829000019FF
55AA07256005042829000019FF
55AA0B286D090003000000000000371CFF
55AA07256005042829000019FF
55AA07256005042829000019FF
55AA09276307062829000080048AFE
55AA07256005042829000019FF
55AA0B286D090003000000000000371CFF
55AA07256005042829000019FF
55AA07256005042829000019FF
55AA07256005042829000019FF
55AA09276307062829000080048AFE
55AA0B286D090003000000000000371CFF
55AA07256005042829000019FF
55AA07256005042829000019FF
55AA07256005042829000019FF
55AA07256005042829000019FF
55AA0B286D090003000000000000371CFF
55AA09276307062829000080048AFE
55AA07256005042829000019FF
55AA07256005042829000019FF
55AA07256005042829000019FF
55AA0B286D090003000000000000371CFF
55AA07256005042829000019FF
55AA09276307062829000080048AFE
55AA07256005042829000019FF
55AA07256005042829000019FF
55AA0B286D090003000000000000371CFF
55AA07256005042829000019FF
55AA07256005042829000019FF
55AA09276307062829000080048AFE
55AA07256005042829000019FF
55AA07256005042829000019FF
55AA0B286D090003000000000000371CFF
55AA07256005042829000019FF
55AA07256005042829000019FF
55AA09276307062829000080048AFE
55AA07256005042829000019FF
55AA0B286D090003000000000000371CFF
55AA07256005042829000019FF
55AA07256005042829000019FF
55AA07256005042829000019FF
55AA09276307062829000080048AFE
55AA0B286D090003000000000000371CFF
55AA07256005042829000019FF
55AA07256005042829000019FF
55AA07256005042829000019FF
55AA07256005042829000019FF
55AA0B286D090003000000000000371CFF
55AA09276307062829000080048AFE
55AA07256005042829000019FF
55AA07256005042829000019FF
55AA07256005042829000019FF
55AA0B286D090003000000000000371CFF
55AA07256005042829000019FF
55AA09276307062829000080048AFE
55AA07256005042829000019FF
55AA07256005042829000019FF
55AA0B286D090003000000000000371CFF
55AA07256005042829000019FF
55AA07256005042829000019FF
55AA09276307062829000080048AFE
55AA07256005042829000019FF
55AA0B286D090003000000000000371CFF
55AA07256005042829000019FF
55AA07256005042829000019FF
55AA07256005042829000019FF
55AA09276307062829000080048AFE
55AA07256005042829000019FF
55AA0B286D090003000000000000371CFF
55AA07256005042829000019FF
55AA07256005042829000019FF
55AA07256005042829000019FF
55AA09276307062829000080048AFE
55AA0B286D090003000000000000371CFF
55AA07256005042829000019FF
55AA07256005042829000019FF
55AA07256005042829000019FF
55AA07256005042829000019FF
55AA0B286D090003000000000000371CFF
55AA09276307062829000080048AFE
55AA07256005042829000019FF
55AA07256005042829000019FF
55AA07256005042829000019FF
55AA0B286D090003000000000000371CFF
55AA07256005042829000019FF
55AA09276307062829000080048AFE
55AA07256005042829000019FF
55AA07256005042829000019FF
55AA0B286D090003000000000000371CFF
55AA07256005042829000019FF
55AA07256005042829000019FF
55AA09276307062829000080048AFE
55AA07256005042829000019FF
55AA0B286D090003000000000000371CFF
55AA07256005042829000019FF
55AA07256005042829000019FF
55AA07256005042829000019FF
55AA09276307062829000080048AFE
55AA07256005042829000019FF
55AA0B286D090003000000000000371CFF
55AA07256005042829000019FF
55AA07256005042829000019FF
55AA07256005042829000019FF
55AA09276307062829000080048AFE
55AA0B286D090003000000000000371CFF
55AA07256005042829000019FF
55AA07256005042829000019FF
55AA07256005042829000019FF
55AA07256005042829000019FF
55AA0B286D090003000000000000371CFF
55AA09276307062829000080048AFE
55AA07256005042829000019FF
55AA07256005042829000019FF
55AA07256005042829000019FF
55AA0B286D090003000000000000371CFF
55AA07256005042829000019FF
55AA09276307062829000080048AFE
55AA07256005042829000019FF
55AA07256005042829000019FF
55AA0B286D090003000000000000371CFF
55AA07256005042829000019FF
55AA07256005042829000019FF
55AA09276307062829000080048AFE
55AA07256005042829000019FF
55AA0B286D090003000000000000371CFF
55AA07256005042829000019FF
55AA07256005042829000019FF
55AA07256005042829000019FF
55AA09276307062829000080048AFE
55AA0B286D090003000000000000371CFF
55AA07256005042829000019FF
55AA07256005042829000019FF
55AA07256005042829000019FF
55AA07256005042829000019FF
55AA09276307062829000080048AFE
55AA0B286D090003000000000000371CFF
55AA07256005042829000019FF
55AA07256005042829000019FF
55AA07256005042829000019FF
55AA07256005042829000019FF
55AA0B286D090003000000000000371CFF
55AA09276307062829000080048AFE
55AA07256005042829000019FF
55AA07256005042829000019FF
55AA07256005042829000019FF
55AA0B286D090003000000000000371CFF
55AA07256005042829000019FF
55AA09276307062829000080048AFE
55AA07256005042829000019FF
55AA07256005042829000019FF
55AA0B286D090003000000000000371CFF
55AA07256005042829000019FF
55AA07256005042829000019FF
55AA09276307062829000080048AFE
55AA07256005042829000019FF
55AA0B286D090003000000000000371CFF
55AA07256005042829000019FF
55AA07256005042829000019FF
55AA07256005042829000019FF
55AA09276307062829000080048AFE
55AA0B286D090003000000000000371CFF
55AA07256005042829000019FF
55AA07256005042829000019FF
55AA07256005042829000019FF
55AA07256005042829000019FF
55AA09276307062829000080048AFE
55AA0B286D090003000000000000371CFF
55AA07256005042829000019FF
55AA07256005042829000019FF
55AA07256005042829000019FF
55AA07256005042829000019FF
55AA0B286D090003000000000000371CFF
55AA09276307062829000080048AFE
55AA07256005042829000019FF
55AA07256005042829000019FF
55AA07256005042829000019FF
55AA0B286D090003000000000000371CFF
55AA07256005042829000019FF
55AA09276307062829000080048AFE
55AA07256005042829000019FF
55AA07256005042829000019FF
55AA0B286D090003000000000000371CFF
55AA07256005042829000019FF
55AA07256005042829000019FF
55AA09276307062829000080048AFE
55AA07256005042829000019FF
55AA0B286D090003000000000000371CFF
55AA07256005042829000019FF
55AA07256005042829000019FF
55AA07256005042829000019FF
55AA09276307062829000080048AFE
55AA0B286D090003000000000000371CFF
55AA07256005042829000019FF
55AA07256005042829000019FF
55AA07256005042829000019FF
55AA07256005042829000019FF
55AA09276307062829000080048AFE
55AA0B286D090003000000000000371CFF
55AA07256005042829000019FF
55AA07256005042829000019FF
55AA07256005042829000019FF
55AA07256005042829000019FF
55AA0B286D090003000000000000371CFF
55AA09276307062829000080048AFE
55AA07256005042829000019FF
55AA07256005042829000019FF
55AA07256005042829000019FF
55AA0B286D090003000000000000371CFF
55AA07256005042829000019FF
55AA09276307062829000080048AFE
55AA07256005042829000019FF
55AA07256005042829000019FF
55AA0B286D090003000000000000371CFF
55AA07256005042829000019FF
55AA07256005042829000019FF
55AA09276307062829000080048AFE
55AA07256005042829000019FF
55AA0B286D090003000000000000371CFF
55AA07256005042829000019FF
55AA07256005042829000019FF
55AA07256005042829000019FF
55AA09276307062829000080048AFE
55AA0B286D090003000000000000371CFF
55AA07256005042829000019FF
55AA07256005042829000019FF
55AA07256005042829000019FF
55AA07256005042829000019FF
55AA09276307062829000080048AFE
55AA0B286D090003000000000000371CFF
55AA07256005042829000019FF
55AA07256005042829000019FF
55AA07256005042829000019FF
55AA07256005042829000019FF
55AA0B286D090003000000000000371CFF
55AA09276307062829000080048AFE
55AA07256005042829000019FF
55AA07256005042829000019FF
55AA07256005042829000019FF
55AA0B286D090003000000000000371CFF
55AA07256005042829000019FF
55AA09276307062829000080048AFE
55AA07256005042829000019FF
55AA07256005042829000019FF
55AA0B286D090003000000000000371CFF
55AA07256005042829000019FF
55AA07256005042829000019FF
55AA09276307062829000080048AFE
55AA07256005042829000019FF
55AA0B286D090003000000000000371CFF
55AA07256005042829000019FF
55AA07256005042829000019FF
55AA07256005042829000019FF
55AA09276307062829000080048AFE
55AA0B286D090003000000000000371CFF
55AA07256005042829000019FF
55AA07256005042829000019FF
55AA07256005042829000019FF
55AA07256005042829000019FF
55AA0B286D090003000000000000371CFF
55AA09276307062829000080048AFE
55AA07256005042829000019FF
55AA07256005042829000019FF
55AA07256005042829000019FF
55AA07256005042829000019FF
55AA0B286D090003000000000000371CFF
55AA09276307062829000080048AFE
55AA07256005042829000019FF
55AA07256005042829000019FF
55AA07256005042829000019FF
55AA0B286D090003000000000000371CFF
55AA07256005042829000019FF
55AA09276307062829000080048AFE
55AA07256005042829000019FF
55AA07256005042829000019FF
55AA0B286D090003000000000000371CFF
55AA07256005042829000019FF
55AA07256005042829000019FF
55AA09276307062829000080048AFE
55AA07256005042829000019FF
55AA0B286D090003000000000000371CFF
55AA07256005042829000019FF
55AA07256005042829000019FF
55AA07256005042829000019FF
55AA09276307062829000080048AFE
55AA0B286D090003000000000000371CFF
55AA07256005042829000019FF
55AA07256005042829000019FF
55AA07256005042829000019FF
55AA07256005042829000019FF
55AA0B286D090003000000000000371CFF
55AA09276307062829000080048AFE
55AA07256005042829000019FF
55AA07256005042829000019FF
55AA07256005042829000019FF
55AA07256005042829000019FF
55AA0B286D090003000000000000371CFF
55AA09276307062829000080048AFE
55AA07256005042829000019FF
55AA07256005042829000019FF
55AA07256005042829000019FF
55AA0B286D090003000000000000371CFF
55AA07256005042829000019FF
55AA09276307062829000080048AFE
55AA07256005042829000019FF
55AA07256005042829000019FF
55AA0B286D090003000000000000371CFF
55AA07256005042829000019FF
55AA07256005042829000019FF
55AA09276307062829000080048AFE
55AA07256005042829000019FF
55AA0B286D090003000000000000371CFF
55AA07256005042829000019FF
55AA07256005042829000019FF
55AA07256005042829000019FF
55AA09276307062829000080048AFE
55AA0B286D090003000000000000371CFF
55AA07256005042829000019FF
55AA07256005042829000019FF
55AA07256005042829000019FF
55AA07256005042829000019FF
55AA0B286D090003000000000000371CFF
55AA09276307062829000080048AFE
55AA07256005042829000019FF
55AA07256005042829000019FF
55AA07256005042829000019FF
55AA07256005042829000019FF
55AA0B286D090003000000000000371CFF
55AA09276307062829000080048AFE
55AA07256005042829000019FF
55AA07256005042829000019FF
55AA07256005042829000019FF
55AA0B286D090003000000000000371CFF
55AA07256005042829000019FF
55AA09276307062829000080048AFE
55AA07256005042829000019FF
55AA07256005042829000019FF
55AA0B286D090003000000000000371CFF
55AA07256005042829000019FF
55AA07256005042829000019FF
55AA09276307062829000080048AFE
55AA07256005042829000019FF
55AA0B286D090003000000000000371CFF
55AA07256005042829000019FF
55AA07256005042829000019FF
55AA07256005042829000019FF
55AA09276307062829000080048AFE
55AA0B286D090003000000000000371CFF
55AA07256005042829000019FF
55AA07256005042829000019FF
55AA07256005042829000019FF
55AA07256005042829000019FF
55AA0B286D090003000000000000371CFF
55AA09276307062829000080048AFE
55AA07256005042829000019FF
55AA07256005042829000019FF
55AA07256005042829000019FF
55AA0B286D090003000000000000371CFF
55AA07256005042829000019FF
55AA09276307062829000080048AFE
55AA07256005042829000019FF
55AA07256005042829000019FF
55AA07256005042829000019FF
55AA0B286D090003000000000000371CFF
55AA07256005042829000019FF
55AA09276307062829000080048AFE
55AA07256005042829000019FF
55AA07256005042829000019FF
55AA0B286D090003000000000000371CFF
55AA07256005042829000019FF
55AA07256005042829000019FF
55AA09276307062829000080048AFE
55AA07256005042829000019FF
55AA0B286D090003000000000000371CFF
55AA07256005042829000019FF
55AA07256005042829000019FF
55AA07256005042829000019FF
55AA09276307062829000080048AFE
55AA0B286D090003000000000000371CFF
55AA072564E9100328290022FE
55AA123311FC00000000E6000000F8017A010000204EE5FB
55AA07256005042829000019FF
55AA07256005042829000019FF
55AA07256005042829000019FF
55AA0B286D090003000000000000371CFF
55AA07256005042829000019FF
55AA09276307062829000080048AFE
55AA0725641F1C03282900E0FE
55AA1E3F1D067880000000007D020300000000000000370000000000000000000000CEFD
55AA072564E8020328290031FE
55AA042103EF0000E8FE
55AA0B286D090003000000000000371CFF
55AA07256005042829000019FF
55AA0725647E12032829008BFE
55AA1431136900000100000000000000000078800000000045FE
55AA07256005042829000019FF
55AA072564E8020328290031FE
55AA042103EF0000E8FE
55AA0B286D090003000000000000371CFF
55AA07256005042829000019FF
55AA07256005042829000019FF
55AA09276307062829000080048AFE
55AA0725641F1C03282900E0FE
55AA1E3F1D067880000000007D020300000000000000370000000000000000000000CEFD
55AA0B286D090003000000000000371CFF
55AA072564E8020328290031FE
55AA042103EF0000E8FE
55AA07256005042829000019FF
55AA072564E9100328290022FE
55AA123311FC00000000E6000000F8017A010000204EE5FB
55AA07256005042829000019FF
55AA07256005042829000019FF
55AA0B286D090003000000000000371CFF
55AA07256005042829000019FF
55AA09276307062829000080048AFE
55AA07256005042829000019FF
55AA07256005042829000019FF
55AA0B286D090003000000000000371CFF
55AA07256005042829000019FF
55AA07256005042829000019FF
55AA09276307062829000080048AFE
55AA0725641F1C03282900E0FE
55AA0B286D090003000000000000371CFF
55AA1E3F1D067880000000007D020300000000000000370000000000000000000000CEFD
55AA07256005042829000019FF
55AA07256005042829000019FF
55AA07256005042829000019FF
55AA0725647E12032829008BFE
55AA1431136900000100000000000000000078800000000045FE
55AA0B286D090003000000000000371CFF
55AA07256005042829000019FF
55AA09276307062829000080048AFE
55AA07256005042829000019FF
55AA07256005042829000019FF
55AA0B286D090003000000000000371CFF
55AA0725641F1C03282900E0FE
55AA1E3F1D067880000000007D020300000000000000370000000000000000000000CEFD
55AA07256005042829000019FF
55AA07256005042829000019FF
55AA09276307062829000080048AFE
55AA0B286D090003000000000000371CFF
55AA072564E9100328290022FE
55AA123311FC00000000E6000000F8017A010000204EE5FB
55AA07256005042829000019FF
55AA07256005042829000019FF
55AA07256005042829000019FF
55AA0B286D090003000000000000371CFF
55AA07256005042829000019FF
55AA09276307062829000080048AFE
55AA07256005042829000019FF
55AA07256005042829000019FF
55AA07256005042829000019FF
55AA0B286D090003000000000000371CFF
55AA0725641F1C03282900E0FE
55AA1E3F1D067880000000007D020300000000000000370000000000000000000000CEFD
55AA07256005042829000019FF
55AA09276307062829000080048AFE
55AA07256005042829000019FF
55AA0B286D090003000000000000371CFF
55AA0725647E12032829008BFE
55AA1431136900000100000000000000000078800000000045FE
55AA07256005042829000019FF
55AA07256005042829000019FF
55AA07256005042829000019FF
55AA0B286D090003000000000000371CFF
55AA0725641F1C03282900E0FE
55AA1E3F1D067880000000007D020300000000000000370000000000000000000000CEFD
55AA09276307062829000080048AFE
55AA07256005042829000019FF
55AA07256005042829000019FF
55AA0B286D090003000000000000371CFF
55AA07256005042829000019FF
55AA07256005042829000019FF
55AA072564E9100328290022FE
55AA123311FC00000000E6000000F8017A010000204EE5FB
55AA09276307062829000080048AFE
55AA0B286D090003000000000000371CFF
55AA07256005042829000019FF
55AA07256005042829000019FF
55AA07256005042829000019FF
55AA07256005042829000019FF
55AA0B286D090003000000000000371CFF
55AA09276307062829000080048AFE
55AA0725641F1C03282900E0FE
55AA1E3F1D067880000000007D020300000000000000370000000000000000000000CEFD
55AA07256005042829000019FF
55AA07256005042829000019FF
55AA07256005042829000019FF
55AA0B286D090003000000000000371CFF
55AA07256005042829000019FF
55AA09276307062829000080048AFE
55AA0725647E12032829008BFE
55AA1431136900000100000000000000000078800000000045FE
55AA07256005042829000019FF
55AA0B286D090003000000000000371CFF
55AA07256005042829000019FF
55AA0725641F1C03282900E0FE
55AA1E3F1D067880000000007D020300000000000000370000000000000000000000CEFD
55AA07256005042829000019FF
55AA07256005042829000019FF
55AA0B286D090003000000000000371CFF
55AA09276307062829000080048AFE
55AA07256005042829000019FF
55AA07256005042829000019FF
55AA072564E9100328290022FE
55AA123311FC00000000E6000000F8017A010000204EE5FB
55AA0B286D090003000000000000371CFF
55AA07256005042829000019FF
55AA07256005042829000019FF
55AA09276307062829000080048AFE
55AA07256005042829000019FF
55AA0B286D090003000000000000371CFF
55AA07256005042829000019FF
55AA07256005042829000019FF
55AA0725641F1C03282900E0FE
55AA1E3F1D067880000000007D020300000000000000370000000000000000000000CEFD
55AA07256005042829000019FF
55AA0B286D090003000000000000371CFF
55AA09276307062829000080048AFE
55AA07256005042829000019FF
55AA07256005042829000019FF
55AA07256005042829000019FF
55AA0B286D090003000000000000371CFF
55AA07256005042829000019FF
55AA09276307062829000080048AFE
55AA0725647E12032829008BFE
55AA1431136900000100000000000000000078800000000045FE
55AA07256005042829000019FF
55AA0725641F1C03282900E0FE
55AA0B286D090003000000000000371CFF
55AA1E3F1D067880000000007D020300000000000000370000000000000000000000CEFD
55AA07256005042829000019FF
55AA07256005042829000019FF
55AA07256005042829000019FF
55AA09276307062829000080048AFE
55AA0B286D090003000000000000371CFF
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

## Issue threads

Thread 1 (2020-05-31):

Keine Anzeige im Oled Display

u-meyer, 2020-05-31:
Hallo,
erstmal finde ich es ein super Projekt .
Ich habe jetzt versucht ein ESP01 zu Flashen und ein Oled Display zu verbinden. Leider zeigt es nichts an. Bin wie in der Beschreibung vorgegangen. Auch den Widerstand habe ich eingelötet. Kann ich auch ohne Anschluss an den Scooter testen ob es funktioniert?

Gruß
Ulf

Bert-Tec, 2020-07-31:
Ja, es sollte auch ohne Verbindung mit dem Scooter zumindest etwas anzeigen. Du kannst mal versuchen die zwei Kabel vom Display (SDA und SCL) zu tauschen. An sonsten läuft das Display mit einem Beispiel code?

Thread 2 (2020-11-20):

Wire.begin() compile issue

janders111, 2020-11-20:
I think Wire.begin(0,2) in xbot_display has to be changed. The documentation for Wire.begin says that the argument must be emtpy, or an address.

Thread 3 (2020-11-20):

Compile issue with Adafruit_CircuitPlayground.h:3:0

janders111, 2020-11-20:
Tried with a few different boards (generic esp8266, pro-mini) , but it always came up with a similar issue. Everything is freshly installed.

`In file included from C:\Program Files (x86)\Arduino\libraries\Adafruit_Circuit_Playground/Adafruit_CircuitPlayground.h:3:0,
                 from sketch\xbot_display_show.h:2,
                 from C:\Users\jorda\Downloads\xbot_display-master\xbot_display\xbot_display.ino:1:
C:\Program Files (x86)\Arduino\libraries\Adafruit_Circuit_Playground/Adafruit_Circuit_Playground.h:114:3: error: 'Adafruit_CPlay_FreeTouch' does not name a type
   Adafruit_CPlay_FreeTouch     cap[7]; ///< the array of capacitive touch sensors
   ^
In file included from C:\Program Files (x86)\Arduino\libraries\Adafruit_Circuit_Playground/Adafruit_CircuitPlayground.h:3:0,
                 from sketch\xbot_display_show.h:2,
                 from sketch\xbot_display_show.cpp:1:
C:\Program Files (x86)\Arduino\libraries\Adafruit_Circuit_Playground/Adafruit_Circuit_Playground.h:114:3: error: 'Adafruit_CPlay_FreeTouch' does not name a type
   Adafruit_CPlay_FreeTouch     cap[7]; ///< the array of capacitive touch sensors
   ^
exit status 1
Error compiling for board Generic ESP8266 Module.
`

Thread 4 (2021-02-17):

Hardware wiring - TX/RX not clear

camp0s, 2021-02-17:
Hi,

You wrote: "Then connect Arduino/ESP(you need a power converter from 5V to 3.3V for ESP) and Display to power and ground.
Then connect serial line to RX pin of Arduino/ESP and using a resistor (for best work a diode) to TX."

So I connect the RX directly to the TR bus, but it's not clear to me how is the wiring to the TX of the Arduino.

Tnx.

ligius-, 2021-04-05:
See https://circuits4you.com/2016/12/16/esp8266-serial-communication/ or search for "ESP8266 to 5V Arduino serial".

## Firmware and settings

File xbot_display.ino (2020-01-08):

#include "xbot_display_show.h"
#include "xbot_display_data.h"

xbot_display_show display;
xbot_display_data scooterData;

bool ESP_01 = true;
unsigned long unlockSpeedTime = 7000;
unsigned long resetSpeedTime = 2000;
unsigned long changeSpeedTimer = 0;
unsigned long changeSpeedTime = unlockSpeedTime;
unsigned long changeModeTimer = 0;
unsigned long changeModeTime = 750;

bool maxSpeed = false;

void setup() 
{
  // delete the whole condition if not using esp
  if(ESP_01)
  {
     Wire.begin(0,2); 
  }
  Serial.begin(115200);
  display.init();
  scooterData.init();
}

void loop() 
{  
  // while more then two bytes are available
  while (Serial.available() >= 2)
  {
    if (Serial.read() == 0x55 && Serial.peek() == 0xAA) 
    {
      // remove 0xAA
      Serial.read();
      if(Serial.peek() == 0x07 || Serial.peek() == 0x09 || Serial.peek() == 0x0B)
      {
        int size = 0;
        switch (Serial.peek())
        {
          case 0x07: size = 0x07 + 4;break;
          case 0x09: size = 0x09 + 4;break;
          case 0x0B: size = 0x0B + 4;break;
          default: break;
        }

        byte readData[size];

        for(int i = 0; i < size; i++)
        {
          readData[i] = Serial.read();        
        }

        if(calculateChecksum(readData) == readData[size-2] + readData[size-1] * 256)
        {
          scooterData.newData(readData);
          display.update(&scooterData);
        }

        // check to set speed = 30
        if(scooterData.throttle_ == 100 && scooterData.break_ == 100 && scooterData.speed_ == 0)
        {
          if(changeSpeedTimer > 0)
          {
            if(millis()-changeSpeedTimer > changeSpeedTime)
            {
              if(maxSpeed)
              {
                maxSpeed = false;
                changeSpeedTime = unlockSpeedTime;
                byte buf[10]={0x55, 0xAA, 0x04, 0x22, 0x01, 0xF2 ,0xF8 ,0x01, 0xED, 0xFD};
                sendData(buf,10);
              }
              else
              {
                maxSpeed = true;
                // set time for reset
                changeSpeedTime = resetSpeedTime;
                byte buf[10]={0x55, 0xAA, 0x04, 0x22, 0x01, 0xF2, 0xF3, 0x02, 0xF1, 0xFD};
                sendData(buf,10);
              }
              scooterData.unlockedSpeed_ = maxSpeed;
              display.update(&scooterData);
              changeSpeedTimer = 0;
            }
          }
          else
          {
            changeSpeedTimer = millis();
          }
        }
        else
        {
          changeSpeedTimer = 0;
        }
        // check to change display mode
        if(scooterData.throttle_ == 100 && scooterData.break_ < 10 && scooterData.speed_ == 0)
        {
          if(changeModeTimer > 0)
          {
            if(millis()-changeModeTimer > changeModeTime)
            {
              display.changeMode();
              display.update(&scooterData);
              changeModeTimer = 0;
            }
          }
          else
          {
            changeModeTimer = millis();
          }
        }
        else
        {
          changeModeTimer = 0;
        }
      }
    }
  }
}

void sendData(byte * data, int len)
{
  Serial.write(data,len);
}

uint16_t calculateChecksum(byte *data)
{
	uint8_t len = data[0] + 2;
	uint16_t sum = 0;
	for(int i = 0; i < len; i++)
  {
		sum += data[i];
  }

	sum ^= 0xFFFF;
	return sum;
}

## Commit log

2019-12-31 added img 3d and edited readme
    [v1_not_best_fit.stl]
2020-01-06 new stl spacer file with mount screw mount for dashboard and spacer
    [spacer_with_dashbord_mount.stl]
2020-01-06 added 3d files of screw spacer
    [0_5mmScrewSpacer.stl, 5mmScrewSpacer.stl]
2020-01-08 bugfixed display speed issue and speed/mode switch isue
    [xbot_display.ino]
